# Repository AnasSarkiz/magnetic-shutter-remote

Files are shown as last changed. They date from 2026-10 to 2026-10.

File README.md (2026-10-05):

# Magnetic shutter remote R8 — ESP32-C3 migration qualification

**Codex Cloud continuation:** use branch `cloud/r8-cloud-setup`; read [cloud setup](cloud/SETUP.md) and the complete [project handoff](cloud/HANDOFF.md). Source, imported models, relevant manufacturer evidence, exact qualified archives and frozen generated Nordic JSON are included. Heavy builds are Linux-only and never started by setup.

Private Cloud environment **magnetic-shutter-remote-r8** is published: choose Work in → Cloud → that environment. Actual hosted setup/smoke passed with10 focused tests; observed32 GiB/4 CPUs. See the [environment record](cloud/ENVIRONMENT-RECORD.json), [current setup status](cloud/STATUS.md) and [continuation prompt](cloud/TASK-PROMPT.md). This local chat does not automatically move to Cloud, and environment readiness does not close board qualification gates.

**COMPONENT QUALIFICATION BLOCKED — NOT FOR FABRICATION.**

User-selected module: Espressif ESP32-C3-WROOM-02-N4 / JLCPCB C2934560. This isolated revision starts from `../magnetic-shutter-remote-r7--01a0f81f`, branch `r7-shutter-only-order-review`, commit `636d2b24eb4db775fceeb81206541f249db3b9a5`. Frozen R6 commit is `77965a8012d5544e962d987ce958c5c5614dbe3a`. Neither previous directory was modified.

The root `index.circuit.tsx`, `src/remote-circuit.tsx`, BOM and mechanical files remain the starting Nordic design. **They are not an implemented ESP32-C3 board.** Building that entry point does not validate R8. No R8 placement, routing, fabrication export or ordering approval exists. No torch is included.

Completed independent work:

- Supported, unchanged JLCPCB imports of the selected module and proposed TPS63031DSKR / C15516 regulator.
- All 19 module pin identities checked against Espressif; all 27 imported pad features match original supplier geometry.
- Isolated native A4 schematic, PCB and 3D import fixture rendered with routing disabled.
- ESP32-C3 Zephyr BLE HID firmware port compiled; valid image checksum verified. GPIO assignment remains proposed until a qualified board exists.
- Five focused qualification tests and TypeScript/format checks; these are not whole-board DFM tests.
- Documented power/battery feasibility and original-revision preservation manifest.

The blocking discrepancy is documented in [issue 075](tscircuit-issues/075-esp32-c3-supplier-lands-differ-from-espressif-recommendation.md): supplier outer lands are approximately 2.0 × 1.0 mm, versus Espressif's recommended 1.5 × 0.9 mm. The importer faithfully preserves them. This is an unqualified supplier variation, not a proven importer scaling bug or a proven assembly failure. Workspace instructions prohibit silently altering the import and require dependent work to stop. [Issue 076](tscircuit-issues/076-numeric-supply-pin-not-inferred-as-power.md) records missing inferred supply metadata separately.

Reproduce independent checks from this directory:

```sh
bun install --frozen-lockfile
python3 scripts/audit-r8-module.py
python3 -m unittest discover -s tests -v
./node_modules/.bin/tsc --noEmit
bun run format:check
./node_modules/.bin/biome format tests/fixtures/esp32-import.circuit.tsx
./node_modules/.bin/tsci build tests/fixtures/esp32-import.circuit.tsx --pcb-png --pcb-svgs --schematic-svgs --3d-png
```

Fixture output: `dist/tests/fixtures/esp32-import/`; this is not a remote-board build. See [VALIDATION.md](VALIDATION.md), [power feasibility](evidence/R8-components/POWER-FEASIBILITY.md) and [firmware instructions](firmware/README.md). Versioned SHA256 manifests identify the independent source/tooling/firmware evidence. Frozen original generated circuit JSON is under `baselines/r7/dist/index/circuit.json` and `baselines/published-main/dist/index/circuit.json`. No validated ESP32 R8 root circuit JSON exists; public board publication remains blocked rather than presenting copied Nordic output as ESP32-C3.

Next gate: independently qualified supported import of the exact selected module, or authoritative qualification of the larger supplier lands. Then complete regulator/passives/harness qualification, power/boot/programming circuitry, enclosure fit, pre-routing checks, routing and manufacturing exports. Physical battery, RF, thermal, runtime, enclosure fit and phone testing remain **POST-PROTOTYPE PHYSICAL VALIDATION**.

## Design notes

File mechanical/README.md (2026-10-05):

# Original remote and grip — R6

This is an original design, not a replacement for JJC internals. Dimensions and provenance are in [dimensions.json](dimensions.json) and [current R6 drawing](../fabrication/R6/BOARD-DIMENSIONS.pdf). The editable OpenSCAD source and seven exported STL part types are included.

PCB: 36 × 56 × 1 mm, R2 corners, two layers, all 37 fitted electronics TOP. Remote body: 40 × 60 × 16.8 mm, R3, 1.2 mm walls; maximum slider width 42.4 mm and button height 17.5 mm. Grip: 68 × 108 mm, R16; base thickness 6.5 mm, overall height with rails 9.8 mm. Docked remote body reaches Z=23.6 mm, buttons Z=24.3; the external steel plate reaches Z=-0.5, so the plate-to-button stack is 24.8 mm. These are compact engineering allocations around qualified parts, not a proven global minimum size.

Board datum: XY centre, +Y toward USB; outer back Z=0, PCB bottom 5 and top 6. Ø2.2 mounting holes are at (±13,24). HCTL USB anchor (0,23.25), 180°, mates +Y. Mouth Y=28.0601694; front opening 12 × 7 at (0,29,8). Its 3.31 mm maximum body height leaves 2.19 mm upper opening clearance at nominal board height. Both plug orientations have independent CC pull-downs. Intended cable plug envelope 10 × 6.5 is an allocation, not a guarantee for every cable.

Battery DTP401525(PHR) maximum 15.5 × 27 × 4.2 lies at X±7.75, Y−5.7…21.3, bottom Z=8.3, maximum top 12.5. Carrier floor Z=7.9…8.3 has thermal and C8 reliefs. Tabs have actual inner faces X±8.3: 0.55 mm side gap, or 0.35 mm after a chosen 0.2 mm printing allowance. Do not clamp the pouch. Carrier position/insulating shims establish the bottom datum after measuring the real pack. C8 max 1.45 mm gives 0.85 mm battery gap; subtracting a 0.3 mm board-height and 0.2 mm carrier allowance leaves 0.35 mm. Other low-profile electronics are below the carrier; nominal model/body reviews are not measured assembly results.

TMP390 maximum top Z=6.6 gives a 1.7 mm sensor-to-cell gap. The external 2.032 mm BERGQUIST pad gives 16.3% nominal compression; contact pressure and thermal lag still require hardware tests. PH mated height 5.5 gives lid gap 4.1; SH mated height 6.3 gives lid gap 3.3. Actual wiring and insertion access are reserved in CAD; J3 is serviced with lid removed. J2 intentionally mates inside the cavity toward −Y, so its generic board-edge orientation warning is accepted.

Shutter/pair switches at (−13.5,−7)/(13.5,−4) have 0.2±0.1 mm stroke, 2 mm nominal height. TPU plunger free gap 0.2 mm, stem 6.6 mm, Ø5.8 cap in Ø6.2 lid hole. Power switch at (15,5), 90°, has 1.6 mm travel and a Ø/width 1.3 actuator captured by a 1.7 mm fork. Button compliance, assembly-height adjustment, force and fatigue are prototype tests.

Remote centre in dock Y=−42, back Z=6.8. The stop was corrected to centre Y=−10.9: actual near face −11.7, 0.30 mm from the remote end −12. Rails inner width 40.6 gives 0.3 mm side gaps. A 0.2 mm print allowance leaves only 0.1 mm, so physical sliding/retention must be checked. Magnet top plus cap is Z=4.675, 0.325 mm below nominal PCB bottom. Two remote and two dock magnets plus four phone magnets are external K&J D42 items, retained with insulating caps/adhesive. Screws and magnet positions avoid the pouch/antenna region.

All-layer no-copper antenna strip: X±18, Y−28…−22.9. Detached battery separation is 17.2 mm; closest reserved wire (radius 0.6) is 16.6 mm. In dock, antenna Y−70…−64.9; permitted phone bottom at Y−35±5 yields 24.9 mm to the nearest phone metal. Fifteen millimetres is our engineering target; Ebyte supplies qualitative metal-clearance guidance, not that numerical rule. Use unfilled nonconductive plastic. Phone alignment and docked/detached RF performance require hardware evidence.

Fit evidence: final STL meshes are manifold/NoError; actual tab/stop surfaces were measured in [mesh evidence](../evidence/R3/final-mechanical-mesh-measurements.json). Native tscircuit PCB/3D, cutaway, docked envelopes and four dimensioned sheets were inspected. No physical battery, swelling, wiring, connector, button, slider, magnet, RF or enclosure test has passed.

R6 USB migration: GCT USB4215-03-A Rev A; anchor(0,23.9852), TOP180°, actual centroid(0,24.5101989). Opening12×9.5atY29/Z8; nominal matingfaceY28.6601694, mouthaxisZ7.48. Manufacturer bodymax9.19×6.75×3.41 and compliant-plug envelope produce calculated worst verticalgap0.08, horizontalgap1.105, shoulder margin0.3601694 and battery-bodygap0.2101694mm. See `../evidence/R6/usb-mechanical-fit.json`; print/PCB/location allowances are engineering allocations, not measured process capability. Current cutaway/docked PNGs and STL base regenerated; other enclosure/rail geometry unchanged. Physical fit remains pending.

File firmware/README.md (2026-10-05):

# R8 ESP32-C3 firmware preparation — compiled, hardware untested

This is a platform adaptation of the R6/R7 Zephyr shutter application for the exact ESP32-C3-WROOM-02-N4. It is **not** an image for the frozen Nordic board. The generated image and ELF are preserved in `artifacts/R8-candidate/`. Hardware footprint qualification is blocked; the pin contract below is proposed, not final routed-board registration. A compiled image is not permission to order or a verified image for an assembled R8 PCB.

The retained BLE HID Consumer Control report sends Volume Increment (`0xE9`), one press followed by release after 60 ms. It retains encrypted notifications, one stored bond, a three-second pairing-button hold, bounded advertising windows, debounce, and disconnect on a stalled release. No queued shot is replayed on reconnect. Wi-Fi and unused development-board interfaces are disabled. No measured connected-sleep current, runtime, or phone compatibility is claimed.

| Function | GPIO | Module physical terminal |
|---|---:|---:|
| Shutter, active low | 4 | 3 |
| Pair, active low | 5 | 4 |
| Red status LED, active high | 6 | 5 |
| UART programming RX | 20 | 11 |
| UART programming TX | 21 | 12 |
| Download strap | 9 | 8 |
| Enable/reset | EN | 2 |

GPIO2 and GPIO8 must be held high for documented download-mode entry; GPIO9 must normally be high and low for download. These are electrical requirements for the future schematic, not connections already implemented here. The planned UART header carries VREF, TX, RX, GND, EN and BOOT; its actual pin order must be frozen with the PCB before programming instructions are approved. A UART adapter must use 3.3 V logic and must not drive battery power. The single USB-C remains the charging port; no second USB port or fill light is added.

The official Zephyr v4.2.0 `esp32c3_devkitc` target includes `esp32c3_wroom_n4.dtsi`. Its preserved definitions are in `../evidence/R8-components/zephyr-v4.2.0/`. The local overlay replaces the development-board GPIO9 button with GPIO4 and adds GPIO5/GPIO6 controls. The exact framework/module commits, source hashes and artifact hashes are in `artifacts/R8-candidate/BUILD-MANIFEST.json`. The build uses Zephyr SDK 0.17.2, RISC-V GCC 12.2.0, CMake 3.31.10, Ninja 1.13.0, west 1.5.0 and Python 3.14.7. Python dependencies are locked in `requirements-lock.txt`. SDK archive hashes are preserved in `sdk-download/sha256.sum` and the component integrity manifest.

Reproduce from the project root:

```sh
python3 -m venv firmware/.venv
firmware/.venv/bin/python -m pip install -r firmware/requirements-lock.txt
git clone --depth 1 --branch v4.2.0 https://github.com/zephyrproject-rtos/zephyr.git firmware/deps/zephyr
firmware/.venv/bin/west init -l firmware/deps/zephyr
cd firmware/deps
../.venv/bin/west update --narrow hal_espressif mbedtls
../.venv/bin/west blobs fetch hal_espressif
cd ../..
PATH="$PWD/firmware/.venv/bin:$PATH" ZEPHYR_SDK_INSTALL_DIR="$PWD/firmware/zephyr-sdk-0.17.2" sh firmware/build.sh --cmake
```

Install the official SDK minimal macOS-arm64 archive plus `riscv64-zephyr-elf` archive into the recorded task-local directory before the build; check both against the SDK release's published SHA256 sums. Do not run SDK registration that changes unrelated user configuration. On another host, select the corresponding official host archive and record its hash.

**Build status: PASS, 2026-10-05.** The final build exits 0 and Espressif esptool v4.8.1 identifies a valid ESP32-C3 image checksum. Image size is 411,568 bytes; linked flash usage is 411,568 bytes, DRAM 129,776 bytes, IRAM 64,016 bytes. Original failed SDK/dependency download/build attempts and the final successful log are preserved under `../evidence/R8-components/`.

The build reports optional external DTC absent; Zephyr's Python devicetree generation succeeds. The bundled esptool emits a Python 3.14 SyntaxWarning for a `return` in `finally`; its image generation and independent image checksum verification succeed. Neither warning was suppressed or patched. Tickless idle is enabled and Wi-Fi is disabled, but CPU power-management and controller sleep are not established for this C3 build. Low-power performance remains an explicit unfinished software/measurement item; do not quote connected-idle or deep-sleep currents from the silicon datasheet as this firmware's measured result.

Acceptance remains native iPhone Camera and representative Android camera testing on identified phone/OS/app versions, including press/release, reconnect, bonding reset and locked-screen behavior. This is **POST-PROTOTYPE PHYSICAL VALIDATION**.

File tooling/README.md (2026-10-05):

# R3 working tooling and reproducible integration

All changes are local and unpublished. The project stays tscircuit source; no KiCad authoring or viewer is required for R3. Exact seven upstream base commits, source versions, changed files, untracked regression fixtures and patches are in [revisions.json](revisions.json). The complete edited sources/locks are included; patches alone omit untracked fixtures, so use supplied source directories as the complete record.

## Working dependency identities

Board Bun 1.3.9; tscircuit 0.0.2702 / CLI 0.1.2212; TS 5.9.3; Biome 2.2.4. Exact dependency graph is in the board lock. Active core is **vendor/tscircuit-core-0.0.2035-r3-attribution.tgz**, together with schema 0.0.509-r2-sheet, util 0.0.117-r2-orientation and capacity autorouter 0.0.951. Installed core bytes match the canonical tested build. Historical archive filenames remain evidence, not active dependencies.

Supported Gerber source converter is 0.0.109 base 40dbb6c0ebae9c63ef5a52292e8521de6060c548 plus the local inline G85/G05 correction. Upstream already fixes M48 header placement. The older CLI-bundled 0.0.104 is not treated as fixed by root overrides; use the explicitly built canonical converter. Its full suite passes 172 tests/1640 assertions after actual TOP/BOTTOM snapshot review, with original snapshots retained. No exported Gerber/drill edits are used.

Native browser evaluation uses eval 0.0.1506-r3-attribution with the same locked source engine, and runframe 0.0.2883 with a matching packaged-worker resolver plus compatible props 0.0.672. The canonical eval build and runframe CSS/standalone targets pass; focused packaged-worker test passes. Other runframe targets/full browser suites are not claimed passed. Corrected standalone min.js is included so the native project viewer does not silently use the old CDN evaluation engine.

## Restore and build

Use `bun install --frozen-lockfile` in each source directory before its canonical build. Local archives in `../vendor/` are already supplied; dependencies may require network. Core's schematic solver archive 0.0.217 is supplied and locked. Run source commands within their own package directory, not workspace root.

```sh
# Board root
bun install --frozen-lockfile
bun run format:check
bun run typecheck
bun run test

# Supported converter (run here to regenerate its dist before exports)
cd tooling/circuit-json-to-gerber
bun install --frozen-lockfile
bun run build
bun test
```

Focused core regression commands from tooling/core (exact tests, before/final logs and fixtures are linked in issues 021–023, 028, 031 and 035):

```sh
bun install --frozen-lockfile
bun test tests/repros/repro-saved-fanout-plated-terminal-bottom.test.tsx tests/repros/repro-saved-fanout-smt-terminal-wrong-layer.test.tsx tests/repros/repro-routed-trace-between-saved-fanouts.test.tsx
node_modules/.bin/tsc --noEmit
bun run build
```

Use actual package scripts in the saved package.json; earlier full-core suite timeouts remain evidence and are not a passed full suite. Meaningful focused tests and builds are passed. No regression was removed or weakened.

To rebuild the native viewer, run eval's full canonical `bun run build` from tooling/eval, then run `bun run build:css` and `bun run build:standalone` from tooling/runframe with its frozen lock. The eval prebuilt archive is already matched to the locked core; a changed build requires a new archive identity and updated lock, never overwriting evidence. From the board root:

```sh
RUNFRAME_STANDALONE_FILE_PATH="$PWD/tooling/runframe/dist/standalone.min.js" node_modules/.bin/tsci dev --port 3026
```

Reload the existing tab after changing the packaged evaluation worker. Watch exclusions omit tools/research/output files, not validation checks. Keep a captured server log outside the watched project to avoid recursive recompilation. Final source viewer PCB and 3D were inspected; PCB shows zero errors.

Importer is supported easyeda-converter 0.0.364 base 140046d000238f3d6c8611989682efb2872f25a9, with validated topology/mating/ref-label/declared-slot fixes. `scripts/regenerate-qualified-imports.sh` preserves original raw payloads and regenerates via its CLI. HCTL import was separately regenerated through that corrected CLI and not edited. Manufacturer geometry, pin mappings and imports remain unchanged.

Independent CAM uses Python 3.14.7 with the pinned `gerber-review-requirements.txt`, including Gerbonara 1.5.0, pcb-tools 0.1.6 and Shapely 2.1.2. Create task-local gerber-review-venv; no virtual environment is archived. Gerbonara's G85 limitation remains, while pcb-tools reads the original exported slots/rounds directly; no syntax normalization is used. OpenSCAD/ReportLab generate mechanical outputs, not electronic symbols or footprints. OpenSCAD needed host execution on this Mac because its sandbox launch aborted; the actual successful native mesh/render logs are saved.

[Current hashes](../evidence/R3/current-source-tooling-hashes.json), [validation scope](../VALIDATION.md), [all local issue reports](../tscircuit-issues/README.md) distinguish project mistakes, supplier deviations, external readers, manufacturing limits and confirmed tscircuit bugs. Archive manifests exclude dependency folders, Git/account metadata and raw signed supplier listing HTML; safe qualified sourcing JSON and original public raw library/footprint inputs remain.

---

# R2 local tooling fixes and reproduction

All changes are local; no packages, commits, issues or PRs were published. `revisions.json` gives upstream commit IDs and changed/new files. Complete editable source directories and binary patches are included; patches alone omit untracked new test files, which are present in those directories. Original R1 supplier imports are under `evidence/R1-original-imports/`.

## Locked packages

Board: Bun 1.3.9, tscircuit 0.0.2702, TypeScript 5.9.3, Biome 2.2.4; exact transitive graph in the board `bun.lock`. Local archives:

- core 0.0.2035 + R2 fixes: `vendor/tscircuit-core-0.0.2035-r2-paste.tgz`.
- circuit-json 0.0.509 + sheet metadata schema: `vendor/circuit-json-0.0.509-r2-sheet.tgz`.
- circuit-json-util 0.0.117 + orientation classification: `vendor/tscircuit-circuit-json-util-0.0.117-r2-orientation.tgz`.
- easyeda-converter 0.0.364 source + R2 supported conversion options and slot fix, with its own lockfile.

Official converters: circuit-json-to-bom-csv 0.0.19, circuit-json-to-pnp-csv 0.0.16 and CLI-bundled circuit-json-to-gerber 0.0.104. These are used directly, with no hand-created fabrication substitutes. Root overrides apply corrected packages consistently. Installed core binary hash was compared with the tested build; see installed-package-hashes.json. Earlier install failures are historical, not accepted install evidence.

## Fixes and regression evidence

- Importer `conversion-options.ts` / CLI: validated SPDT and insertion-direction options. Switch classification excludes thermostats; USB connectors retain original symbols and pin arrangements. No supplier data is rewritten.
- Custom symbol generation includes dynamic reference labels. Core associates reference text outside the symbol's nominal bounds with its true owning component. Repeated physical pads merge correctly with logical custom-symbol ports; port selectors round-trip through the routing cache.
- EasyEDA OVAL drills consume the declared `holeLength` field. Five focused tests cover unequal annular margins, four rotations and circular holes inside oval copper. RECT plated-hole inference is unchanged and is not exercised by fitted parts here.
- Core optional hole fields and display offsets conform to the schema. Sheet display_name/centre metadata survives schema parsing.
- Orientation utility quantizes inferred orientation coordinates at 1 µm for classification only; raw geometry is unchanged. Rotation tests preserve rejection of real 0.01 mm staggering.
- Core no longer creates unrequested stencil apertures on either side of plated holes. Explicit paste primitives remain supported; board shell solder process is not invented.

Importer full suite: 308 pass / 77 snapshots. Schema: 400 pass. Orientation utility: 141 pass. Final core focused regressions: four pass, plus earlier repeated-pad test. Core full suite was not run. Before/after logs and visually reviewed snapshots are in evidence/R2 and the source test directories.

## Build from editable source

Each source directory has its own lockfile. Restore dependencies with `bun install --frozen-lockfile` from that directory, then use its canonical scripts (`bun run build`, `bun test`, `bunx tsc --noEmit`; core uses selected repro tests). Core depends on the task-local `../vendor/schematic-trace-solver-0.0.217.tgz` recorded in its package configuration. Task-local dependency folders were cleared after tests to recover disk space; this does not remove source or locks.

The board uses the supplied prebuilt local archives. To reproduce a modified local build, use `bun pm pack --destination ../vendor` from the package source directory, give the archive a new task-local filename, update the board's dependency/override to that archive, and run `bun install`. Do not overwrite an archive already identified by the evidence manifest or hand-edit installed package files.

From the board root, regenerate affected supplier components with:

```sh
sh scripts/regenerate-qualified-imports.sh
```

This invokes the actual corrected importer CLI against preserved raw supplier payloads. It is not a generated-import patcher. The unchanged passive/module imports remain their original supported imports. Network may be needed for supplier model metadata.

Board build/check/export commands are in the root README, validate-r2.py, export-assembly.ts and fabrication/README.md. The independent Gerber review environment uses `gerber-review-requirements.txt`. Its G85 limitation is explicitly recorded; it never rewrites manufacturing files. OpenSCAD and ReportLab generate mechanical deliverables, not electronic footprints.

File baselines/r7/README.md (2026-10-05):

# Magnetic shutter remote — R7 shutter-only order review

Torch / fill light work is cancelled. The active board remains the proven frozen R6
shutter electronics; no torch circuit is fitted. R6 is untouched.

**Local electrical and CAM checks pass. JLCPCB processed preview must be reviewed before payment.**

Use `index.circuit.tsx`, with generated `dist/index/circuit.json`. Reproduce with
`bun install --frozen-lockfile`, `bun run format:check`, `bun run typecheck` and the
native board build/check commands. See [tooling](tooling/R7-README.md),
[validation](VALIDATION.md), [order review](evidence/R7-order-review/ORDER-READINESS.md),
[current order files](fabrication/R7-order-review/README.md), and
[issue register](tscircuit-issues/README.md).

The complete suite is not claimed passing: one historical preservation failure and one
missing-input skip remain. All original R6 recorded files are unchanged. Physical tests
remain **POST-PROTOTYPE PHYSICAL VALIDATION**. This is an untested engineering prototype,
not production-qualified hardware or a completed shoulder-button enclosure.

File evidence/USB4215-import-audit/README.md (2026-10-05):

# USB4215 replacement qualification — isolated toolchain audit

**USB4215 — BLOCKED. R5 DFM REVIEW — NOT FOR FABRICATION.**

No R6, migration implementation or fabrication-candidate ZIP. All972 protected files remain unchanged (556 R5 +416 R4); previous replacement-search evidence remains unchanged. Physical battery, RF, thermal, runtime, enclosure-fit and phone tests remain **POST-PROTOTYPE PHYSICAL VALIDATION**; those are separate from the open pre-fabrication process requirements.

## Source identity and preserved evidence

GCT / Global Connector Technology USB4215-03-A, JLCPCB/LCSC C37616412. Official drawing/spec revision A, 2024-04-26. Supplier componentUUID 907b9bea7a60481d8a3d3aef3cba8ef1; packageUUID 3104977db58742e399663286e4a66eac, library title USB-C-SMD_GT-USB-7010B. The borrowed title/link is disclosed; supplier import success is not GCT approval. See [identity and hashes](source-identity.json), [unchanged raw source](inputs/C37616412.raweasy.json), [original generated import](inputs/original-import.tsx), [current import](final/USB4215_03_A.tsx) and [frozen-search ledger](frozen-search-ledger.json).

The official drawing's copper/drill qualification is preserved in the [previous search](../USB-replacement-search-2026-10-03/continued-search/README.md); this run does not overwrite it or infer new tolerances. [JLC stock record](stock-2026-10-03.json) checked 2026-10-03:145 stock,63 available,Extended, SMT Assembly, Economic/Standard, MSL1. Availability can change. The exact page does not confirm soldering coverage/process for the four plated shell anchors.

## Exact paste loss and corrected chain

| Stage | Expected source paste shapes | Baseline observed | Corrected observed | Result |
|---|---:|---:|---:|---|
|Raw EasyEDA/LCSC source |16 |16 |16 | source retained |
|Parsed representation |16 |16 |16 | parser retains SOLIDREGIONs |
|Direct importer Circuit JSON |16 |0 |16 | local generic fix |
|Generated tscircuit component |16 |0 |16 | explicit native polygons |
|Rendered Circuit JSON |16 |12 automatic defaults |16 source polygons | no duplicates |
|TOP paste Gerber |16 |12 default rectangles |16 source regions | independent CAM pass |

The first exact discard is the converter's SOLIDREGION dispatch: filled layers5/6 are not emitted. Layer mapping itself is not the cause. PAD paste/mask expansion is also discarded. Downstream polygon schema/props/native primitive/viewer/export support was missing. The focused additive fix preserves all original M/L polygon vertices; unsupported curves, compound/open paths fail explicitly rather than being silently approximated.

Twelve contact apertures  + four shell apertures survive. Raw negative contact paste expansion suppresses the former automatic rectangles. Supplier mask expansion 0.0508 mm is retained on all16 lands; actual TOP mask's24 drawing commands composite to 16 physical openings. Source geometry is preserved exactly, including small source offsets and segmented capsule contours. [Per-aperture table](APERTURE-GEOMETRY.md) and [actual Gerber](final/F_Paste.gbr) show maximum contour error 0.000000565686 mm from six-decimal quantization. Native and actual-CAM [previews](final/) were visually inspected; geometry was independently measured.

## Validation and working versions

| Check | Result | Evidence |
|---|---|---|
|Minimal importer geometry regression |pass ; 1,255 assertions |[focused tests](logs/focused-importer-final.log) |
|48 existing source fixture margin/contour checks |pass ; 6,430 assertions |same log |
|Core placement/reflection/routing/default-paste tests |4 pass,0 fail ; 107 assertions |[core log](logs/focused-core-policy-aligned-final.log) |
|Util polygon/outline transform |pass |[util log](logs/focused-util-final.log) |
|Gerber polygons, both layers/Y conventions |pass |[Gerber log](logs/focused-gerber-final.log) |
|SVG polygon/viewer snapshot |pass |[SVG log](logs/focused-svg-final.log) |
|Actual source→JSON→CAM contours and mask |2pass |[CAM log](logs/cam-final-locked.log) |
|Actual four plated slots |pass with pcb-tools; no drill rewrite |[slot log](logs/slots-native-reader-final.log),[measurements](final/slot-readback.json) |
|Seven library/declaration builds |all pass |[build results](logs/qualified-build-results.json) |
|Locked fixture typecheck/render |pass;16paste,0Circuit errors |[typecheck](logs/fixture-nested-routing-typecheck.log),[render](logs/fixture-nested-routing-render.log) |
|Clean separate-directory reproduction |18 files match except CAM creation times |[results](reproduction-with-slots/reproduction-results.json) |
|Full importer suite |**blocked:278 pass/33 fail**,311 tests |[full log](logs/importer-final-qualified-suite.log) |
|Unchanged-source paired control |237 pass/72 fail,309 tests;33 common failing names |[control log](logs/baseline-final-qualified-suite.log),[comparison](logs/suite-comparison-final-qualified.json) |
|ProtectedR4/R5 files and previous search |972 + 82 files unchanged |[preservation](preservation-after.json),[search](frozen-search-verification.json) |

Name parity does not waive the full-suite failures or prove every general import is release-ready. Exact remaining cases/logs are [retained](logs/unresolved-suite-failures.json). Source-backed inline/strict expectations were reviewed before update; stripping only new paste/mask content leaves all previous symbol/copper content unchanged. A 48-component raw-source test independently checks the additions. Original tests/inputs and failing logs remain preserved. No snapshot-difference threshold, manufacturing check, compiler strictness or source validation was weakened.

Local package baselines: easyeda 0.0.364, circuit-json 0.0.509, props 0.0.672, util 0.0.117, core 0.0.2035, Gerber 0.0.109, SVG 0.0.433. Runtime pins: tscircuit 0.0.2702, eval 0.0.1506, checks 0.0.232, footprinter 0.0.426, React 19.2.1, TypeScript 5.9.3, zod 3.25.76, Bun 1.3.9. Root router 0.0.951 is a direct dependency; fanout 0.0.78 retains its own router 0.0.718. A blanket override was removed after compiler evidence demonstrated incompatibility. [Manifest/lock](fixture/), [source ledger](source-change-ledger.json), [built-package/source hashes](working-dependency-manifest.json), [reproduction commands](REPRODUCE.md).

All working imports/JSON/CAM were regenerated through corrected supported tooling; no generated component, Circuit JSON or Gerber was manually patched. The 20 × 18 mm unrouted fixture is an inspection carrier, not a proposed new remote PCB. Its 11 CAM files do not replace the protected R5 board's 12 CAM files.

## External qualification remains blocked

[Paste qualification](../USB4215-PASTE-QUALIFICATION.md): supplier footprint fidelity verified; **manufacturer paste/mask/stencil qualification missing**. Contact/shell source apertures are not automatically approved paste volume for a 1 mm board. No official exact-series stencil thickness, reductions, shell overprint volume or mask strategy was found.

[Process qualification](../USB4215-SOLDER-PROCESS.md): GCT specification A section 7.0, p6 publishes a reflow heat-resistance evaluation: ramp 2.5 °C/s, soak 2–3 min, above 217 °C for 60 s, above 230 °C for 50 s, above 250 °C for 5 s, peak 255–260 °C, cooling maximum slope −5 °C/s. Allowed heating-cycle count and exact shell method/secondary solder permission, iron time/temperature and repeats remain undocumented. General GCT PIP guidance and the 245 ±5 °C / 3–5 s solder-pot test do not qualify this exact process.

Four plated shell slots are geometry-verified, with source paste present, but intended solder method and JLCPCBA coverage/special services remain unconfirmed. The exact-part SMT-eligible listing is insufficient to certify all shell anchors are soldered. [Concise GCT/JLC questions and supporting drawings](UNSENT-QUALIFICATION-QUESTIONS.md) are prepared only; **nothing sent, uploaded, ordered or published**.

USB4215 is **BLOCKED**, not rejected and not a QUALIFIED R6 CANDIDATE. All required conditions are not met; no migration plan or R6 is created. USB4216/C47635969 remains **HOLD — ZERO STOCK / UNSUPPORTED CAD MODEL**, without custom CAD.

## Local issue record

[Issue index](tscircuit-issues/README.md) retains the original053 and adds its local-fix status, PAD paste loss054, outline transform055, PAD mask loss056, project dependency integration057 and stale local test058. Supplier approval gaps are not labelled tscircuit bugs. No GitHub issues or packages were published.

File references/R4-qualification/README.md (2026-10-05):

# Authoritative-document search and preserved copies — 2026-10-02

This review preserves the original R4 archive. New copies, extracted text and hashes identify what was actually reviewed; source URLs do not imply that a manufacturer endorsed the project. No supplier was contacted and no account-specific download query or credential is retained.

| Source checked | Result / precise scope |
|---|---|
| [HCTL footprint-linked PDF](https://atta.szlcsc.com/upload/public/pdf/source/20210915/3D150CAC3AF135AC4AAC41D1BD8153AB.pdf) | Saved `HCTL-supplier-linked-20210915.pdf`: A0, T16-000X, 2017-02-24, one page marked 1/1. Visually reviewed; image-only extraction is not used to invent dimensions. |
| [Exact LCSC newer HCTL PDF](https://wmsc.lcsc.com/wmsc/upload/file/pdf/v2/lcsc/2211161000_HCTL-HC-TYPE-C-6P-01A_C2894893.pdf) | Earlier copy `../C2894893-manufacturer.pdf`, Rev A, one supplied page marked 1/2. The two recommended copper-width drawings agree. Neither specifies a stencil or solder thermal profile. |
| [Official HCTL USB catalog](https://hctldz.com/product?classtype=15) | Reviewed manufacturer catalog. No additional exact-MPN solder-profile or land-pattern-variation drawing located. Absence in the documents searched is not proof no internal qualification exists. |
| [Exact JLC part listing](https://jlcpcb.com/partdetail/HC-TYPE-C-6P-01A/C2894893) | Identity and SMT/Economic/Standard assembly fields corroborated; library identity extracted from saved raw supplier input. Cached search stock is not a fresh stock reservation or a replacement for dated sourcing evidence. |
| JLC public datasheet object `smtDataManualFile/8588944637717725184-C2894893.pdf` | Current linked download could not be retrieved: HTTP 403. Unsigned stable-path retry also returned 403. No inaccessible page is claimed reviewed, no signed query is saved, and no missing second page is assumed. |
| Exact-MPN searches: `"HC-TYPE-C-6P-01A" reflow solder HCTL` and exact-MPN datasheet/PCB/solder limited to hctldz.com, lcsc.com, jlcpcb.com | Located the existing exact supplier listings and their drawings, without an additional authoritative process/profile or wider permissible copper range. Secondary seller pages were not used to qualify geometry or temperature. |
| [TI current BQ25185 datasheet](https://www.ti.com/lit/ds/symlink/bq25185.pdf) | Saved `BQ25185-current.pdf`: SLUSF65B, August 2026, 32 pages. Package/land/stencil pages 29–31 inspected. §7.4.1 solid-plane requirement separately recorded as issue 044. |
| [TI referenced attachment guide](https://www.ti.com/lit/an/slua271c/slua271c.pdf) | Saved `TI-SLUA271.pdf`: SLUA271C, December 2023, 21 pages. §4.2–4.4 distinguish typical paste coverage, aperture release ratios and process-dependent guidance from exact-example equality. |
| [JLC PCBA capabilities](https://jlcpcb.com/capabilities/pcb-assembly-capabilities) and [service overview](https://jlcpcb.com/pcb-assembly) | Mixed SMT/THT and secondary process classes exist. Standard handling minimum 70×70 mm, rails/fiducials required; generic service reflow values do not qualify HCTL temperature limits. No exact-board panel or connector-joint acceptance is established. |
| [JLC stencil preparation](https://jlcpcb.com/help/article/smt-stencil-data-prepared-for-smt-orders) and [pin-in-paste guide](https://jlcpcb.com/blog/pin-in-paste-through-hole-reflow-stencil-guide) | Engineering workflow/process prerequisites reviewed; neither approves this project's actual aperture/foil combination or unpasted shell stakes. |

Hashes, lengths, ZIP integrity and protected-file continuity are in [review manifest](../../evidence/R4-qualification/review-manifest.json). Extracted `.txt` files are unedited Poppler output. Numerical conclusions, equivalent-dimension tables and missing-information subgates are in [USB qualification](../../fabrication/USB-LAND-QUALIFICATION.md), [charger qualification](../../fabrication/CHARGER-STENCIL-QUALIFICATION.md) and [registration](../../fabrication/ASSEMBLY-REGISTRATION.md).

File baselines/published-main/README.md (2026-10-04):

# Magnetic shutter remote — frozen R6 / E1 enclosure

Untested engineering prototype: rechargeable Bluetooth camera shutter remote, 36 × 56 × 1 mm, two copper layers, 37 fitted TOP components. J1 is GCT USB4215-03-A / C37616412. E1 is an original magnetic enclosure with a passive status-light ring illuminated by the existing red PCB LED.

`index.circuit.tsx` is the board entry. `dist/index/circuit.json` is included deliberately. `enclosure.assembly.tsx`, `enclosure.remote.tsx`, `enclosure.cutaway.tsx` and `enclosure.exploded.tsx` are the native assembly views.

Install the locked toolchain with `bun install --frozen-lockfile`; build the board with `bun run build`; view with `bun run dev`. View the enclosure with `bun run dev enclosure.assembly.tsx`. Exact qualified dependency archives are included under `dependencies/`; CLI/eval are also pinned to immutable public GitHub archive URLs, because unpublished tooling fixes are needed to reproduce R6. They preserve supplier imports and are not substitute component definitions.

Physical battery, thermal, RF, runtime, phone and enclosure-fit validation remains pending. Production stencil/reflow and four USB shell-anchor process qualification remains pending; first-prototype manual shell rework may be required. Public availability is not fabrication approval. No board has been ordered.

Tscircuit: https://tscircuit.com/AnasSarkiz/magnetic-shutter-remote--01a0f81f

Frozen electrical source commit: `77965a8012d5544e962d987ce958c5c5614dbe3a`; E1 source: `4f75af5`. This compact repository contains runnable sources, CAD assets and generated Circuit JSON, without historical investigation files or unrelated scripts.

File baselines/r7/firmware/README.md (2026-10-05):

# Grip Shutter R6 firmware

**Built successfully, not run on a physical board or phone.** Zephyr 4.2.0 application for the E73-2G4M08S1C nRF52840. This folder includes the application and an original Zephyr board definition, not a substituted electronic component or footprint. Exact source/module revisions are in `toolchain.json`; Python dependencies are in `requirements-lock.txt`. Local SDK and virtual environment are not part of the deliverable source.

## Behavior

Bluetooth LE HID Consumer Control, usage page 0x0C, Volume Increment usage 0xE9, report ID 1. One-byte input payload: 0x01 press, 0x00 release. Report ID is carried by the Report Reference descriptor, not prepended to the GATT value. Press is followed by release after 60 ms; 30 ms debounce and edge detection prevent repeat while held. Failed release is retried; a stalled link is disconnected after one second to avoid a latched volume key. No stored shutter event is replayed after reconnect.

Power on: advertise for 120 s if unbonded; otherwise 30 s to the stored peer through an accept list. One bond is saved in NVS. Secure Connections Just Works with encrypted input/CCC is requested; no numeric-comparison or MITM authentication is claimed. Long-hold PAIR for 3 s to disconnect, erase the old bond and open a 120 s pairing window. A tap of SHUTTER after advertising times out starts reconnection; press again once connected to take a photo. A currently connected link stays connected; there is no inactivity disconnect. No keyboard text report, companion phone app or USB bootloader is supplied.

LED2 pulses during pairing/reconnect and on transmitted shots; repeated 100 ms on/off indicates a firmware fault. LED1 is driven by charger STAT and lights while charging; its going dark alone cannot distinguish full charge from absent USB or some faults. The design does not reproduce JJC's blue completion LED. SW1 is the hardware power control. USB insertion is intended to disable the radio through hardware. Calibrated 32 kHz RC, tickless idle, short advertising windows, disabled console/logging and no continuously lit status LED reduce idle load. No measured current or battery gauge is claimed.

## Reproduce the build

Prerequisites used locally: Python 3.14.7, west 1.5.0, CMake 3.31.10, Ninja 1.13.0, GNU Arm Embedded gcc 16.1.0. The GCC installation was already present at `/opt/homebrew`; no system SDK was installed by this project. Install an equivalent supported toolchain and set its path on another machine.

From the **board project directory**:

```sh
python3 -m venv firmware/.venv
firmware/.venv/bin/pip install -r firmware/requirements-lock.txt
git clone --branch v4.2.0 --depth 1 https://github.com/zephyrproject-rtos/zephyr firmware/deps/zephyr
firmware/.venv/bin/west init -l firmware/deps/zephyr
```

Run the module update from `firmware/deps` (the west workspace):

```sh
../.venv/bin/west update cmsis cmsis_6 hal_nordic mbedtls --narrow -o=--depth=1
```

Then from the board directory, set `GNUARMEMB_TOOLCHAIN_PATH` to your installed Arm toolchain and run:

```sh
GNUARMEMB_TOOLCHAIN_PATH=/opt/homebrew sh firmware/build.sh
```

The app uses the complete open Zephyr controller/host; there is no proprietary SoftDevice or bootloader image to combine. `firmware/artifacts/zephyr.hex` and `.bin` are copied from the successful build; `.elf` is retained for debug. Current build usage: **164660 bytes flash, 26796 bytes RAM**. The vector table starts at 0; settings occupy 0xF8000–0xFFFFF. Confirm against `evidence/R6/firmware-build.log` and the source/artifact hashes before programming. Full HID-over-GATT qualification, Device Information/PnP interoperability requirements, RF regulatory compliance and Bluetooth qualification remain open; compile success is not certification.

## Programming and debug — after hardware gates pass

Use SWD and a probe that supports nRF52840. J3 is a custom six-pin JST SH interface; it is **not** the standard ARM 10-pin cable pinout.

| J3 pin | Function | E73 pad / SoC |
|---|---|---|
| 1 | Vref 3.0 V, sense only | VDD pad 19 / VDDH 23 |
| 2 | SWDIO | 37 |
| 3 | GND | 5/21/24 |
| 4 | SWCLK | 39 |
| 5 | RESET_N | 26 / P0.18 |
| 6 | GND | 5/21/24 |

Verify connector cavity numbering and cable polarity from JST drawings before mating. Power the target from its regulated battery rail with USB disconnected and SW1 on; do not feed 3.3 V from the debug probe into Vref. First measure V3 and check shorts with a current-limited supply. Hardware is not yet cleared for this step.

Once a verified J-Link installation and target exist, the supported runner command from the board directory is:

```sh
PATH="$PWD/firmware/.venv/bin:$PATH" firmware/.venv/bin/west flash -d firmware/build --runner jlink
```

No flash operation has been attempted. Program/verify/read back the image and UICR reset configuration, reset and inspect advertising. A factory module may require an explicit recover operation if access protection is enabled; recovery erases firmware and bonds. Do not blindly recover another device. For debugging use the Zephyr `west debug` runner with the same build directory. USB-C carries charging power only.

Run the acceptance procedure in `../PHONE-TEST-PROCEDURE.md`, and record board revision, binary hash, phone/OS/app versions, actual pairing, current, reconnect and camera results. Never label untested versions compatible.

The unchanged, pinned SDK checkouts were cleared after the successful build to recover workspace disk space. Recreate them with the instructions above before rebuilding. Application source, locked module revisions, compiled HEX/BIN/ELF and generated configuration are retained.

R3 final pin-contract checks passed; rebuilt with the locked toolchain on 2026-10-02 (`evidence/R3/firmware-final-build.log`). No GPIO assignment changed from R2. HEX/BIN/ELF/config are in artifacts/. No hardware or phone test is claimed.

R6 rebuilt against the final board assignments with USBdataunused; unchanged GPIO/HIDlogic. Fresh deliverable HEX/BIN/ELFare in `artifacts/`; hashes in `evidence/R6/firmware-artifact-manifest.json`. This is build validation only; phone compatibility, programming, RFand current consumption remain POST-PROTOTYPE PHYSICAL VALIDATION.

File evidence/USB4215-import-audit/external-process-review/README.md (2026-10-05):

# USB4215 external process review — 3 October 2026

**R5 DFM REVIEW — NOT FOR FABRICATION. USB4215 — BLOCKED.**

This is documentation and external-request preparation only. No PCB source, imports fitted to R5, board dependencies, placement/routing, firmware, mechanics or protected artifact changed. No R6, broad connector search, board build, broad DFM/regression rerun, supplier contact, order, upload or publication. The current explicit no-publication instruction governs this task; the standing board-step publication rule is not used to publish this isolated tooling archive or the board.

## Deliverable and integrity

[GCT-USB4215-JLCPCB-QUALIFICATION.zip](../../../deliverables/GCT-USB4215-JLCPCB-QUALIFICATION.zip), version `external-review-1`: 810,964 bytes, 19 members, including an internal manifest covering the other 18 members.

SHA256: `71abc2821e06eea53da3ba5900c5eb08db2272a7b49e33b53d7584f052c6c9f6`

**ENGINEERING QUALIFICATION ONLY — NOT FOR FABRICATION.** [Package record](PACKAGE-RECORD.json), [member index](package/README.md), [verification results](VERIFICATION.json). The package includes only exact manufacturer PDFs, source register, dimensioned comparison, paste/anchor views, aperture table, tooling summary, qualification findings and unsent requests. It excludes raw board CAM, the entire R5 project and unrelated/credential files.

The dimensioned comparison is preserved pre-fix evidence. Its old importer-loss caption is explained in the package; current source/import/CAM views show the fidelity fix. Earlier image-layout drafts and initial failed link-check report are retained locally as review history and are not included in the final ZIP.

## Separate tooling freeze

[Importer fix status](../IMPORTER-FIX-STATUS.md), [seven local source histories](../frozen-toolchain-history.json). Importer branch `qualification/usb4215-paste-fidelity`; control snapshot `7910eedb8f0635ed941ea634b64c1f9874c437fc`; fixed snapshot `2f52a09b4293b2802f837f6350c37fb55c2198a5`. These are local archival commits of already-tested source snapshots, not published upstream commits. Board Git history was not modified. Original source archives and changes remain intact.

The focused **7,685 assertions PASS** remains supported by unchanged original logs. No new importer fix or broad regression was attempted here. Full suite remains **278 pass / 33 fail**, with all 33 names in the unchanged-source control; no full-suite pass or general release readiness is claimed. [Exact unique 33-case register](BASELINE-33-FAILURES.json) removes repeated Bun summary rows only in this new index; the original 66-row register remains unchanged.

## Requests and responses

| Party | Request | Response | Remaining authority |
|---|---|---|---|
| GCT | [Finalized](GCT-REQUEST.md), NOT SENT | NO RESPONSE | Exact stencil/paste/mask, production reflow/cycles, four-anchor process and any secondary limits |
| JLCPCB | [Finalized](JLCPCB-REQUEST.md), NOT SENT | NO RESPONSE | Exact coverage of 12 contacts + four anchors, stencil treatment, secondary process/service and order notes |

**SUPPLIER CAD INTENDS PASTE ON FOUR SHELL FEATURES** does not prove manufacturer process approval, mechanically complete joints, absence of secondary soldering or assembler coverage. Section 7.0 thermal numbers remain heat-resistance test conditions; production limits are **UNCONFIRMED**. [Explicit thermal table](package/SOLDER-PROCESS.md), [decision matrix and all R6 gates](../../USB4215-EXTERNAL-DECISION.md).

No outbound requests are authorized by this preparation step. Once a package is sent in a later authorized action, preserve its exact bytes/hash. Later clarification packages need a new name/version. Preserve any replies verbatim before interpretation; no-response never passes a gate. USB4216 / C47635969 remains **HOLD — ZERO STOCK / UNSUPPORTED CAD MODEL**.

## Reproducible review checks

Run from the R5 project directory:

```sh
tooling/gerber-review-venv/bin/python \
  evidence/USB4215-import-audit/external-process-review/verify-review-package.py
```

This checks ZIP CRC, exact allowlisted contents, all hashes, original PDFs, image decoding, local document links, preserved source histories, original 300-file audit manifest, 82 prior-search files, the entire pre-existing board-file preservation superset and the 416-file protected R4 set. It never builds a board or changes manufacturing outputs.

The builder reads source polygons, rendered JSON and actual Gerber geometry to create annotated review PNGs; these are drawings, not new electronic CAD. `build-review-package.py` refuses to replace an existing package. `../freeze-source-history.py` refuses to replace the separate local histories. See [original fixture reproduction](../REPRODUCE.md) for supported import/render/export verification; no need to repeat that work for these documentation-only changes.

All **972 protected files (556 R5 + 416 R4)** remain unchanged. Battery, RF, thermal, runtime, enclosure-fit and phone tests remain **POST-PROTOTYPE PHYSICAL VALIDATION**, separate from the external pre-fabrication gates.

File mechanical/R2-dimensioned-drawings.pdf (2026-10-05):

# MAGNETIC SHUTTER REMOTE | ORIGINAL DESIGN R2

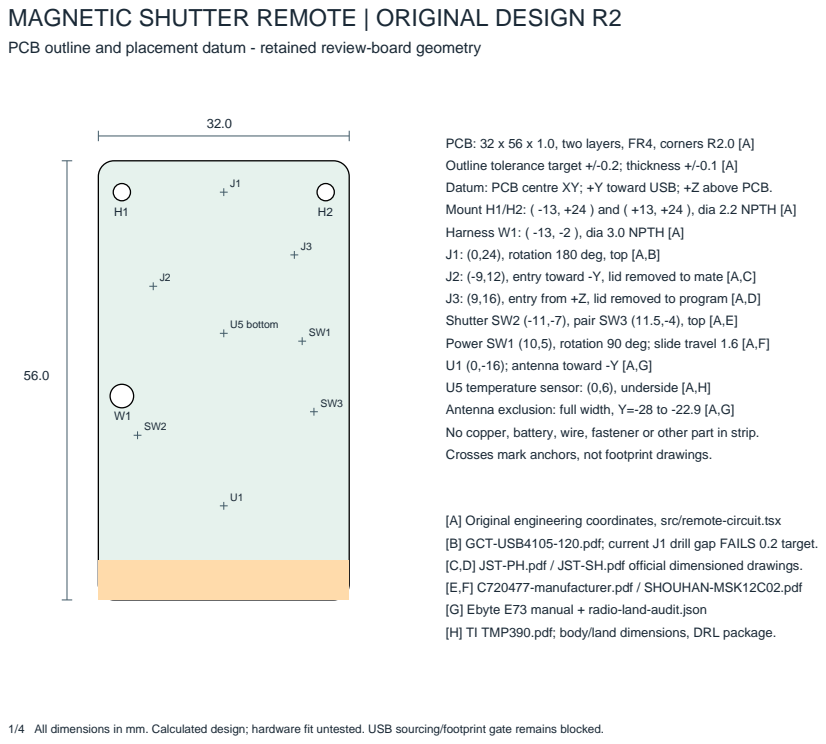
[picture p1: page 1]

PCB outline and placement datum - retained review-board geometry

PCB: 32 x 56 x 1.0, two layers, FR4, corners R2.0 [A]
Outline tolerance target +/-0.2; thickness +/-0.1 [A]
Datum: PCB centre XY; +Y toward USB; +Z above PCB.
Mount H1/H2: ( -13, +24 ) and ( +13, +24 ), dia 2.2 NPTH [A]
Harness W1: ( -13, -2 ), dia 3.0 NPTH [A]
J1: (0,24), rotation 180 deg, top [A,B]
J2: (-9,12), entry toward -Y, lid removed to mate [A,C]
J3: (9,16), entry from +Z, lid removed to program [A,D]
Shutter SW2 (-11,-7), pair SW3 (11.5,-4), top [A,E]
Power SW1 (10,5), rotation 90 deg; slide travel 1.6 [A,F]
U1 (0,-16); antenna toward -Y [A,G]
U5 temperature sensor: (0,6), underside [A,H]
Antenna exclusion: full width, Y=-28 to -22.9 [A,G]
No copper, battery, wire, fastener or other part in strip.
Crosses mark anchors, not footprint drawings.

[A] Original engineering coordinates, src/remote-circuit.tsx
[B] GCT-USB4105-120.pdf; current J1 drill gap FAILS 0.2 target.
[C,D] JST-PH.pdf / JST-SH.pdf official dimensioned drawings.
[E,F] C720477-manufacturer.pdf / SHOUHAN-MSK12C02.pdf
[G] Ebyte E73 manual + radio-land-audit.json
[H] TI TMP390.pdf; body/land dimensions, DRL package.

1/4 All dimensions in mm. Calculated design; hardware fit untested. USB sourcing/footprint gate remains blocked.

### Remote enclosure and battery stack - assembly datums

2/4 All dimensions in mm. Calculated design; hardware fit untested. USB sourcing/footprint gate remains blocked.

36.0

16.8

Section: Z=0 is external enclosure back [A] Base floor 1.2; PCB bottom 8.0; PCB top 9.0 [A]
Lid underside 15.6; external lid top 16.8 [A]
Battery top assembly datum 5.7 +/-0.1 [A,I]
Thermal contact at (0,6): 2 x 2, gap 1.7 nominal [A,H,J] Bottom C8: maximum height 1.45; nominal cell gap 0.85 [K] PH mated top Z=14.5; lid clearance 1.1 nominal [C]
SH mated top Z=15.3; programming with lid removed [D]

Remote body 36 x 60 x 16.8, corners R3 [A]
Maximum width with slider 38.4; cap top Z=17.5 [A] Internal cavity 33.6 x 57.6; walls 1.2 [A]
PCB-wall gap 0.8 nominal; calculated minimum 0.5 [A] Printed dimensional tolerance target +/-0.2 [A]
Pack: DATA POWER DTP401525(PHR), external [I] Maximum 15.5 x 27 x 4.2; nest 16.5 x 28 [A,I]
Pack plan: X +/-7.75, Y=-4.5 to +22.5 [A]
Measure actual thickness; add insulating bed shims. Do not compress pouch to establish Z datum.
Thermal pad free 2.032; nominal compression 16.3% [J] USB opening 12 x 7, centre (X=0,Y=29,Z=11) [A,B] This opening must be rechecked for a replacement J1. Two M2 x 14 lid screws; dia 1.7 pilot / 2.4 clearance [A] Board support boss dia 4.2, top Z=8; lid boss Z=9.15 [A]

[I] DTP401525-PHR-v2.pdf, pages 4, 7, 9.
[J] Henkel BERGQUIST-GAP-PAD-TGP-1500.pdf GP1500-0.080-02-0404 sheet, cut 2 x 2.
[K] Samsung CL21A106KAYNNNE package height.
All [A] dimensions are original design allocations.
Thermal gradient, pad pressure, swelling and fit are untested.

### Grip, docking, magnets and antenna clearance

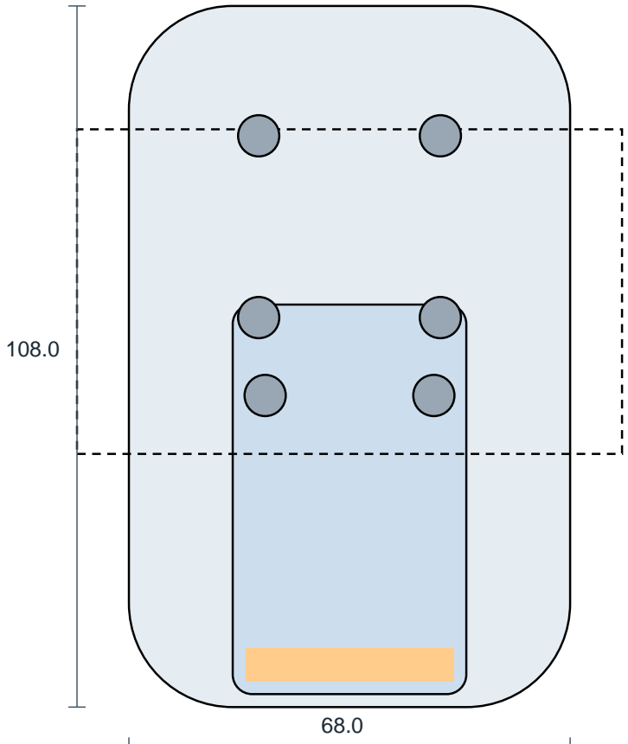
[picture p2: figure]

3/4 All dimensions in mm. Calculated design; hardware fit untested. USB sourcing/footprint gate remains blocked.

Grip plate: 68 x 108 x 6.5, R16, centre Y=-20 [A] Remote dock transform: Y=-42, back Z=6.8 [A] Cradle inside width 36.6; nominal side gap 0.3 [A] Rails 1.6 x 48 x 3.3; centres X=+/-19.1, Y=-38 [A] End stop 36.6 x 1.6 x 1.2; centre Y=-12 [A]
Eight K&J D42 magnets total: dia 6.35 x 3.175 [L]
Pocket dia 6.65; adhesive allowance 0.15 radial [A] Remote magnets: (+/-13,16); dock (+/-13,-26) [A]
Phone magnets: (+/-14,+/-14); verify attraction polarity [A] Separate steel phone plate: 45 x 45 x 0.5 [A]
Case/phone envelope width 84, height 180, thickness 10 [A] Phone bottom alignment Y=-35 +/-5; mark on grip [A] Antenna in dock: Y=-70 to -64.9 [A,G]
Nearest permitted phone metal Y=-40: 24.9 separation. Battery-antenna planar separation: 18.4 nominal.
Chosen metal separation target 15; Ebyte gives no numeric value. Phone/plate RF effects still require physical testing.
[L] https://www.kjmagnetics.com/d42-neodymium-disc-magnet

### Actuators, wiring and assembly inspection schedule

4/4 All dimensions in mm. Calculated design; hardware fit untested. USB sourcing/footprint gate remains blocked.

Button caps: dia 5.8 in dia 6.2 lid holes; radial clearance 0.2 [A]
Cap flange dia 8 x 0.8; stem dia 1.6; TPU compliant construction [A]
Rest stem tip Z=11.2; nominal switch top Z=11.0; free gap 0.2 [A,E]
Switch stroke 0.2 +/-0.1; force 160 +/-50 gf [E]
Adjust printed stem to measured switch height and test overtravel; do not preload the switch. SW1 fork inside width 1.7 around nominal 1.3 actuator; travel 1.6 [A,F]
Both states must seat fully without side-loading the switch.

Harness: manufacturer 100 +/-3 length, 26 AWG UL3302 [I]
Two wire reservations dia 1.2, centre spacing 1.3; route through W1 with insulated/smooth edge [A] Plan route passes side lanes at X=+/-11 and Y=24, above the cell, away from bottom electronics. Retain full lead length with smooth loops; verify bend radius >=3 and strain relief on actual assembly. Wire ends must not press on cell seals, PCB holes, magnets or exposed solder joints.

Critical checks before any fabrication release:
1. Resolve the USB-C supplier-library/clearance blocker; repeat footprint, routing and export checks.
2. Compare imported electronic models and the complete assembled envelope after J1 is finalized.
3. Review stencil and through-hole shell soldering with the assembler; no assembler feedback obtained.

Prototype-only acceptance steps (not passed by these drawings):
Pack polarity and protection; charger voltage/current and hot/cold stops; pad thermal error and pressure; actual component heights, battery swelling margin, cable abrasion, button/slider force and travel;
magnet retention, docking/drop tests; docked/detached RF; native iPhone and Android camera behavior.

Dimension sources are listed on sheets 1-3 and in mechanical/dimensions.json.
Original enclosure and grip design. No JJC internal dimensions are asserted.

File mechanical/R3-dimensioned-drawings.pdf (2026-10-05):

# MAGNETIC SHUTTER REMOTE | ORIGINAL DESIGN R3

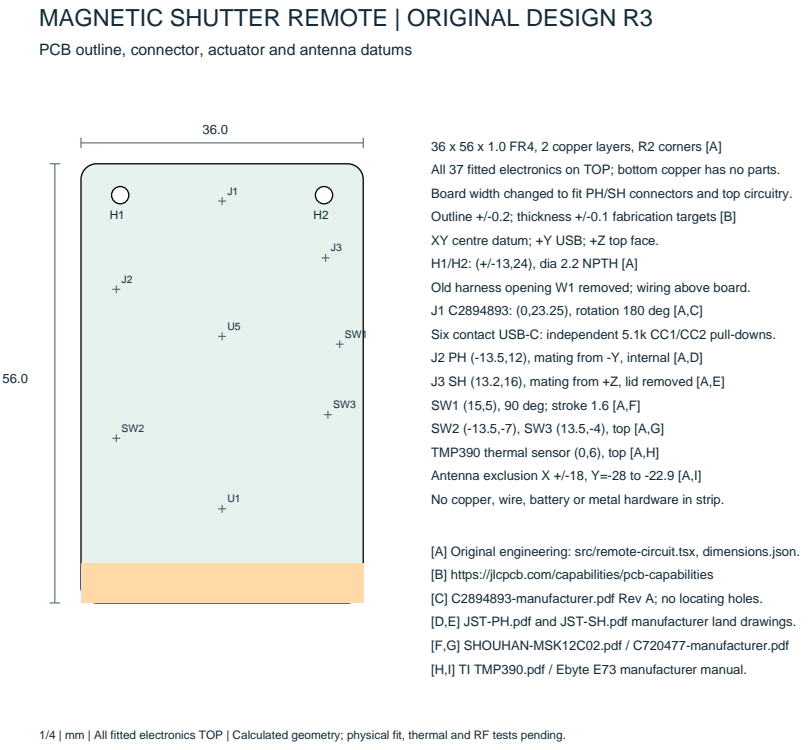
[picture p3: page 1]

PCB outline, connector, actuator and antenna datums

36 x 56 x 1.0 FR4, 2 copper layers, R2 corners [A]
All 37 fitted electronics on TOP; bottom copper has no parts.
Board width changed to fit PH/SH connectors and top circuitry.
Outline +/-0.2; thickness +/-0.1 fabrication targets [B]
XY centre datum; +Y USB; +Z top face.
H1/H2: (+/-13,24), dia 2.2 NPTH [A]
Old harness opening W1 removed; wiring above board.
J1 C2894893: (0,23.25), rotation 180 deg [A,C]
Six contact USB-C: independent 5.1k CC1/CC2 pull-downs.
J2 PH (-13.5,12), mating from -Y, internal [A,D]
J3 SH (13.2,16), mating from +Z, lid removed [A,E]
SW1 (15,5), 90 deg; stroke 1.6 [A,F]
SW2 (-13.5,-7), SW3 (13.5,-4), top [A,G]
TMP390 thermal sensor (0,6), top [A,H]
Antenna exclusion X +/-18, Y=-28 to -22.9 [A,I]
No copper, wire, battery or metal hardware in strip.

[A] Original engineering: src/remote-circuit.tsx, dimensions.json.
[B] https://jlcpcb.com/capabilities/pcb-capabilities
[C] C2894893-manufacturer.pdf Rev A; no locating holes.
[D,E] JST-PH.pdf and JST-SH.pdf manufacturer land drawings.
[F,G] SHOUHAN-MSK12C02.pdf / C720477-manufacturer.pdf
[H,I] TI TMP390.pdf / Ebyte E73 manufacturer manual.

1/4 | mm | All fitted electronics TOP | Calculated geometry; physical fit, thermal and RF tests pending.

### Remote enclosure, battery carrier and thermal stack

2/4 | mm | All fitted electronics TOP | Calculated geometry; physical fit, thermal and RF tests pending.

40.0

16.8

Z=0 external back; PCB bottom=5.0, top=6.0 [A] Body 40 x 60 x 16.8; max slider width 42.4 [A] Walls 1.2, inner cavity 37.6 x 57.6; corners R3 [A] Lid underside 15.6; cap top 17.5 [A]
PCB-wall gap 0.8 nominal / 0.5 tolerance allocation. Board support dia 4.2, Z=1.2..5; lid boss Z=6.15..15.6. Magnet + 0.5 cap top 4.675; PCB gap 0.325 nominal.

DATA POWER DTP401525(PHR), external pack [J] Maximum 15.5 x 27 x 4.2; side space 16.6 [A,J] Pack X +/-7.75; Y=-5.7..21.3; Z=8.3..12.5 [A]
Carrier floor Z=7.9..8.3; side gaps 0.55 nominal [A] Carrier thermal aperture 2.4 x 2.4 at (0,6).
TMP390 package maximum height 0.6 -> top Z=6.6 [H] Thermal-pad assembled gap target 1.7 [A,K]
Actual chip height/contact require measurement + shims. Pouch must not be compressed by lid, shims or pad.
C8 maximum height 1.45: top Z=7.45 [L]
C8 relief 5 x 3 at (5,17.5); battery gap 0.85 nominal. Battery-to-lid clearance 3.1 nominal, hardware untested. PH mated max height 5.5 -> top Z=11.5 [D]
SH mated max height 6.3 -> top Z=12.3 [E]
Both connectors outside battery envelope in X.

[J] DTP401525-PHR-v2.pdf manufacturer pack drawing.
[K] BERGQUIST GP1500-0.080-02-0404, free 2.032.
Henkel thermal-pad datasheet; cut 2 x 2, nominal 16.3% strain. [L] Samsung CL21A106KAYNNNE package drawing.
No JJC internal dimensions are asserted.

### Grip, docking envelope, magnets and antenna margins

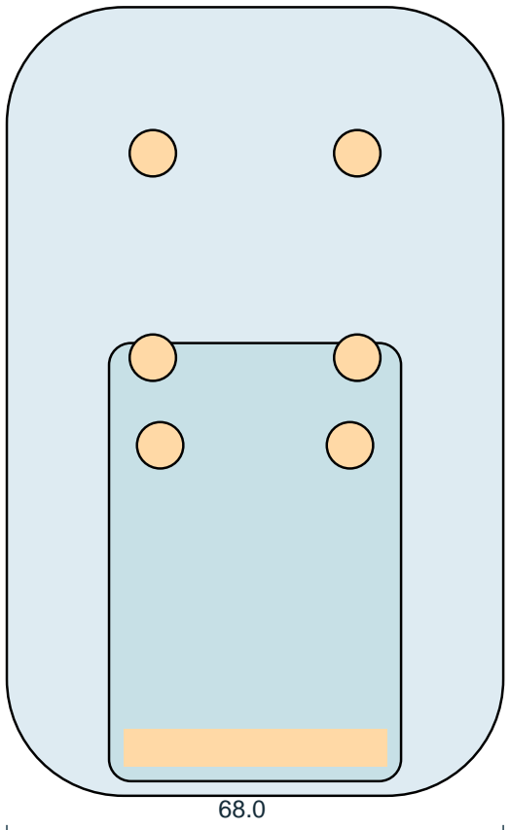
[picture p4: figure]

3/4 | mm | All fitted electronics TOP | Calculated geometry; physical fit, thermal and RF tests pending.

108.0

Grip 68 x 108, base 6.5; rail top Z=9.8; R16 [A] Dock centre Y=-42; back Z=6.8; button top 24.3 [A] Plate Z=-0.5; total plate-to-button stack 24.8 [A] Cradle inner width 40.6; nominal side gap 0.3 [A] Rails 1.6 x 48 x 3.3, centres X +/-21.1, Y=-38.
Stop 40.6 x 1.6 x 1.2, centre Y=-10.9.
Eight K&J D42 magnets, dia 6.35 x 3.175 [M] Pockets dia 6.65; nominal adhesive radial gap 0.15 [A] Remote (+/-13,16); dock (+/-13,-26) [A]
Phone magnets (+/-14,+/-14), captive behind cover [A] Separate steel phone plate 45 x 45 x 0.5 [A] Phone/case keep-in envelope 84 x 180 x 10 [A] Phone bottom aligned Y=-35 +/-5; mark alignment [A] Antenna Y=-70..-64.9 in dock frame.
Nearest permitted phone metal Y=-40: 24.9 gap. Detached battery planar gap to antenna strip: 17.2.
Chosen metal margin 15; Ebyte provides no numeric rule. These are calculated margins; RF hardware tests pending. [M] https://www.kjmagnetics.com/d42-neodymium-disc-magnet

### USB access, actuator travel, wiring and acceptance schedule

4/4 | mm | All fitted electronics TOP | Calculated geometry; physical fit, thermal and RF tests pending.

USB-C HCTL HC-TYPE-C-6P-01A C2894893; Rev A body: 8.95 x 6.85 x 3.16 +/-0.15 height [C] Recommended slots 4 x 0.50 x 1.40; shell centres X +/-4.32, row pitch 3.70 [C].
Supplier lands: GND 0.80, VBUS 0.76, CC 0.70 wide x 1.20; shell copper 1.10 x 1.80.
Opening 12 x 7 at (0,29,8), through front wall; connector mates +Y after 180 deg rotation [A,C].
Both USB orientations use separate CC pull-downs; no USB data or USB bootloader.
Plug reservation max 10 x 6.5 is an enclosure allocation; test intended cables before enclosure release.

Shutter/pair caps dia 5.8 in dia 6.2 holes; flange dia 8 x 0.8; stem dia 1.6 x 6.6 [A].
Stem rest Z=8.2; switch nominal top 8.0; free gap 0.2; travel 0.2 +/-0.1 [A,G].
TPU stem compliance is intentional; adjust to actual assembled height; avoid preload.
Side slider fork width 1.7 around nominal 1.3 switch actuator; designed travel 1.6 [A,F].

Harness: pack supplier lead length 100 +/-3 mm, red BAT+, black GND; actual connector polarity must be verified [J]. Two insulated conductor reservations dia 1.2, centre spacing 1.3; loop above left PH bay and outside antenna strip [A]. Harness bends and slack are assembly reservations; validate actual bend radius >=3, abrasion and strain relief.
No wire-through PCB opening or underside electronic assembly remains.

Before release: manufacturing copper/holes/slots, full CAM read, strict CPL rotations, stencil + hybrid shell process. The manufacturer pattern does not automatically establish process compliance.
Physical acceptance still pending: battery protection, charge current/voltage, temperature cutoff and thermal coupling; pouch clearance, wire retention, button/slider travel, magnet retention/drop tests, RF docked and detached;
firmware programming and native iPhone Camera / representative Android camera pairing and shutter behavior.

All electronics on TOP does not require single-layer copper. Two-layer FR4 remains selected.
This drawing is an original mechanical design. Calculated fit is not a physical measurement or acceptance test.

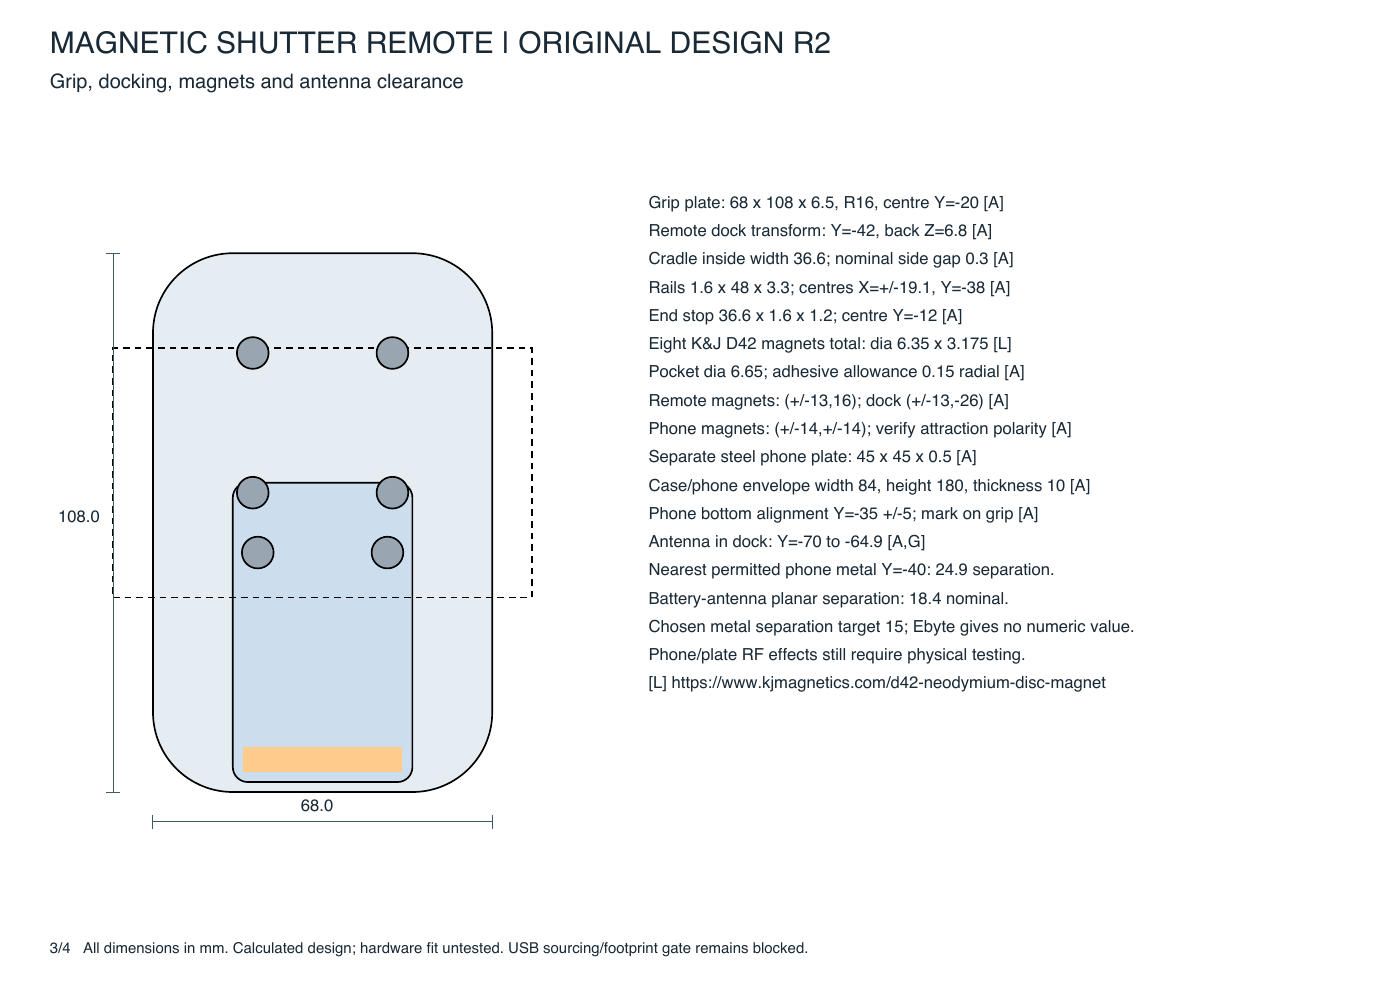
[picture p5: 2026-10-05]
baselines/r7/mechanical/drawing-r2-3.png

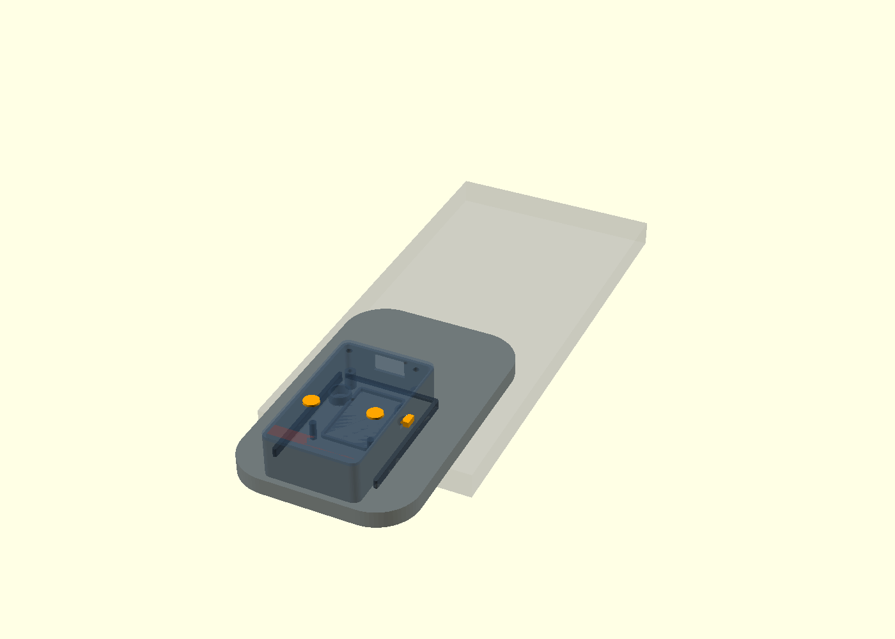
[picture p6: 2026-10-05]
mechanical/docked-fit-r2.png

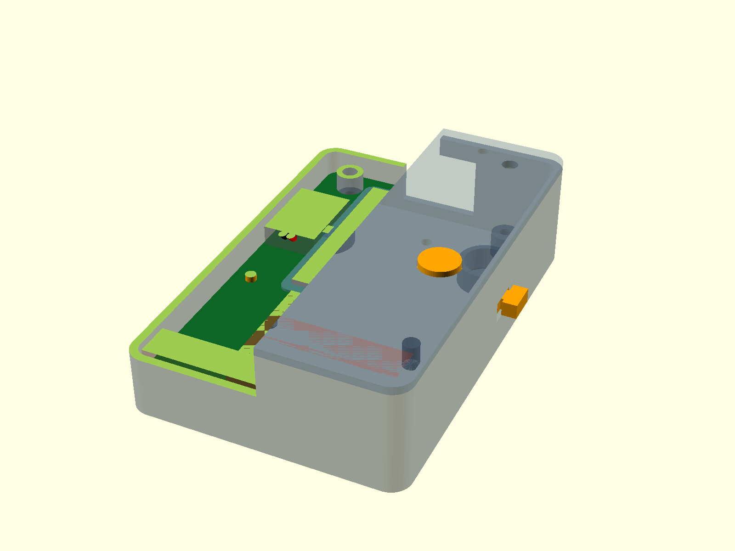
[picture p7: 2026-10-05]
baselines/r7/mechanical/remote-cutaway-r6.png

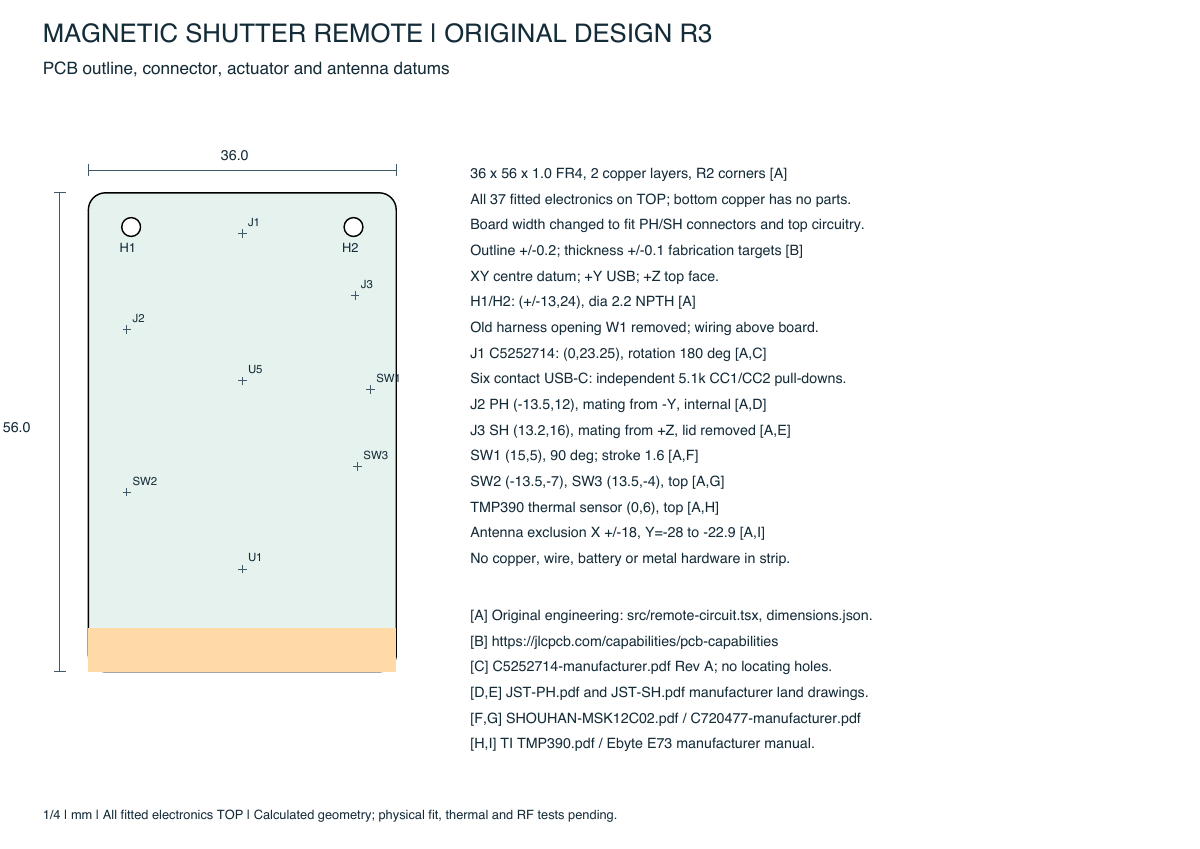
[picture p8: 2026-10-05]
baselines/r7/mechanical/drawing-r3-1.png

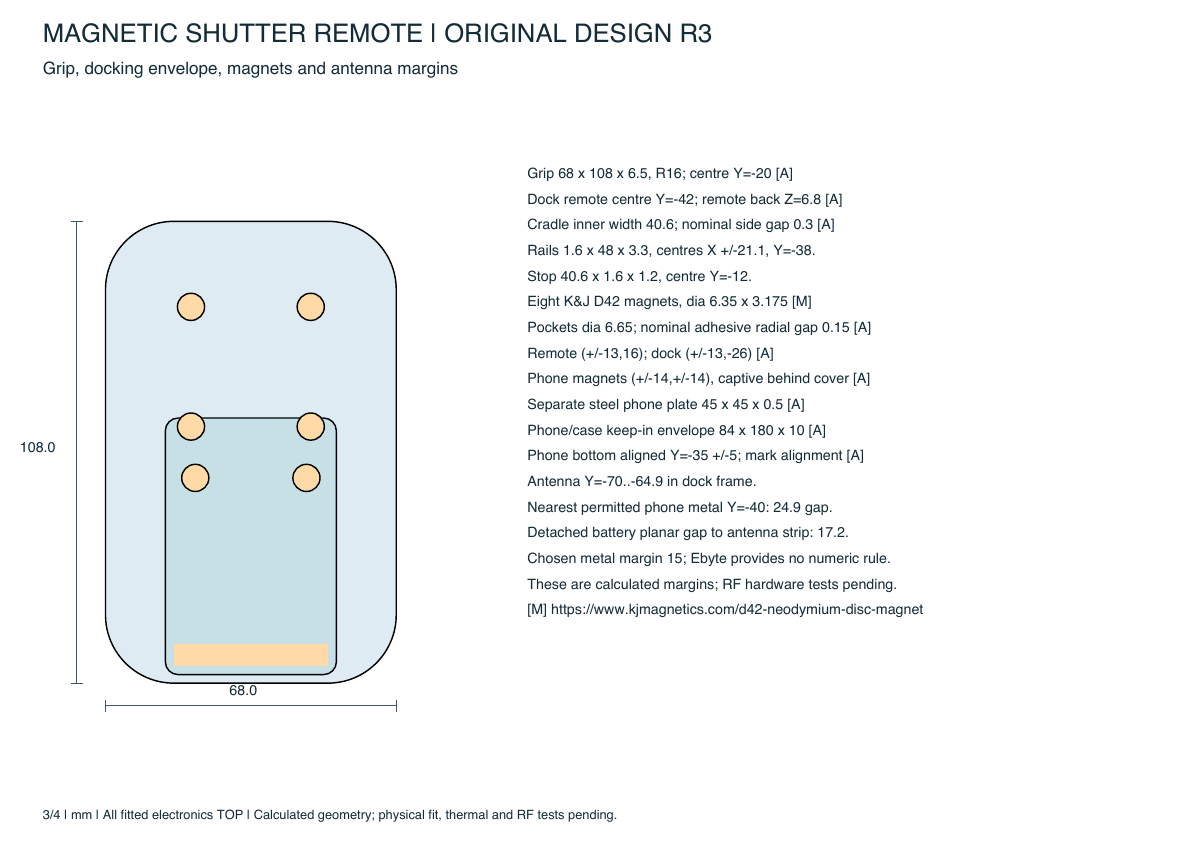
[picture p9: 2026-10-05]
baselines/r7/mechanical/drawing-r3-3.png

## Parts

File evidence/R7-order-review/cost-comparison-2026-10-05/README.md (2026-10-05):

# Shutter-only board cost comparison — 2026-10-05

Planning estimates only. No supplier upload, quote submission, order or payment.
No PCB, routing, BOM, CPL, Circuit JSON or frozen baseline changed.
Analysis starts from source/review commit `636d2b24eb4db775fceeb81206541f249db3b9a5`.

## Quantity comparison

| Finished assembled boards | Fitted component subtotal | Estimated delivered batch, San Francisco | Estimated per board |
|---|---:|---:|---:|
| 5 | $63.23 | $282.03–$382.68 | $56.41–$76.54 |
| 10 | $117.73 | $397.17–$505.15 | $39.72–$50.52 |
| 20 | $227.05 | $591.51–$719.16 | $29.58–$35.96 |

Battery, printed enclosure/grip, magnets, cables, programmer, assembly labor and physical testing are excluded. This is an assembled-PCB comparison, not a completed-device quotation.

## Reproducible basis

- Exact fitted quantities from `bom.json`: 37 refs, 24 identities, TOP only, no substitutions.
- Unit-price tiers from official public JLC pages archived in `../sourcing/` on 2026-10-04; source URLs and SHA256 values in `cost-model.json`. These are component-listing prices, not reserved PCBA prices. See `component-costs.csv` for all 72 quantity/part rows.
- The quantity-tier lookup is `startNumber <= fitted quantity × board count <= endNumber`; `endNumber = -1` is unbounded. No attrition/MOQ rounding in the component subtotal; those remain allowances.
- Standard single-side setup $25.56, stencil $8.21, feeders 24 × $1.53, placement review $0.45; packing $0.50 + $0.00003 × 20.16 cm² × quantity.
- U1 X-ray: $1.64 each through 10 units, $0.82 each for 11–50. No other current listed part has its X-ray flag set; actual order processing can add requirements.
- Assembly budget uses $0.48 per finished board as a minimum-charge allowance, not an exact joint quote. Actual panelized pricing may differ.
- PCB/ENIG/attrition allowances are $30–60 / $40–75 / $55–100 for 5/10/20. Optional fixture/storage/extra processing allowance is $0–25 per batch. These are unquoted engineering budget assumptions.
- Freight allowances are $25–45 / $30–50 / $35–60. No actual courier rate was obtained. Shipping depends on supplier-packed weight, destination and checkout availability.
- 35% import-duty assumption is provisional; exact product classification/rate must be confirmed at checkout. Do not add duty twice if included in DDP charges.
- 8.625% San Francisco sales/use-tax rate; model provisionally applies it to goods plus duty. Actual taxable basis and collection may differ.
- Formula: `(components + fixed fees + X-ray + assembly allowance + PCB/attrition + optional processing) × 1.35 × 1.08625 + freight`. No coupons assumed. This range is not a guarantee or an upper bound on actual supplier charges.

## Lowest-cost path without changing the board

Five boards minimize total prototype spending among these quantities; twenty reduce average unit cost but increase spend substantially. Keep five for first hardware testing. Choose the least expensive acceptable DDP shipping actually offered at checkout and apply valid account coupons. Print the enclosure locally where a real quote supports savings. Do not increase quantity solely to obtain a lower displayed unit price before hardware tests.

U1 is $38.17 of the $63.23 five-board fitted-component subtotal (about 60%). A later cheaper-radio design may reduce parts cost and remove the Standard-only constraint, but no replacement is selected, qualified or approved here. The module's 43-pad footprint includes hidden joints; manually installing it is not proposed as a beginner cost-saving step.

Economic assembly is not currently available for the full fitted BOM because U1 is Standard-only. Even a future eligible BOM would not automatically save all feeder fees: Economic charges Extended feeders while Standard charges all identities. With current 13 Extended identities, the published Economic feeder total would be $39.91 versus $36.72 Standard, so eligibility is not itself proof of lowest total cost.

Do not remove protection, charge-temperature control, USB-C CC resistors or mandatory inspection to meet a budget. No board material/finish/paste/process change is approved by this analysis.

## What still needs a real quote

Bare-PCB surcharges, attrition/MOQs, rails/fixtures, exact shell-anchor process coverage, freight, tariff classification, tax collection and discounts. No processed JLCPCB preview was provided or reviewed in this run. The board retains its existing order-preview gate and physical-validation status.

## Sources

- [JLCPCB assembly fees](https://jlcpcb.com/help/article/pcb-assembly-price), checked 2026-10-05.
- [JLCPCB shipping calculation](https://jlcpcb.com/help/article/how-much-does-shipping-cost), checked 2026-10-05: quote-page estimate and checkout final rate.
- [JLCPCB U.S. tariff policy](https://jlcpcb.com/help/article/us-tariff-policy-faq), checked 2026-10-05: rate depends on product/material; individual U.S. shipments use DDP.
- [CDTFA tax rates](https://cdtfa.ca.gov/taxes-and-fees/rates.aspx), effective 2026-10-01, checked 2026-10-05.

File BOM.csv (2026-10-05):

reference_designators | quantity | value | manufacturer | manufacturer_part_number | package | lcsc | assembly_category | observed_stock | observed_available | availability_check_date | assembly_requirements | source_link | lcsc_link | datasheet_file | qualification
U1 | 1 | E73-2G4M08S1C | Chengdu Ebyte Electronic Technology | E73-2G4M08S1C | SMD module, 43 pads, 13 x 18 x 3 mm | C356849 | Extended | 1689 | 1246 | 2026-10-01 | Standard only; X-ray required | https://jlcpcb.com/partdetail/Chengdu_Ebyte_ElecTech-E732G4M08S1C/C356849 | https://www.lcsc.com/product-detail/C356849.html | references/E73-2G4M08S1C-manufacturer.pdf | Reviewed with disclosed land/derating assumptions; physical tests pending
U2 | 1 | BQ25185DLHR | Texas Instruments | BQ25185DLHR | WSON-10, 2.2 x 2 mm, exposed pad | C19725033 | Extended | 3834 | 3739 | 2026-10-01 | Economic/Standard; MSL 3 | https://jlcpcb.com/partdetail/BQ25185DLHR/C19725033 | https://www.lcsc.com/product-detail/C19725033.html | references/R4-qualification/BQ25185-current.pdf | R5 current TI SLUSF65B section 7.4.1: actual solid GND plane/returns pass. Stencil 0.10 mm / area ratios pass. Physical temperature and battery tests are POST-PROTOTYPE PHYSICAL VALIDATION.
U5 | 1 | TMP390A2DRLR | Texas Instruments | TMP390A2DRLR | SOT-563 / DRL-6 | C5219772 | Extended | 37610 | 37585 | 2026-10-01 | Economic/Standard; manufacturer MSL 2 | https://jlcpcb.com/partdetail/TMP390A2DRLR/C5219772 | https://www.lcsc.com/product-detail/C5219772.html | references/TMP390.pdf | Reviewed with disclosed land/derating assumptions; physical tests pending
U4 | 1 | TPS3839G33DBZR | Texas Instruments | TPS3839G33DBZR | SOT-23-3 / DBZ | C485802 | Extended | 3405 | 3375 | 2026-10-01 | Economic/Standard; MSL 1 | https://jlcpcb.com/partdetail/TPS3839G33DBZR/C485802 | https://www.lcsc.com/product-detail/C485802.html | references/TPS3839.pdf | Reviewed with disclosed land/derating assumptions; physical tests pending
R3 | 1 | 15 kΩ ±1%, 0.1 W, 75 V | UNI-ROYAL | 0603WAF1502T5E | 0603 | C22809 | Basic | 4587959 | 4275297 | 2026-10-01 | Economic/Standard | https://jlcpcb.com/partdetail/0603WAF1502T5E/C22809 | https://www.lcsc.com/product-detail/C22809.html | references/C22844-manufacturer.pdf | Reviewed with disclosed land/derating assumptions; physical tests pending
R8 | 1 | 130 kΩ ±1%, 0.1 W, 75 V | UNI-ROYAL | 0603WAF1303T5E | 0603 | C22795 | Extended | 588652 | 546495 | 2026-10-01 | Economic/Standard | https://jlcpcb.com/partdetail/0603WAF1303T5E/C22795 | https://www.lcsc.com/product-detail/C22795.html | references/C22844-manufacturer.pdf | Reviewed with disclosed land/derating assumptions; physical tests pending
R9 | 1 | 10 kΩ ±1%, 0.1 W, 75 V | UNI-ROYAL | 0603WAF1002T5E | 0603 | C25804 | Basic | 23109251 | 16156915 | 2026-10-01 | Economic/Standard | https://jlcpcb.com/partdetail/0603WAF1002T5E/C25804 | https://www.lcsc.com/product-detail/C25804.html | references/C22844-manufacturer.pdf | Reviewed with disclosed land/derating assumptions; physical tests pending
R10 | 1 | 1.62 kΩ ±1%, 0.1 W, 75 V | UNI-ROYAL | 0603WAF1621T5E | 0603 | C22844 | Extended | 27688 | 27604 | 2026-10-01 | Economic/Standard | https://jlcpcb.com/partdetail/0603WAF1621T5E/C22844 | https://www.lcsc.com/product-detail/C22844.html | references/C22844-manufacturer.pdf | Reviewed with disclosed land/derating assumptions; physical tests pending
R11 | 1 | 18.7 kΩ ±1%, 0.1 W, 75 V | UNI-ROYAL | 0603WAF1872T5E | 0603 | C22893 | Extended | 133033 | 131350 | 2026-10-01 | Economic/Standard | https://jlcpcb.com/partdetail/0603WAF1872T5E/C22893 | https://www.lcsc.com/product-detail/C22893.html | references/C22844-manufacturer.pdf | Reviewed with disclosed land/derating assumptions; physical tests pending
C8 | 1 | 10 µF ±10%, 25 V, X5R | Samsung Electro-Mechanics | CL21A106KAYNNNE | 0805 | C15850 | Basic | 4997153 | 3794120 | 2026-10-01 | Economic/Standard; MSL 1 | https://jlcpcb.com/partdetail/CL21A106KAYNNNE/C15850 | https://www.lcsc.com/product-detail/C15850.html | Samsung manufacturer product-family bias curves; see ELECTRICAL-QUALIFICATION.md | Reviewed with disclosed land/derating assumptions; physical tests pending
C9 | 1 | 47 pF ±5%, 50 V, C0G | CCTC | TCC0603COG470J500CT | 0603 | C282505 | Extended | 8123 | 8111 | 2026-10-01 | Economic/Standard; MSL 1 | https://jlcpcb.com/partdetail/TCC0603COG470J500CT/C282505 | https://www.lcsc.com/product-detail/C282505.html | references/C282505-manufacturer.pdf | Reviewed with disclosed land/derating assumptions; physical tests pending
U3 | 1 | TPS7A0230PDBVR | Texas Instruments | TPS7A0230PDBVR | SOT-23-5 (DBV) | C3747031 | Extended | 37586 | 37516 | 2026-10-01 | Economic/Standard; MSL 1 | https://jlcpcb.com/partdetail/TexasInstruments-TPS7A0230PDBVR/C3747031 | https://www.lcsc.com/product-detail/C3747031.html | references/TPS7A02.pdf | Reviewed with disclosed land/derating assumptions; physical tests pending
J1 | 1 | USB-C charging receptacle | GCT / Global Connector Technology | USB4215-03-A | SMT 16-contact USB-C; four plated shell slots | C37616412 | Extended | 125 | 43 | 2026-10-03 | Extended SMT; MSL 1; Economic and Standard listing. Shell-joint coverage unconfirmed; inspect and manually rework if needed for prototype. No X-ray or fixture requirement displayed, not a guarantee. | https://jlcpcb.com/partdetail/39339856-USB4215_03A/C37616412 | https://www.lcsc.com/product-detail/C37616412.html | references/GCT-USB4215-drawing-Rev-A.pdf | Official GCT Rev A copper and plated-slot geometry verified; 16 source paste apertures preserved through corrected supported importer; production qualification pending per user prototype acceptance.
J2 | 1 | S2B-PH-SM4-TB(LF)(SN) | JST | S2B-PH-SM4-TB(LF)(SN) | PH 2 mm, side-entry SMT | C295747 | Extended | 20971 | 20398 | 2026-10-01 | Economic/Standard; MSL 1 | https://jlcpcb.com/partdetail/JST-S2B_PH_SM4_TB_LF_SN/C295747 | https://www.lcsc.com/product-detail/C295747.html | references/JST-PH.pdf | Reviewed with disclosed land/derating assumptions; physical tests pending
J3 | 1 | BM06B-SRSS-TB(LF)(SN) | JST | BM06B-SRSS-TB(LF)(SN) | SH 1 mm, top-entry SMT | C160392 | Extended | 34461 | 28818 | 2026-10-01 | Economic/Standard; MSL 1 | https://jlcpcb.com/partdetail/JST-BM06B_SRSS_TB_LF_SN/C160392 | https://www.lcsc.com/product-detail/C160392.html | references/JST-SH.pdf | Reviewed with disclosed land/derating assumptions; physical tests pending
SW1 | 1 | SPDT slide switch | SHOU HAN | MSK12C02 | SMD 8 x 2.8 mm, 3 contacts + shell | C431540 | Extended | 193532 | 188023 | 2026-10-01 | Economic/Standard | https://jlcpcb.com/partdetail/MSK12C02/C431540 | https://www.lcsc.com/product-detail/C431540.html | references/SHOUHAN-MSK12C02.pdf | Reviewed with disclosed land/derating assumptions; physical tests pending
SW2, SW3 | 2 | Normally-open tactile switch, 2 mm height | XUNPU | TS-1088-AR02016 | SMD tactile 4 x 3 x 2 mm | C720477 | Basic | 786967 | 742195 | 2026-10-01 | Economic/Standard; MSL not stated | https://jlcpcb.com/partdetail/SHOUHAN-TS_1088_AR02016/C720477 | https://www.lcsc.com/product-detail/C720477.html | references/C720477-manufacturer.pdf | Reviewed with disclosed land/derating assumptions; physical tests pending
Q1, Q2 | 2 | N-channel MOSFET, 60 V | Jiangsu Changjing Electronics Technology | 2N7002 | SOT-23 | C8545 | Basic | 1642765 | 1522993 | 2026-10-01 | Economic/Standard; MSL 1 | https://jlcpcb.com/partdetail/JiangsuChangjingElectronicsTechnologyCoLtd-2N7002/C8545 | https://www.lcsc.com/product-detail/C8545.html | references/C8545-manufacturer.pdf | Reviewed with disclosed land/derating assumptions; physical tests pending
R1, R2 | 2 | 5.1 kΩ ±1%, 0.1 W, 75 V | UNI-ROYAL | 0603WAF5101T5E | 0603 imperial / 1608 metric | C23186 | Basic | 25285299 | 24338678 | 2026-10-01 | Economic/Standard | https://jlcpcb.com/partdetail/UNIROYAL-0603WAF5101T5E/C23186 | https://www.lcsc.com/product-detail/C23186.html | references/C22844-manufacturer.pdf | Reviewed with disclosed land/derating assumptions; physical tests pending
R4, R7 | 2 | 1 kΩ ±1%, 0.1 W, 75 V | UNI-ROYAL | 0603WAF1001T5E | 0603 imperial / 1608 metric | C21190 | Basic | 21678575 | 16868949 | 2026-10-01 | Economic/Standard | https://jlcpcb.com/partdetail/UNIROYAL-0603WAF1001T5E/C21190 | https://www.lcsc.com/product-detail/C21190.html | references/C22844-manufacturer.pdf | Reviewed with disclosed land/derating assumptions; physical tests pending
R5, R6, R12, R13 | 4 | 100 kΩ ±1%, 0.1 W, 75 V | UNI-ROYAL | 0603WAF1003T5E | 0603 imperial / 1608 metric | C25803 | Basic | 22171651 | 20485261 | 2026-10-01 | Economic/Standard | https://jlcpcb.com/partdetail/UNIROYAL-0603WAF1003T5E/C25803 | https://www.lcsc.com/product-detail/C25803.html | references/C22844-manufacturer.pdf | Reviewed with disclosed land/derating assumptions; physical tests pending
C1, C2, C3, C4 | 4 | 4.7 µF ±10%, 16 V, X5R | Samsung Electro-Mechanics | CL10A475KO8NNNC | 0603 imperial / 1608 metric | C19666 | Basic | 2544067 | 2016787 | 2026-10-01 | Economic/Standard; MSL 1 | https://jlcpcb.com/partdetail/Samsung-CL10A475KO8NNNC/C19666 | https://www.lcsc.com/product-detail/C19666.html | Samsung manufacturer product-family bias curves; see ELECTRICAL-QUALIFICATION.md | Reviewed with disclosed land/derating assumptions; physical tests pending
C5, C6, C7 | 3 | 100 nF ±10%, 50 V, X7R | YAGEO | CC0603KRX7R9BB104 | 0603 imperial / 1608 metric | C14663 | Basic | 54430410 | 41987508 | 2026-10-01 | Economic/Standard; MSL 1 | https://jlcpcb.com/partdetail/YAGEO-CC0603KRX7R9BB104/C14663 | https://www.lcsc.com/product-detail/C14663.html | references/C14663-manufacturer.pdf | Reviewed with disclosed land/derating assumptions; physical tests pending
LED1, LED2 | 2 | Red LED | Hubei KENTO Electronic | KT-0603R | 0603 imperial / 1608 metric | C2286 | Basic | 4840846 | 4349467 | 2026-10-01 | Economic/Standard; MSL 3 | https://jlcpcb.com/partdetail/HubeiKENTOElec-KT_0603R/C2286 | https://www.lcsc.com/product-detail/C2286.html | references/C2286-manufacturer.pdf | Reviewed with disclosed land/derating assumptions; physical tests pending

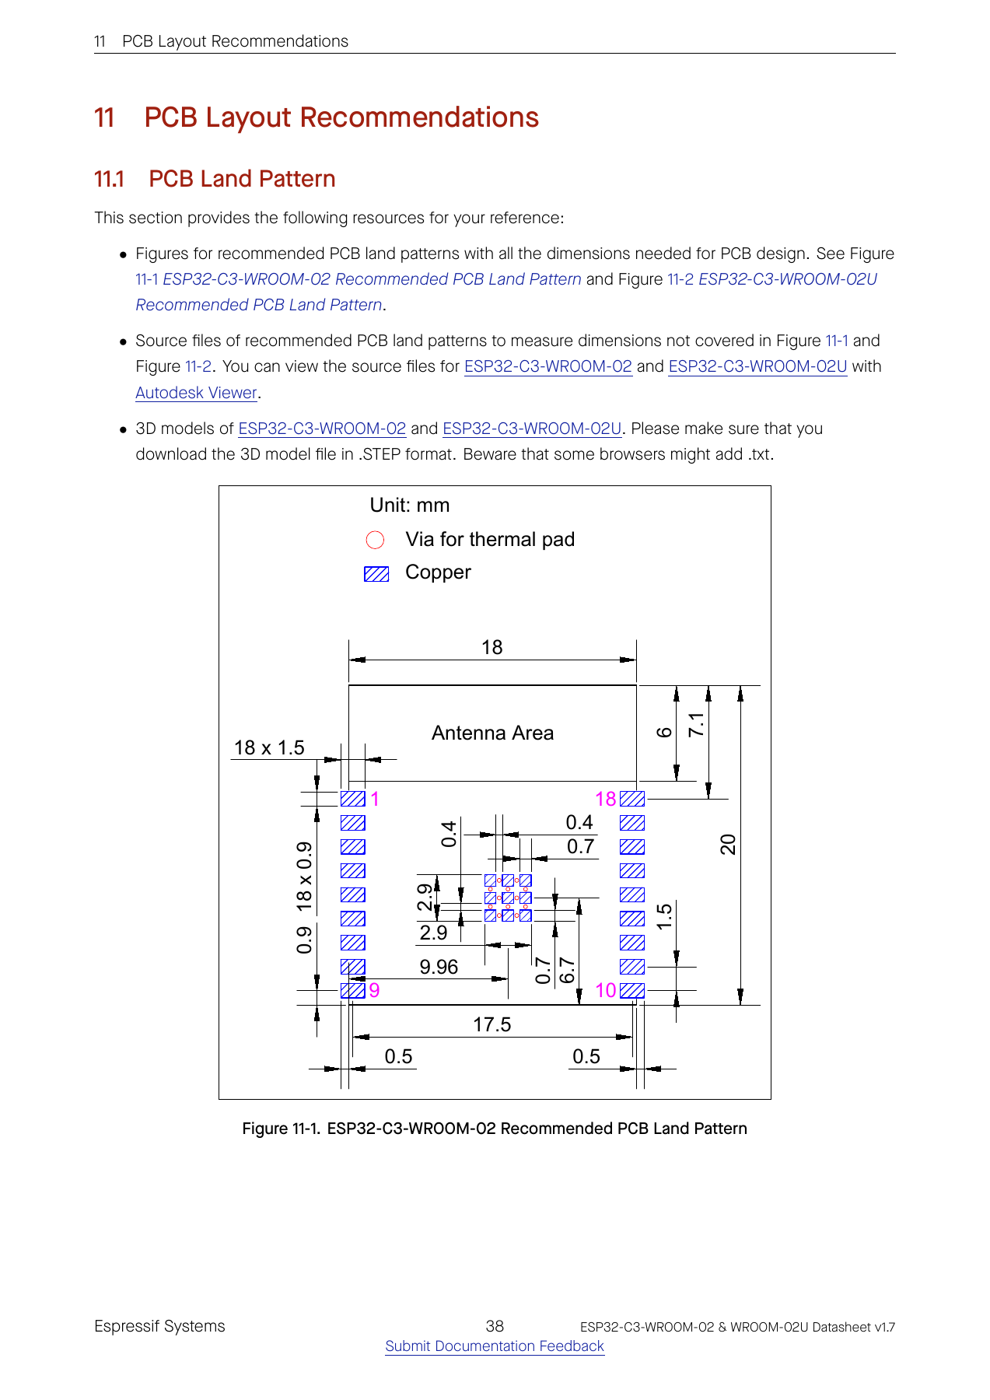
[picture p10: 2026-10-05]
evidence/R8-components/esp32-land-pattern.png

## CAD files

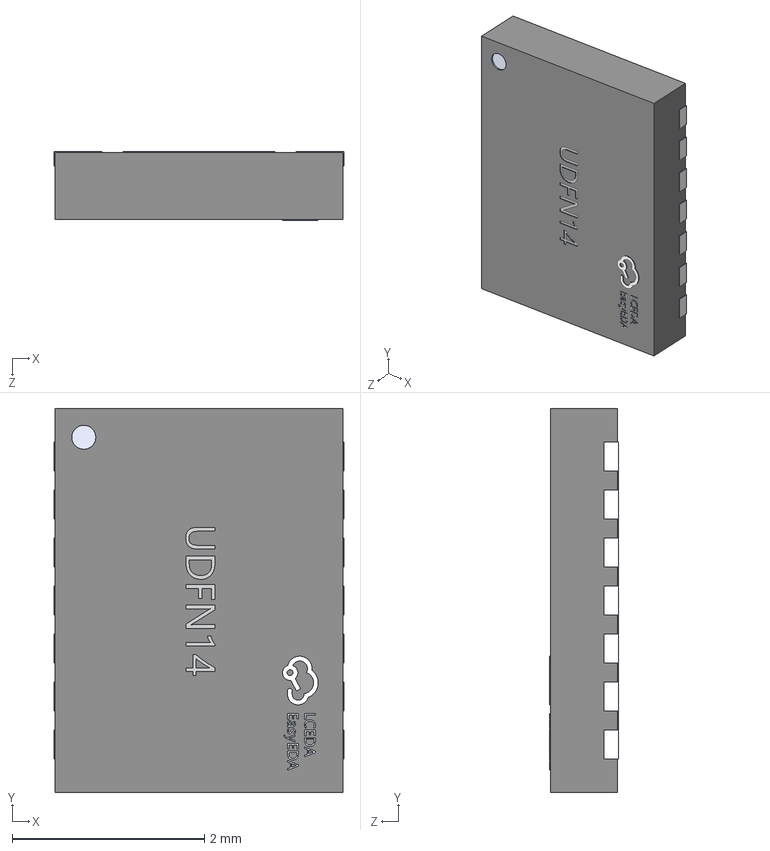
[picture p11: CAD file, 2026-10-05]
baselines/r7/imports/AL1793AFE_13/AL1793AFE_13.step
3.02 x 4.00 x 0.72 mm

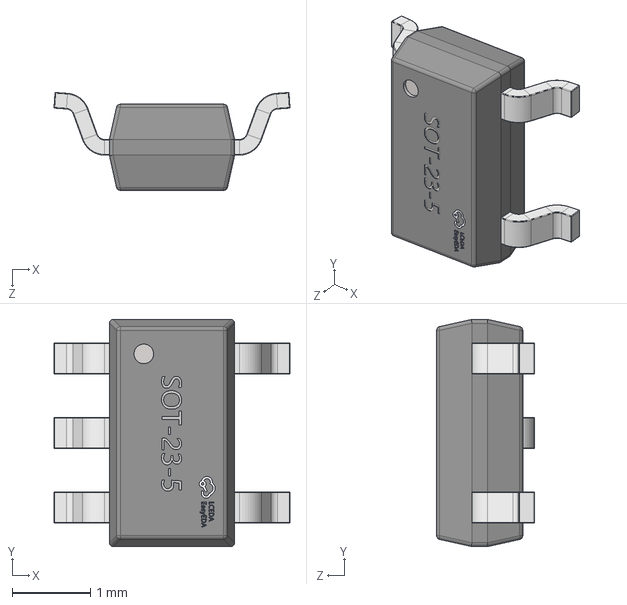
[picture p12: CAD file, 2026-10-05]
baselines/r7/imports/AL8860WT_7/AL8860WT_7.step
3.01 x 2.90 x 1.25 mm

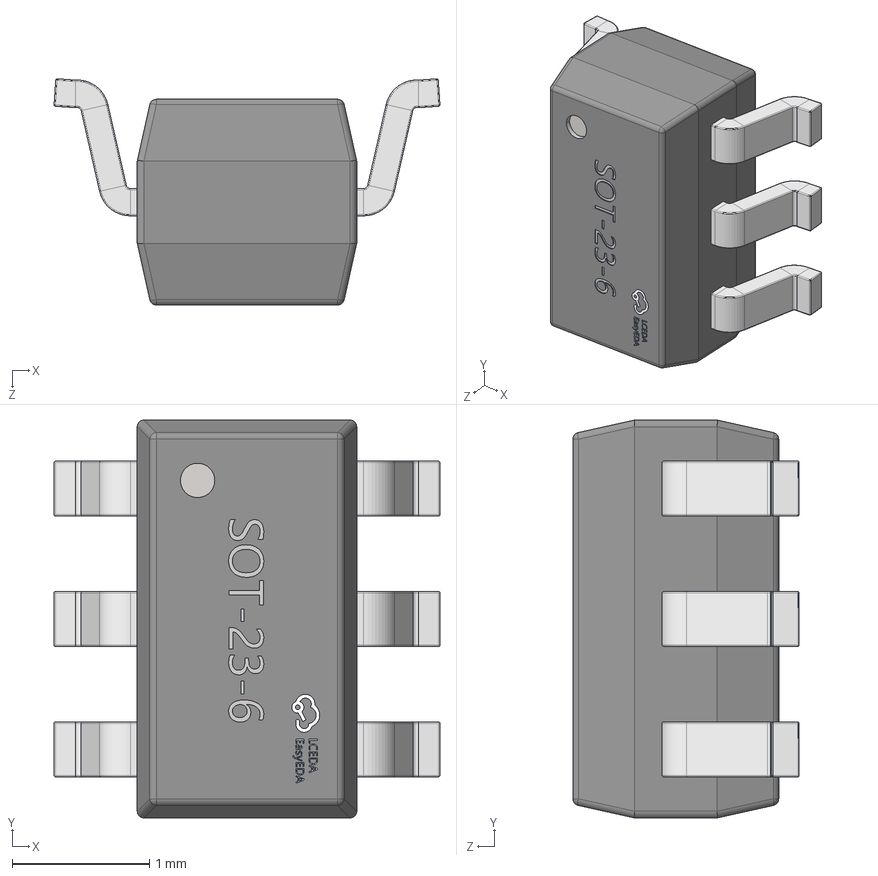
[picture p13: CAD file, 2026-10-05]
baselines/r7/imports/TPS2553DBVR_1/TPS2553DBVR_1.step
2.81 x 2.90 x 1.65 mm

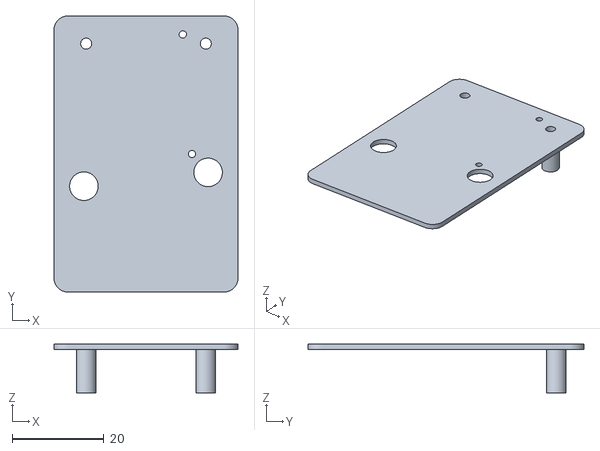
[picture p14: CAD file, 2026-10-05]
baselines/r7/mechanical/stl/lid.stl
40.0 x 60.0 x 10.7

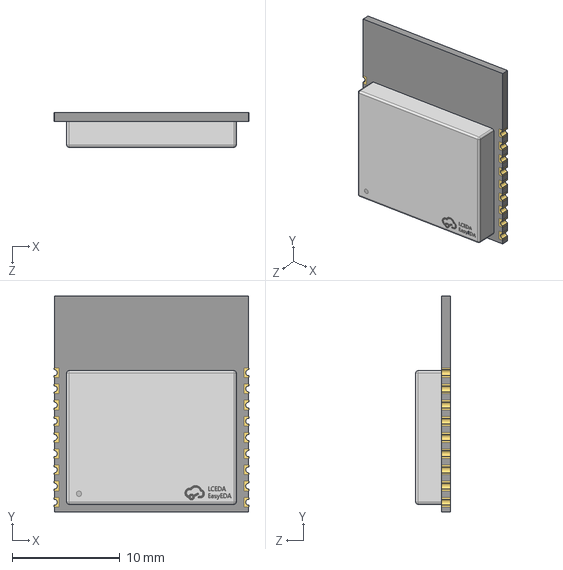
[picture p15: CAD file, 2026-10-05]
imports/ESP32_C3_WROOM_02_N4/ESP32_C3_WROOM_02_N4.step
18.0 x 20.0 x 3.22 mm

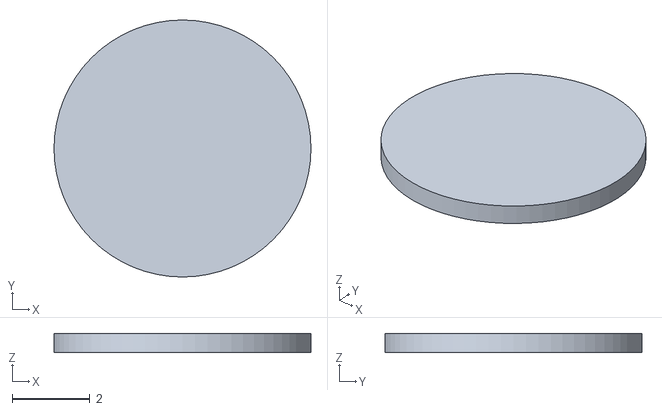
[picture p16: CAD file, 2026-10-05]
mechanical/stl/magnet_cap.stl
6.60 x 6.60 x 0.5

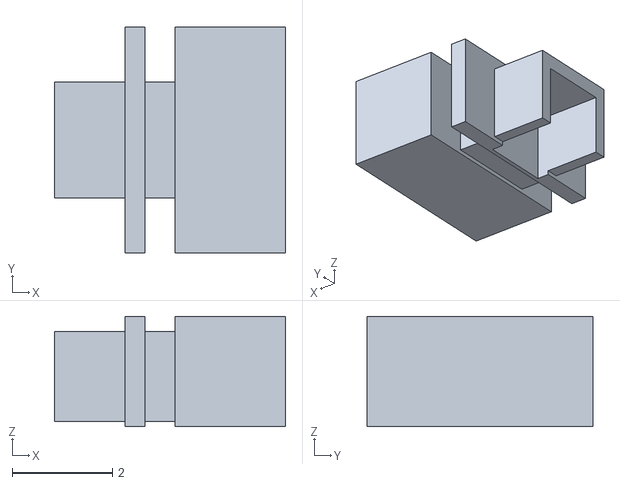
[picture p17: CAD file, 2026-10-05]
baselines/r7/mechanical/stl/slider.stl
4.60 x 4.50 x 2.20

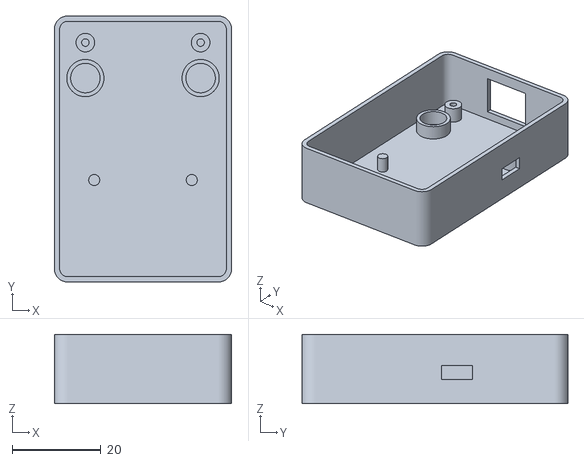
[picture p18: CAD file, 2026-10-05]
baselines/r7/mechanical/stl/base.stl
40.0 x 60.0 x 15.6

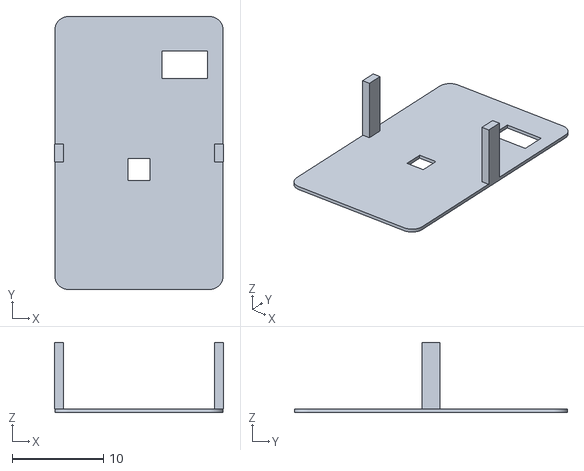
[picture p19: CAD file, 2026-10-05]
mechanical/stl/carrier.stl
18.6 x 30.0 x 7.70

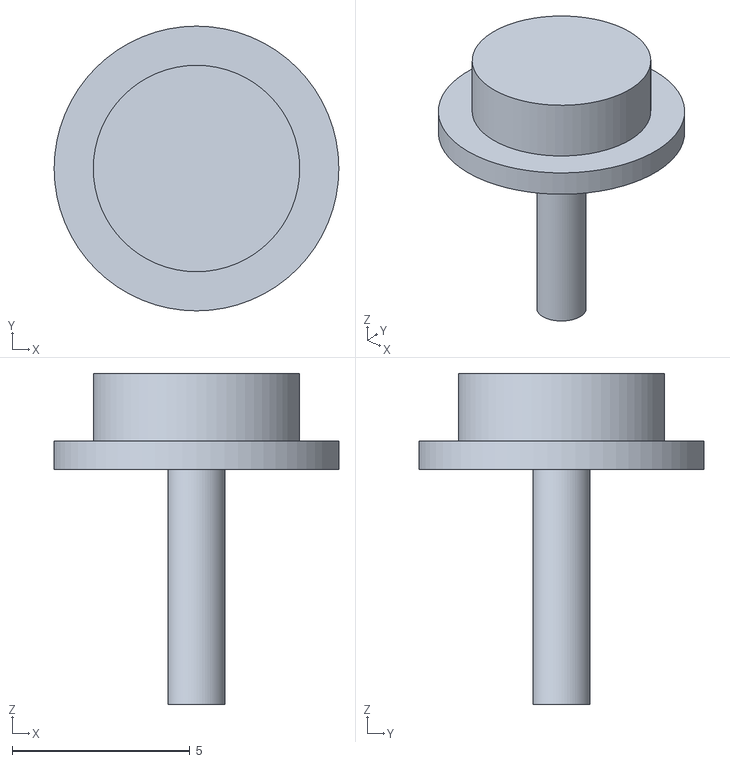
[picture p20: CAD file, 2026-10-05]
mechanical/stl/button.stl
8.00 x 8.00 x 9.30

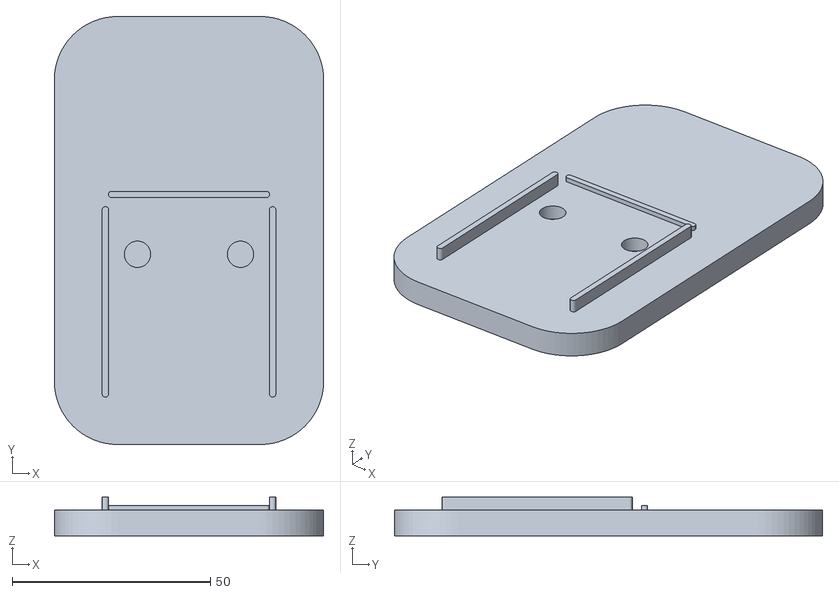
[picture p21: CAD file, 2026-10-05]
mechanical/stl/grip.stl
68.0 x 108.0 x 9.80

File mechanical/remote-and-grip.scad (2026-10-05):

// R6 original mechanical design. Millimetres. Not JJC replacement geometry.
// Coordinate frame: PCB XY; remote outer back z=0, PCB bottom z=5.
// Separate printable parts selected with -D 'part="base"', etc.
$fn=64;
part="assembly";
remote_w=40; remote_l=60; remote_h=16.8;
pcb_z=5; wall=1.2;
battery_w=15.5; battery_l=27; battery_h=4.2;
module rounded_box(size,r=2){
 linear_extrude(height=size[2]) offset(r=r)
 square([size[0]-2*r,size[1]-2*r],center=true);
}
module remote_base(){
 difference(){
  union(){
   difference(){
    rounded_box([remote_w,remote_l,15.6],3);
    translate([0,0,1.2]) rounded_box([37.6,57.6,15],1.8);
   }
   for(x=[-13,13]) translate([x,24,1.2]) cylinder(d=4.2,h=3.8);
   for(x=[-11,11]) translate([x,-7,1.2]) cylinder(d=2.5,h=3.8);
   for(x=[-13,13]) translate([x,16,1.2]) cylinder(d=8.4,h=3.5);
  }
  for(x=[-13,13]) translate([x,24,1.0]) cylinder(d=1.7,h=8);
  // D42 retention magnets, 6.35 x 3.175; 0.15 mm radial adhesive allowance.
  for(x=[-13,13]) translate([x,16,1]) cylinder(d=6.65,h=4.2);
  // USB opening accommodates 6.5 mm plug body height and cable approach.
  translate([0,29,8]) cube([12,6,9.5],center=true);
  // Side slider actuator and 1.6 mm travel; removable external slide cap.
  translate([19,5,7]) cube([5,7,3.2],center=true);
 }
}
module remote_lid(){
 difference(){
  union(){
   translate([0,0,15.6]) rounded_box([40,60,1.2],3);
   for(x=[-13,13]) translate([x,24,6.15]) cylinder(d=4.2,h=9.45);
  }
  for(p=[[-13.5,-7],[13.5,-4]]) translate([p[0],p[1],15]) cylinder(d=6.2,h=3);
  for(p=[[8,26],[10,0]]) translate([p[0],p[1],15]) cylinder(d=1.6,h=3);
  for(x=[-13,13]) translate([x,24,5.9]) cylinder(d=2.4,h=11.2);
 }
}
module battery_carrier(){
 difference(){
  translate([0,7.8,7.9]) rounded_box([18.5,30,0.4],1.5);
  translate([0,6,8.1]) cube([2.4,2.4,1.0],center=true);
  // C8 relief keeps the carrier floor out of the component-height stack.
  translate([5,17.5,8.1]) cube([5,3,1.0],center=true);
 }
 // Centre each 1 mm tab on its stated X datum: inside faces +/-8.3.
 for(x=[-8.8,8.8]) translate([x-0.5,6.8,8.3]) cube([1,2,7.3]);
}
module button(){
 // TPU compliance is intentional. Set the stem after actual switch-height check.
 difference(){
  union(){cylinder(d=5.8,h=2.7); cylinder(d=8,h=0.8); translate([0,0,-6.6]) cylinder(d=1.6,h=6.6);}
  for(a=[0,120,240]) rotate([0,0,a]) translate([1.2,-0.25,-0.01]) cube([2.5,0.5,0.55]);
 }
}
module slider(){
 // Local origin is the switch body centre at board (15,5), z=6.
 // Fork captures the verified 1.3 mm wide actuator with 0.2 mm each side.
 difference(){
  union(){
   translate([2.8,-1.15,0.1]) cube([3.4,2.3,1.8]);
   translate([5.2,-2.25,0]) cube([2.2,4.5,2.2]);
   translate([4.2,-2.25,0]) cube([0.4,4.5,2.2]);
  }
  translate([2.6,-0.85,-0.1]) cube([1.9,1.7,1.65]);
 }
}
module wire_path(points,r=0.6){
 for(i=[0:len(points)-2]) hull(){
  translate(points[i]) sphere(r=r);
  translate(points[i+1]) sphere(r=r);
 }
}
module magnet_cap(){ cylinder(d=6.6,h=0.5); }
module grip(){
 difference(){
  union(){
   translate([0,-20,0]) rounded_box([68,108,6.5],16);
   // Remote cradle leaves USB and antenna end open; 0.3 mm side clearance.
   for(x=[-21.1,21.1]) translate([x,-38,6.5]) rounded_box([1.6,48,3.3],0.7);
   // Remote end is Y=-12; stop's near face -11.7 leaves 0.3 mm.
   translate([0,-10.9,6.5]) rounded_box([40.6,1.6,1.2],0.7);
  }
  // Four phone attachment magnets, mechanically captive behind a printed cover.
  for(x=[-14,14],y=[-14,14]) translate([x,y,-0.1]) cylinder(d=6.65,h=3.95);
  // Pair for remote docking, retained by adhesive and a 0.5 mm cover.
  for(x=[-13,13]) translate([x,-26,2.8]) cylinder(d=6.65,h=4);
 }
}
module remote_assembly(){
 color([0.18,0.25,0.32,0.45]) remote_base();
 color([0.2,0.32,0.45,0.3]) remote_lid();
 color([0.05,0.4,0.15]) translate([0,0,pcb_z]) difference(){
  rounded_box([36,56,1],2);
  for(x=[-13,13]) translate([x,24,-0.1]) cylinder(d=2.2,h=1.2);
 }
 // External removable carrier supports the pack above the single-face electronics.
 color("silver") translate([-7.75,-5.7,8.3]) cube([15.5,27,4.2]);
 color([0.5,0.6,0.8,0.5]) battery_carrier();
 for(x=[-13,13]) color("silver") translate([x,16,1]) cylinder(d=6.35,h=3.175);
 for(p=[[-13.5,-7],[13.5,-4]]) color("orange") translate([p[0],p[1],14.8]) button();
 color("orange") translate([15,5,6]) slider();
 // Harness reservation: 1.2 mm diameter per insulated conductor; smooth bends
 // and the complete 97-103 mm lead slack are checked during assembly.
 for(dx=[-0.65,0.65]) color(dx<0?"black":"red") wire_path([
  [-13.5+dx,4.5,8.5],[-14+dx,1,12.5],[-14+dx,22,12.5],
  [-15.7+dx,23,14.1],[-15.7+dx,11,14.1],[-9.3+dx,11,14.1],
  [-9.3+dx,23,14.1],[-11.5+dx,23,14.1],[-11.5+dx,-4,14.1],
  [0+dx,-5.7,10.5]
 ]);
 // USB4215 maximum body envelope: official drawing, not a substitute footprint/model.
 color([0.7,0.7,0.75,0.5]) translate([-4.595,21.9101694,6]) cube([9.19,6.75,3.41]);
 // Manufacturer body envelopes; these are clearance volumes, not electronic models.
 color([0.8,0.2,0.1,0.45]) translate([-6.55,-26.275,6]) cube([13.1,18.2,3.1]);
 color([0.9,0.2,0.1,0.2]) translate([-18,-28,0]) cube([36,5.1,16.8]);
 color([0.5,0.5,0.5,0.5]) translate([-17.6,4.5,6]) cube([8.2,12,5.5]);
 color([1,0.5,0,0.4]) translate([-1,5,6.6]) cube([2,2,1.7]);
}
if(part=="base") remote_base();
if(part=="lid") translate([0,0,-15.6]) remote_lid();
if(part=="button") translate([0,0,6.6]) button();
if(part=="slider") slider();
if(part=="grip") grip();
if(part=="carrier") translate([0,0,-7.9]) battery_carrier();
if(part=="magnet_cap") magnet_cap();
if(part=="remote") remote_assembly();
if(part=="assembly"){
 color([0.2,0.25,0.3,0.7]) grip();
 translate([0,-42,6.8]) remote_assembly();
 // Phone/case keep-in envelope: bottom aligned at y=-35 +/-5, not a phone model.
 color([0.3,0.3,0.4,0.15]) translate([-42,-35,-10.5]) cube([84,180,10]);
 color("silver") translate([-22.5,-22.5,-0.5]) cube([45,45,0.5]);
}

if(part=="cutaway") difference(){ remote_assembly(); translate([-30,-35,9.1]) cube([30,70,20]); }

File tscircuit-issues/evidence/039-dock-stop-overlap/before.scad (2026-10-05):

// Minimal original stop expression; not an electronic footprint.
translate([0,-12,6.5]) cube([40.6,1.6,1.2],center=true);
// Docked 60 mm remote centred Y=-42 ends at Y=-12.

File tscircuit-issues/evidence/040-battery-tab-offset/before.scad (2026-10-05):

// Original isolated carrier tab expression, not supplier/electronic geometry.
for(x=[-8.8,8.8]) translate([x,6.8,8.3]) cube([1,2,7.3]);
// Maximum pack X range -7.75..7.75 mm.

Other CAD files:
baselines/r7/imports/AL1793AFE_13/AL1793AFE_13.obj
baselines/r7/imports/AL8860WT_7/AL8860WT_7.obj
baselines/r7/imports/TPS2553DBVR_1/TPS2553DBVR_1.obj
baselines/r7/imports/TPS61085DGKR/TPS61085DGKR.obj
baselines/r7/imports/TPS61085DGKR/TPS61085DGKR.step
baselines/r7/imports/TPS61165DBVR/TPS61165DBVR.obj
baselines/r7/imports/TPS61169DCKR/TPS61169DCKR.obj
baselines/r7/imports/TPS61169DCKR/TPS61169DCKR.step
imports/AL1793AFE_13/AL1793AFE_13.obj
imports/AL8860WT_7/AL8860WT_7.obj
imports/ESP32_C3_WROOM_02_N4/ESP32_C3_WROOM_02_N4.obj
imports/TPS2553DBVR_1/TPS2553DBVR_1.obj
imports/TPS61085DGKR/TPS61085DGKR.obj
imports/TPS61085DGKR/TPS61085DGKR.step
imports/TPS61165DBVR/TPS61165DBVR.obj
imports/TPS61169DCKR/TPS61169DCKR.obj
imports/TPS61169DCKR/TPS61169DCKR.step
imports/TPS63031DSKR/TPS63031DSKR.obj
imports/TPS63031DSKR/TPS63031DSKR.step

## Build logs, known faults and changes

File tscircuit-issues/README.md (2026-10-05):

# Local issue register — magnetic shutter remote R5

All **52** issue reports are retained. [R4 disposition](STATUS-R4.md) remains historical. R5 resolves project grounding (044), printable legend (041), and numeric stencil strategy (037); new local tooling fixes and open investigations are 045-052. Exact USB land qualification (042) and shell process remain open. See [R5 qualification](../R5-QUALIFICATION.md).

These are local reports only. Nothing was submitted to GitHub, suppliers, or an assembler. Confirmed supplier-data discrepancies, manufacturing limits and project audit errors are explicitly distinct from tscircuit defects. “Fixed locally” does not mean fixed upstream.

| Issue | Affected package | Status | Classification |
|---|---|---|---|
| [001 — Three-terminal slide switch inferred as SPST](001-spdt-switch-inferred-as-spst.md) | easyeda-converter 0.0.364 | fixed locally | tscircuit importer classification / missing topology input |
| [002 — Custom transistor symbol omits dynamic reference label](002-transistor-import-missing-reference-label.md) | easyeda-converter 0.0.364 | fixed locally | tscircuit importer rendering |
| [003 — Reference outside symbol bounds loses its owner](003-custom-symbol-reference-owner-outside-bounds.md) | core 0.0.2035 | fixed locally | tscircuit core rendering |
| [004 — Connector import cannot specify verified mating direction](004-connector-mating-direction-metadata.md) | easyeda-converter 0.0.364 | fixed locally | tscircuit importer metadata limitation |
| [005 — Generic USB symbol loses supplier pin arrangement](005-usb-import-generic-symbol-discards-pin-arrangement.md) | easyeda-converter 0.0.364 | fixed locally | tscircuit importer symbol classification |
| [006 — Thermostat category incorrectly inferred as mechanical switch](006-thermostat-category-inferred-as-switch.md) | easyeda-converter 0.0.364 | fixed locally | tscircuit importer classification |
| [007 — Declared oval drill length replaced by inferred equal annulus](007-declared-oval-drill-length-ignored.md) | easyeda-converter 0.0.364 | fixed locally | confirmed tscircuit geometry conversion bug |
| [008 — Core emits PCB fields incompatible with Circuit JSON schema](008-pcb-render-schema-offset-and-optional-hole-fields.md) | core 0.0.2035 | fixed locally | confirmed cross-package schema incompatibility |
| [009 — Schema parsing strips native schematic sheet metadata](009-schematic-sheet-schema-strips-metadata.md) | circuit-json 0.0.509 | fixed locally | confirmed schema metadata omission |
| [010 — Custom symbol ports do not correctly merge repeated physical pads](010-custom-symbol-repeated-pad-port-merging.md) | core 0.0.2035 | fixed locally | confirmed core port association bug |
| [011 — Saved custom-symbol port selector cannot resolve actual port](011-custom-symbol-selector-round-trip.md) | core 0.0.2035 | fixed locally | confirmed core selector bug |
| [012 — Rotation inference rejects submicron supplier row rounding](012-supplier-pin-orientation-submicron-quantization.md) | circuit-json-util 0.0.117 | fixed locally | confirmed orientation classification sensitivity |
| [013 — Plated holes generate unrequested stencil paste on both faces](013-plated-holes-create-unrequested-paste.md) | core 0.0.2035 | fixed locally | confirmed core fabrication geometry bug |
| [014 — Branched route cannot be saved as a simple endpoint path](014-branched-route-cache-path-incomplete.md) | core 0.0.2035 | suspected | observed warning; root cause not confirmed |
| [015 — Manufacturer USB land pattern fails JLC NPTH clearance](015-usb-land-pattern-conflicts-with-npth-process.md) | easyeda-converter 0.0.364 | confirmed | manufacturing limitation, not a tscircuit defect |
| [016 — E73 pin-3 supplier land shifted from manufacturer nominal](016-radio-pin-three-supplier-pitch-discrepancy.md) | easyeda-converter 0.0.364 | confirmed | supplier CAD discrepancy, not a converter bug |
| [017 — Project drill audit uses one threshold and omits tracks and pours](017-blanket-drill-pad-check-misclassification.md) | project manufacturing-audit.py R2 | fixed locally | project checker mistake, not a tscircuit defect |
| [018 — Gerbonara cannot parse native exported G85 plated slots](018-g85-plated-slot-reader-unsupported.md) | Gerbonara 1.5.0 | confirmed | external reader limitation; exporter defects tracked separately in 024/025 |
| [019 — Supplier download CLI exits zero after a failed lookup](019-download-cli-reports-success-on-failure.md) | easyeda-converter 0.0.364 | fixed locally | confirmed tscircuit CLI error propagation bug |
| [020 — Part search returns unrelated results for exact-looking MPN query](020-search-query-returns-unrelated-parts.md) | CLI 0.1.2212 / search service | suspected | retrieval/service behavior; not a confirmed importer bug |
| [021 — Fanout points are created before custom-symbol ports and trace identities initialize](021-fanout-created-before-source-port-initialization.md) | @tscircuit/core 0.0.2035 | fixed locally | tscircuit render-phase ordering defect |
| [022 — Adding saved fanout points removes custom-symbol owner-aware port aliases](022-saved-fanout-invalidates-custom-symbol-port-selectors.md) | @tscircuit/core 0.0.2035 | fixed locally | tscircuit selector-cache invalidation defect |
| [023 — Fanout solver treats a schematic sheet as its PCB routing group](023-fanout-treats-schematic-sheet-as-routing-group.md) | @tscircuit/core 0.0.2035 | fixed locally | tscircuit PCB/schematic container integration defect |
| [024 — USB plated slots export as ambiguous separate G85 records](024-excellon-g85-slot-record-and-mode-export.md) | circuit-json-to-gerber 0.0.104 bundled in CLI 0.1.2212 | fixed locally | tscircuit manufacturing exporter defect |
| [025 — Excellon header marker appears after the end of the drill program](025-excellon-header-after-end-of-program.md) | circuit-json-to-gerber 0.0.104 bundled in CLI 0.1.2212 | verified fixed upstream | tscircuit exporter defect fixed in upstream release |
| [026 — Declared autorouter traceClearance does not affect native routing input](026-autorouter-trace-clearance-not-consumed.md) | @tscircuit/core 0.0.2035 | confirmed | confirmed unused configuration; intended API semantics need upstream confirmation |
| [027 — Native routing returns copper with real shorts and manufacturing clearance failures](027-native-routing-output-has-shorts-and-clearance-failures.md) | @tscircuit/core 0.0.2035 local R3 patches | suspected | observed failed output; algorithm root cause not established |
| 028 | @tscircuit/core 0.0.2035 | fixed locally | [Transparent group schema](028-transparent-group-invalid-circuit-json.md) |
| [029 — Strict placement export cannot orient a supplier connector with no terminal named pin1](029-supplier-rotation-requires-pin-one.md) | pnp-csv 0.0.16 / util 0.0.117 | confirmed | See report for classification |
| [030 — Native browser evaluation did not include the locally corrected core](030-native-viewer-and-local-engine-diverge.md) | runframe 0.0.2883 / eval 0.0.1506 | fixed locally | See report for classification |
| [031 — Saved fanout rejects a valid bottom-layer escape from a through-plated terminal](031-saved-fanout-plated-terminal-layer.md) | core 0.0.2035 | fixed locally | See report for classification |
| [032 — Relative GLB output is resolved under the input directory](032-cli-relative-glb-output-path.md) | CLI 0.1.2212 | suspected | See report for classification |
| [033 — Native development viewer recursively loads task tooling and its own output log](033-viewer-watches-task-archives-and-own-log.md) | Project viewer configuration | confirmed | See report for classification |
| [034 — Local package archive reuse and missing installed core binary](034-local-archive-dependency-binary-stale.md) | Bun 1.3.9 / local archive integration | suspected | See report for classification |
| [035 — Global route between saved fanout exits loses source-trace attribution](035-global-route-between-fanouts-loses-net-attribution.md) | core 0.0.2035 | fixed locally | See report for classification |
| [036 — Independent manufacturing checker missed internal port connections and physical pad junctions](036-independent-checker-internal-pads-and-net-recursion.md) | Project manufacturing checker | fixed locally | See report for classification |
| [037 — Default generated charger stencil differs from TI example](037-default-charger-stencil-discrepancy.md) | core 0.0.2035 / stencil process | fixed locally (R5) | See report for classification |
| [038 — Project CAM paste baseline](038-project-cam-check-compares-paste-to-copper.md) | Project R3 / affected tools in report | fixed locally | Project checker mistake |
| [039 — Dock stop interference](039-project-dock-stop-overlaps-remote.md) | Project R3 / affected tools in report | fixed locally | Mechanical design mistake |
| [040 — Asymmetric carrier tabs](040-project-battery-carrier-tab-origin-offset.md) | Project R3 / affected tools in report | fixed locally | Mechanical design mistake |
| [041 — Legend manufacturing limits](041-imported-legend-exceeds-fabrication-print-rules.md) | Project R3 / affected tools in report | fixed locally (R5) | Manufacturing limitation |
| [042 — HCTL copper lands exceed manufacturer reference tolerance](042-hctl-expanded-copper-land-qualification.md) | Supplier library / importer 0.0.364 boundary | confirmed | Supplier land-pattern qualification, not importer conversion bug |
| [043 — Registration checker assumes direct board-relative components](043-project-registration-assumes-direct-board-frame.md) | Project audit added after b01c1d5; input core 0.0.2035 / schema 0.0.509 | fixed locally | Project checker mistake, not a tscircuit defect; group-anchor regression added |
| [044 — Charger solid-ground-plane requirement unqualified](044-charger-solid-ground-plane-qualification-gap.md) | Project b01c1d5 / TI SLUSF65B / core 0.0.2035 | fixed locally (R5) | Project layout qualification gap; connected GND traces are not a solid plane; not a tscircuit bug |

## R5 additions

| Issue | Affected package | Status | Classification |
|---|---|---|---|
| [045-independent-copper-reader-lacks-brep-regions — Independent checker cannot read native BREP copper pours](045-independent-copper-reader-lacks-brep-regions.md) | Project manufacturing audit / review reader; Gerbonara 1.5.0; Shapely 2.1.2 | fixed locally | Project checker limitation, not a tscircuit defect |
| [046-parent-stencil-margin-cannot-style-imports — Parent stencil styling unavailable for immutable supplier footprints](046-parent-stencil-margin-cannot-style-imports.md) | @tscircuit/props 0.0.672 base f136fe4178b5b5ca80efb314b4fc3679ed068c61; @tscircuit/core 0.0.2035 base 3fcbb3842b8ab1c0af324078f6eb55c3dbcba1a0 | fixed locally | Missing API capability, not supplier footprint corruption |
| [047-silkscreen-path-ignores-parent-visibility — Native silkscreen paths ignore inherited pcbSx visibility](047-silkscreen-path-ignores-parent-visibility.md) | @tscircuit/core 0.0.2035 local R3 attribution base 3fcbb3842b8ab1c0af324078f6eb55c3dbcba1a0; props 0.0.672 | fixed locally | Confirmed core style integration inconsistency |
| [048-board-owned-silkscreen-fails-schema — Native board-level silkscreen has no valid schema owner](048-board-owned-silkscreen-fails-schema.md) | @tscircuit/core 0.0.2035; circuit-json 0.0.509 local sheet schema; exact local source/archives in tooling/revisions-r5.json | fixed locally | Confirmed core/schema integration defect |
| [049-pour-npth-clearance-smaller-than-request — Requested pour clearance is smaller in actual NPTH copper geometry](049-pour-npth-clearance-smaller-than-request.md) | @tscircuit/core 0.0.2035; @tscircuit/copper-pour-solver 0.0.62; circuit-json 0.0.509 | suspected | Confirmed geometry discrepancy; responsible package/root cause not yet confirmed |
| [050-usb-alternative-supplier-land-mismatches — Additional USB-C supplier libraries differ from manufacturer land drawings](050-usb-alternative-supplier-land-mismatches.md) | easyeda-converter 0.0.364 local R3 supported pipeline; raw supplier libraries C456012/C668623/C3151650 | confirmed | Supplier data discrepancies; not confirmed tscircuit converter bugs |
| [051-length-parser-accepts-nonfinite-invalid-unit — Length parser returns NaN for an invalid unit string](051-length-parser-accepts-nonfinite-invalid-unit.md) | circuit-json 0.0.509; @tscircuit/props 0.0.672 | confirmed | Confirmed unit parser behavior; broad upstream fix remains open |

R4 remains immutable in the source directory. Issue 043 regressions are retained. R5 closes the project grounding/legend gaps only after final actual-copper and export checks; issue 042 USB supplier qualification remains open. Physical validation is POST-PROTOTYPE PHYSICAL VALIDATION.

| [052 — Historical USB pin table stale after connector change](052-historical-usb-pin-table-stale-after-connector-change.md) | Project R2 report / R4 baseline | fixed locally | Project documentation mistake; actual wiring correct |

R5 HCTL-only follow-up (2026-10-02): issue 042 reused; no new issue numbers. Exact drawings reconfirm recommended copper widths, fresh LCSC PDF equals saved Rev A, and no exact thermal/profile/manual limits or four-shell-joint coverage were found. Historical shell-height question transcription corrected in new qualification text; old evidence preserved. [Current source register](../fabrication/HCTL-SOURCE-REGISTER.md), [unsent attachment](../fabrication/HCTL-QUALIFICATION-PACKAGE.pdf). Supplier acceptance remains blocked; no tscircuit copper defect newly confirmed.

## R6 additions and qualification history

R5/R4 reports remain historical; R6 prototype-only process disposition is in `../R6-QUALIFICATION.md`. Production approval is not implied.

| Issue | Affected package | Status | Report |
|---|---|---|---|
|060|circuit-json-to-pnp-csv 0.0.19|fixed locally|[Strict CPL export requires numeric pin1 on a valid labelled connector](060-strict-cpl-export-requires-numeric-pin1.md)|
|061|circuit-json-to-gerber 0.0.109|fixed locally|[Gerber CLI runtime imports declared only as development dependencies](061-gerber-cli-runtime-dependencies-undeclared.md)|
|062|@tscircuit/cli 0.1.2212 → local0.1.2237|fixed locally|[CLI Gerber shorts check uses an exporter without polygon paste support](062-shorts-cli-bundles-incompatible-polygon-paste-exporter.md)|
|063|@resvg/resvg-js 2.6.2|suspected|[Resvg panics when rasterizing a tightly cropped dense CAM SVG](063-resvg-panics-on-tight-cam-svg-crop.md)|

[USB4215 issues053–059](../evidence/USB4215-import-audit/tscircuit-issues/README.md) preserve the paste/mask/schema/renderer/CAM fixes and33baseline importer failures. These local reports and original inputs are included in the R6editable package. No report was deleted or published.

|[064 — Native viewer version labels stale](064-viewer-version-labels-stale-after-release.md)|@tscircuit/pcb-viewer1.11.415 /3d-viewer0.0.610|confirmed|Published build metadata mismatch; no geometry impact established|

|[065 — Copied secondary previews stale](065-r6-clone-retains-stale-secondary-previews.md)|Project release inventory /CLI0.1.2237|fixed locally|Current native BOTTOM regenerated; stale copied previews excluded|

## R7 investigation and shutter-only order review — 2026-10-04

All earlier reports remain retained, including053–059 under the USB import-audit issue directory. Torch work is cancelled;067–072 include historical investigation, not newly fitted hardware. A confirmed supplier discrepancy is not called a tscircuit bug.

|Issue|Affected package / scope|Status|
|---|---|---|
|[066 — Preview imports incompatible with locked native viewers](066-preview-imports-incompatible-with-locked-viewers.md)|Project preview integration; @tscircuit/pcb-viewer 1.11.415, schematic-viewer 2.0.99, 3d-viewer 0.0.610|fixed locally|
|[067 — Default LED paste scaling differs from manufacturer stencil recommendation](067-led-default-paste-does-not-match-manufacturer-recommendation.md)|Project stencil selection / core 0.0.2035 default paste scaling|confirmed|
|[068 — AL1793 supplier copper differs from manufacturer land pattern](068-al1793-supplier-land-pattern-discrepancy.md)|Supplier library data; easyeda converter0.0.364 reproduces the supplier model|confirmed|
|[069 — Angular LED rotation and port association investigation](069-led-angular-rotation-and-port-investigation.md)|core0.0.2035 / importer0.0.364; project emitter placement|suspected|
|[070 — Filled circular-arc paste region rejected by supported importer](070-curved-filled-paste-import-rejected.md)|easyeda0.0.364, extends USB4215 fixed commit2f52a09 on qualification/usb4215-paste-fidelity; local R7 archive is separately hashed|fixed locally|
|[071 — Mixed pad shapes use inconsistent Y bounds and port grouping](071-mixed-smtpad-bounds-y-convention.md)|@tscircuit/core0.0.2035; extends qualified USB toolchain8c7d5a5; local archive hashed separately|fixed locally|
|[072 — JST eight-position connector shell lands disagree with catalogue](072-jst8-shell-pad-dimensions-disagree-with-catalogue.md)|Supplier CAD data; easyeda0.0.364 import preserves supplied geometry|confirmed|
|[073 — CLI bundle retains older importer despite dependency override](073-cli-bundled-importer-ignores-external-override.md)|@tscircuit/cli0.1.2237 plus easyeda0.0.364 local parser extension|fixed locally|
|[074 — Protected historical R5 DFM-review archive missing](074-historical-protected-r5-archive-missing.md)|Project evidence preservation; no tscircuit package blamed|confirmed|

## R8 ESP32-C3 qualification — 2026-10-05

Earlier reports are retained unchanged from the R7 source directory. Historical evidence not copied into R8 remains in the preserved R7 project; this R8 working directory is not a complete historical release archive. The two reports below include their active local inputs and evidence.

|Issue|Affected package / scope|Status|
|---|---|---|
|[075 — ESP32-C3 outer lands differ from recommendation](075-esp32-c3-supplier-lands-differ-from-espressif-recommendation.md)|Supplier CAD C2934560; easyeda 0.0.364 faithfully preserves it|confirmed discrepancy; qualification blocked; not a confirmed tscircuit bug|
|[076 — Numeric supply label lacks power metadata](076-numeric-supply-pin-not-inferred-as-power.md)|easyeda 0.0.364 power-label inference; CLI 0.1.2237 local integration|confirmed metadata omission; not fixed|

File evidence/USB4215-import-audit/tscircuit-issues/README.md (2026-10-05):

# Local USB4215 qualification issue index

These reports extend the preserved project index without modifying protected R4/R5 documentation. Previous reports remain available through the [R1–R5 index](../../../tscircuit-issues/README.md) and the [frozen replacement-search index](../../USB-replacement-search-2026-10-03/continued-search/tscircuit-issues/README.md). No external issues were filed.

| Issue | Affected packages | Status | Classification/report |
|---|---|---|---|
|018 | Gerbonara 1.5.0 / pcb-tools 0.1.6 | confirmed limitation; alternative reader verified | [USB4215 slot readback supplement](018-g85-reader-limitation-usb4215-supplement.md) |
|053 | easyeda; circuit-json; props; util; core; SVG; Gerber | fixed locally; general suite blocked | [Paste-region pipeline](053-explicit-paste-regions-local-fix.md) |
|054 | easyeda 0.0.364 | fixed locally | [PAD paste expansion loss](054-pad-paste-expansion-dropped.md) |
|055 | circuit-json-util 0.0.117 / circuit-json 0.0.509 | fixed locally | [Outline keepout transform integration](055-outline-keepout-transform-schema-integration.md) |
|056 | easyeda 0.0.364 | fixed locally | [PAD mask expansion loss](056-pad-mask-expansion-dropped.md) |
|057 | isolated fixture dependency graph | fixed locally | [Project router override mismatch; not confirmed upstream bug](057-blanket-router-override-incompatible-with-fanout.md) |
|058 | core 0.0.2035 R4/R5 local test | fixed locally | [Stale local plated-hole paste test](058-plated-hole-paste-test-stale-after-r4-policy.md) |
|059 | isolated full importer test graph | suspected residual compatibility/expectation failures; gate blocked | [Untriaged full-suite cases and evidence](059-full-importer-suite-residual-failures.md) |

Supplier stencil suitability and undocumented manufacturer/assembler process coverage are external qualification limitations, not tscircuit bugs. The remaining 33 importer-suite failure cases and exact logs are retained in [unresolved-suite-failures.json](../logs/unresolved-suite-failures.json); they are not all relabelled as newly discovered bugs merely because their names fail.

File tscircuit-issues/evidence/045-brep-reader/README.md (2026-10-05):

Original R4 failing reader inputs, copied without alteration. Run the old manufacturing reader with the R5 native BREP Circuit JSON: `tooling/gerber-review-venv/bin/python tscircuit-issues/evidence/045-brep-reader/manufacturing-audit.py --input dist/index/circuit.json --output /tmp/r5-old-reader.json`. It rejects unsupported BREP regions; the corrected scripts and regression tests are in the main scripts/tests directories. The exporter never consumes the isolated review fixtures.

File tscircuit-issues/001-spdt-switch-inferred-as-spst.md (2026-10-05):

# Three-terminal slide switch inferred as SPST

Status: **fixed locally**. Classification: **tscircuit importer classification / missing topology input**.

## Affected package and revision

`easyeda-converter` 0.0.364, upstream base `140046d000238f3d6c8611989682efb2872f25a9`. Local source and exact locks are included under `tooling/easyeda-converter`. When this report concerns external CAM/search/project logic, this is the tscircuit package boundary examined, not an assertion that it caused the problem. Gerbonara is 1.5.0; board tscircuit is 0.0.2702, CLI version is recorded by R3 tooling evidence.

## Component and primary sources

SHOU HAN JS102011SAQN C221660 (R1); MSK12C02 C431540 (selected)

- [https://jlcpcb.com/partdetail/MSK12C02/C431540](https://jlcpcb.com/partdetail/MSK12C02/C431540)
- references/SHOUHAN-MSK12C02.pdf

## Minimal reproduction and required inputs

Run from the board root unless the first command changes directory. Inputs and regression source files are included in this editable package; the artifact list preserves original failures. `bun install --frozen-lockfile` is required in a package whose dependencies have been cleared. No publishing, ordering or account credentials are needed.

```sh
cd tooling/easyeda-converter
bun install --frozen-lockfile
bun test tests/convert-to-ts/manufacturer-metadata.test.ts
bun cli/main.ts convert -i ../../evidence/R2/C431540.raweasy.json -o /tmp/msk12c02.tsx --output-format tsx --switch-type spdt
```

For fixed reports, current regression is the post-fix MRE. To reproduce pre-fix behavior, use a disposable local checkout at the base commit, copy the identified regression tests and input fixtures, and apply the retained exact lock/dependency integration. Before logs below document the actually observed failure; do not assume an unperformed fresh upstream test passed.

## Expected behavior

Common terminal 2 selects terminal 1 or 3; shell terminal 4 is a separate mechanical land. Manufacturer drawing specifies SPDT and 1.6mm actuator travel.

## Actual behavior

R1 automatic category inference selected a two-terminal SPST symbol for a three-terminal device. Original generated import is retained.

## Logs, geometry and visual evidence

- [importer-final-full.log](evidence/001-spdt-switch-inferred-as-spst/importer-final-full.log) (unaltered copy of `evidence/R2/importer-final-full.log`)
- [C221660.raweasy.json](evidence/001-spdt-switch-inferred-as-spst/C221660.raweasy.json) (unaltered copy of `evidence/R2/C221660.raweasy.json`)
- [C431540.raweasy.json](evidence/001-spdt-switch-inferred-as-spst/C431540.raweasy.json) (unaltered copy of `evidence/R2/C431540.raweasy.json`)

Visual regressions remain alongside their source tests under `tooling/easyeda-converter/tests`; report-linked logs identify the actual runs. No missing screenshot is claimed inspected. R3 annotated metrology drawing is inspected separately from physical hardware.

## Root cause: facts and hypotheses

Confirmed: automatic category did not encode SPDT topology. A validated manufacturer topology option now reaches symbol generation.

## Impact

Lost terminal / incorrect switching semantics could invalidate the power and undervoltage interlock.

## Fix, changed files and verification

Supported --switch-type spdt; three real terminals retained. R2 full importer suite passed; board connectivity verifies pin1 BATTERY_OK, pin2 POWER_SWITCH, pin3 GND.

- `tooling/easyeda-converter/lib/websafe/convert-to-typescript-component/conversion-options.ts`
- `tooling/easyeda-converter/cli/main.ts`
- `tooling/easyeda-converter/tests/convert-to-ts/manufacturer-metadata.test.ts`

Exact local patches: [package patch](../tooling/patches/easyeda-converter.patch). Source fixture paths above and the package lock are required; patches alone do not include untracked tests. No generated component/Circuit JSON edit is a fix. Hardware verification remains pending.

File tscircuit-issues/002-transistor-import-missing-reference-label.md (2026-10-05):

# Custom transistor symbol omits dynamic reference label

Status: **fixed locally**. Classification: **tscircuit importer rendering**.

## Affected package and revision

`easyeda-converter` 0.0.364, upstream base `140046d000238f3d6c8611989682efb2872f25a9`. Local source and exact locks are included under `tooling/easyeda-converter`. When this report concerns external CAM/search/project logic, this is the tscircuit package boundary examined, not an assertion that it caused the problem. Gerbonara is 1.5.0; board tscircuit is 0.0.2702, CLI version is recorded by R3 tooling evidence.

## Component and primary sources

Jiangsu Changjing 2N7002 C8545

- [https://jlcpcb.com/partdetail/2N7002/C8545](https://jlcpcb.com/partdetail/2N7002/C8545)
- references/C8545-manufacturer.pdf

## Minimal reproduction and required inputs

Run from the board root unless the first command changes directory. Inputs and regression source files are included in this editable package; the artifact list preserves original failures. `bun install --frozen-lockfile` is required in a package whose dependencies have been cleared. No publishing, ordering or account credentials are needed.

```sh
cd tooling/easyeda-converter
bun install --frozen-lockfile
bun test tests/convert-to-ts/custom-symbol-refdes.test.ts
```

For fixed reports, current regression is the post-fix MRE. To reproduce pre-fix behavior, use a disposable local checkout at the base commit, copy the identified regression tests and input fixtures, and apply the retained exact lock/dependency integration. Before logs below document the actually observed failure; do not assume an unperformed fresh upstream test passed.

## Expected behavior

Imported symbol displays the assigned Q1/Q2 reference without replacing gate/source/drain geometry.

## Actual behavior

The original custom symbol lacked dynamically generated refdes text.

## Logs, geometry and visual evidence

- [mosfet-render.log](evidence/002-transistor-import-missing-reference-label/mosfet-render.log) (unaltered copy of `evidence/R2/mosfet-render.log`)
- [importer-final-full.log](evidence/002-transistor-import-missing-reference-label/importer-final-full.log) (unaltered copy of `evidence/R2/importer-final-full.log`)

Visual regressions remain alongside their source tests under `tooling/easyeda-converter/tests`; report-linked logs identify the actual runs. No missing screenshot is claimed inspected. R3 annotated metrology drawing is inspected separately from physical hardware.

## Root cause: facts and hypotheses

Confirmed in generated symbol conversion; source generator lacked a reference-text element.

## Impact

Schematic visual identification was missing; pin geometry itself was not corrected by a fabricated symbol.

## Fix, changed files and verification

Generator adds the dynamic reference. Snapshot changes reviewed in R2; full suite 308 passed.

- `tooling/easyeda-converter/lib/websafe/convert-to-typescript-component`
- `tooling/easyeda-converter/tests/convert-to-ts/custom-symbol-refdes.test.ts`

Exact local patches: [package patch](../tooling/patches/easyeda-converter.patch). Source fixture paths above and the package lock are required; patches alone do not include untracked tests. No generated component/Circuit JSON edit is a fix. Hardware verification remains pending.

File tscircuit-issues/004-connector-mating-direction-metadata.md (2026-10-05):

# Connector import cannot specify verified mating direction

Status: **fixed locally**. Classification: **tscircuit importer metadata limitation**.

## Affected package and revision

`easyeda-converter` 0.0.364, upstream base `140046d000238f3d6c8611989682efb2872f25a9`. Local source and exact locks are included under `tooling/easyeda-converter`. When this report concerns external CAM/search/project logic, this is the tscircuit package boundary examined, not an assertion that it caused the problem. Gerbonara is 1.5.0; board tscircuit is 0.0.2702, CLI version is recorded by R3 tooling evidence.

## Component and primary sources

JST S2B-PH-SM4-TB(LF)(SN) C295747; BM06B-SRSS-TB(LF)(SN) C160392

- [https://www.jst-mfg.com/product/pdf/eng/ePH.pdf](https://www.jst-mfg.com/product/pdf/eng/ePH.pdf)
- [https://www.jst-mfg.com/product/pdf/eng/eSH.pdf](https://www.jst-mfg.com/product/pdf/eng/eSH.pdf)

## Minimal reproduction and required inputs

Run from the board root unless the first command changes directory. Inputs and regression source files are included in this editable package; the artifact list preserves original failures. `bun install --frozen-lockfile` is required in a package whose dependencies have been cleared. No publishing, ordering or account credentials are needed.

```sh
cd tooling/easyeda-converter
bun test tests/convert-to-ts/manufacturer-metadata.test.ts
bun cli/main.ts convert -i ../../evidence/R2/C160392.raweasy.json -o /tmp/sh.tsx --output-format tsx --insertion-direction from_above
```

For fixed reports, current regression is the post-fix MRE. To reproduce pre-fix behavior, use a disposable local checkout at the base commit, copy the identified regression tests and input fixtures, and apply the retained exact lock/dependency integration. Before logs below document the actually observed failure; do not assume an unperformed fresh upstream test passed.

## Expected behavior

PH mates from −Y, SH from +Z in the unrotated footprint. Metadata must agree with actual manufacturer drawings.

## Actual behavior

Automatic generic connector treatment did not establish actual insertion direction. Missing metadata made edge/access checks unreliable.

## Logs, geometry and visual evidence

- [importer-connector-symbol-review.log](evidence/004-connector-mating-direction-metadata/importer-connector-symbol-review.log) (unaltered copy of `evidence/R2/importer-connector-symbol-review.log`)
- [C160392.raweasy.json](evidence/004-connector-mating-direction-metadata/C160392.raweasy.json) (unaltered copy of `evidence/R2/C160392.raweasy.json`)
- [C295747.raweasy.json](evidence/004-connector-mating-direction-metadata/C295747.raweasy.json) (unaltered copy of `evidence/R2/C295747.raweasy.json`)

Visual regressions remain alongside their source tests under `tooling/easyeda-converter/tests`; report-linked logs identify the actual runs. No missing screenshot is claimed inspected. R3 annotated metrology drawing is inspected separately from physical hardware.

## Root cause: facts and hypotheses

Confirmed capability gap; physical direction must be established from manufacturer drawing, not guessed from an image.

## Impact

Incorrect enclosure opening, inaccessible mating or misleading placement warning.

## Fix, changed files and verification

Validated six-axis --insertion-direction supplied at source conversion. R3 retained actual PH/SH parts with all electronics top.

- `tooling/easyeda-converter/lib/websafe/convert-to-typescript-component/conversion-options.ts`
- `tooling/easyeda-converter/cli/main.ts`
- `tooling/easyeda-converter/tests/convert-to-ts/manufacturer-metadata.test.ts`

Exact local patches: [package patch](../tooling/patches/easyeda-converter.patch). Source fixture paths above and the package lock are required; patches alone do not include untracked tests. No generated component/Circuit JSON edit is a fix. Hardware verification remains pending.

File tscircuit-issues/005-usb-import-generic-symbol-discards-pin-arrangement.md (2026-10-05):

# Generic USB symbol loses supplier pin arrangement

Status: **fixed locally**. Classification: **tscircuit importer symbol classification**.

## Affected package and revision

`easyeda-converter` 0.0.364, upstream base `140046d000238f3d6c8611989682efb2872f25a9`. Local source and exact locks are included under `tooling/easyeda-converter`. When this report concerns external CAM/search/project logic, this is the tscircuit package boundary examined, not an assertion that it caused the problem. Gerbonara is 1.5.0; board tscircuit is 0.0.2702, CLI version is recorded by R3 tooling evidence.

## Component and primary sources

GCT USB4105-GF-A-120 C5184243 (R2)

- [https://jlcpcb.com/partdetail/USB4105_GF_A_120/C5184243](https://jlcpcb.com/partdetail/USB4105_GF_A_120/C5184243)
- references/GCT-USB4105-120.pdf

## Minimal reproduction and required inputs

Run from the board root unless the first command changes directory. Inputs and regression source files are included in this editable package; the artifact list preserves original failures. `bun install --frozen-lockfile` is required in a package whose dependencies have been cleared. No publishing, ordering or account credentials are needed.

```sh
cd tooling/easyeda-converter
bun test tests/convert-to-ts/usb-type-c-category.test.ts
```

For fixed reports, current regression is the post-fix MRE. To reproduce pre-fix behavior, use a disposable local checkout at the base commit, copy the identified regression tests and input fixtures, and apply the retained exact lock/dependency integration. Before logs below document the actually observed failure; do not assume an unperformed fresh upstream test passed.

## Expected behavior

USB connector preserves real custom symbol, repeated shell lands and actual CC/power aliases.

## Actual behavior

Connector classification used a generic connector symbol instead of the supplier custom symbol.

## Logs, geometry and visual evidence

- [connector-symbol-before.log](evidence/005-usb-import-generic-symbol-discards-pin-arrangement/connector-symbol-before.log) (unaltered copy of `evidence/R2/connector-symbol-before.log`)
- [connector-symbol-after.log](evidence/005-usb-import-generic-symbol-discards-pin-arrangement/connector-symbol-after.log) (unaltered copy of `evidence/R2/connector-symbol-after.log`)
- [C5184243.raweasy.json](evidence/005-usb-import-generic-symbol-discards-pin-arrangement/C5184243.raweasy.json) (unaltered copy of `evidence/R2/C5184243.raweasy.json`)

Visual regressions remain alongside their source tests under `tooling/easyeda-converter/tests`; report-linked logs identify the actual runs. No missing screenshot is claimed inspected. R3 annotated metrology drawing is inspected separately from physical hardware.

## Root cause: facts and hypotheses

Confirmed classification path replaced the richer input symbol. Geometry/pin identity must be preserved independently of component category.

## Impact

Incorrect or ambiguous schematic correspondence to physical contacts.

## Fix, changed files and verification

USB classification retains source custom symbol and pin aliases. Before/after connector logs and fixture preserved.

- `tooling/easyeda-converter/lib/websafe/convert-to-typescript-component`
- `tooling/easyeda-converter/tests/convert-to-ts/usb-type-c-category.test.ts`

Exact local patches: [package patch](../tooling/patches/easyeda-converter.patch). Source fixture paths above and the package lock are required; patches alone do not include untracked tests. No generated component/Circuit JSON edit is a fix. Hardware verification remains pending.

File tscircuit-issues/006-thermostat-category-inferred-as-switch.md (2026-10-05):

# Thermostat category incorrectly inferred as mechanical switch

Status: **fixed locally**. Classification: **tscircuit importer classification**.

## Affected package and revision

`easyeda-converter` 0.0.364, upstream base `140046d000238f3d6c8611989682efb2872f25a9`. Local source and exact locks are included under `tooling/easyeda-converter`. When this report concerns external CAM/search/project logic, this is the tscircuit package boundary examined, not an assertion that it caused the problem. Gerbonara is 1.5.0; board tscircuit is 0.0.2702, CLI version is recorded by R3 tooling evidence.

## Component and primary sources

Texas Instruments TMP390A2DRLR C5219772

- [https://www.ti.com/lit/ds/symlink/tmp390.pdf](https://www.ti.com/lit/ds/symlink/tmp390.pdf)

## Minimal reproduction and required inputs

Run from the board root unless the first command changes directory. Inputs and regression source files are included in this editable package; the artifact list preserves original failures. `bun install --frozen-lockfile` is required in a package whose dependencies have been cleared. No publishing, ordering or account credentials are needed.

```sh
cd tooling/easyeda-converter
bun test tests/convert-to-ts/thermostat-category.test.ts
```

For fixed reports, current regression is the post-fix MRE. To reproduce pre-fix behavior, use a disposable local checkout at the base commit, copy the identified regression tests and input fixtures, and apply the retained exact lock/dependency integration. Before logs below document the actually observed failure; do not assume an unperformed fresh upstream test passed.

## Expected behavior

Six-pin powered TMP390 thermostat retains its actual IC symbol and terminals.

## Actual behavior

A category name containing SWITCH caused mechanical-switch inference.

## Logs, geometry and visual evidence

- [thermostat-before.log](evidence/006-thermostat-category-inferred-as-switch/thermostat-before.log) (unaltered copy of `evidence/R2/thermostat-before.log`)
- [thermostat-after.log](evidence/006-thermostat-category-inferred-as-switch/thermostat-after.log) (unaltered copy of `evidence/R2/thermostat-after.log`)
- [C5219772.raweasy.json](evidence/006-thermostat-category-inferred-as-switch/C5219772.raweasy.json) (unaltered copy of `evidence/R2/C5219772.raweasy.json`)

Visual regressions remain alongside their source tests under `tooling/easyeda-converter/tests`; report-linked logs identify the actual runs. No missing screenshot is claimed inspected. R3 annotated metrology drawing is inspected separately from physical hardware.

## Root cause: facts and hypotheses

Confirmed overly broad substring classification.

## Impact

Temperature interlock schematic could lose IC pins and semantics.

## Fix, changed files and verification

Exclude thermostat category from mechanical switch inference; regenerate C5219772 through supported converter.

- `tooling/easyeda-converter/lib/websafe/convert-to-typescript-component`
- `tooling/easyeda-converter/tests/convert-to-ts/thermostat-category.test.ts`

Exact local patches: [package patch](../tooling/patches/easyeda-converter.patch). Source fixture paths above and the package lock are required; patches alone do not include untracked tests. No generated component/Circuit JSON edit is a fix. Hardware verification remains pending.

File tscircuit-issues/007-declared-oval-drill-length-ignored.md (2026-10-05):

# Declared oval drill length replaced by inferred equal annulus

Status: **fixed locally**. Classification: **confirmed tscircuit geometry conversion bug**.

## Affected package and revision

`easyeda-converter` 0.0.364, upstream base `140046d000238f3d6c8611989682efb2872f25a9`. Local source and exact locks are included under `tooling/easyeda-converter`. When this report concerns external CAM/search/project logic, this is the tscircuit package boundary examined, not an assertion that it caused the problem. Gerbonara is 1.5.0; board tscircuit is 0.0.2702, CLI version is recorded by R3 tooling evidence.

## Component and primary sources

USB connector fixtures including HRO TYPE-C-31-M-17 C283540; GCT C5184243

- references/GCT-USB4105-120.pdf
- [https://docs.tscircuit.com/](https://docs.tscircuit.com/)

## Minimal reproduction and required inputs

Run from the board root unless the first command changes directory. Inputs and regression source files are included in this editable package; the artifact list preserves original failures. `bun install --frozen-lockfile` is required in a package whose dependencies have been cleared. No publishing, ordering or account credentials are needed.

```sh
cd tooling/easyeda-converter
bun test tests/convert-to-soup-tests/declared-slot-length.test.ts
```

For fixed reports, current regression is the post-fix MRE. To reproduce pre-fix behavior, use a disposable local checkout at the base commit, copy the identified regression tests and input fixtures, and apply the retained exact lock/dependency integration. Before logs below document the actually observed failure; do not assume an unperformed fresh upstream test passed.

## Expected behavior

Use declared EasyEDA holeLength; maintain independent outer copper and drill dimensions at 0/90/180/270 degrees.

## Actual behavior

Regression: declared 1.2mm drill became 1.2999974mm; before run failed at four rotations.

## Logs, geometry and visual evidence

- [slot-length-before.log](evidence/007-declared-oval-drill-length-ignored/slot-length-before.log) (unaltered copy of `evidence/R2/slot-length-before.log`)
- [slot-length-after.log](evidence/007-declared-oval-drill-length-ignored/slot-length-after.log) (unaltered copy of `evidence/R2/slot-length-after.log`)
- [importer-slot-full.log](evidence/007-declared-oval-drill-length-ignored/importer-slot-full.log) (unaltered copy of `evidence/R2/importer-slot-full.log`)

Visual regressions remain alongside their source tests under `tooling/easyeda-converter/tests`; report-linked logs identify the actual runs. No missing screenshot is claimed inspected. R3 annotated metrology drawing is inspected separately from physical hardware.

## Root cause: facts and hypotheses

Confirmed parser/converter ignored the declared holeLength field and inferred from outer copper dimensions.

## Impact

Wrong drill lengths, annular rings and connector fit; affected exports.

## Fix, changed files and verification

Parse and convert declared length. Five tests / 26 assertions pass; supplier payloads are unmodified. RECT-hole inference is not claimed fixed and not used by fitted parts.

- `tooling/easyeda-converter/lib`
- `tooling/easyeda-converter/tests/convert-to-soup-tests/declared-slot-length.test.ts`

Exact local patches: [package patch](../tooling/patches/easyeda-converter.patch). Source fixture paths above and the package lock are required; patches alone do not include untracked tests. No generated component/Circuit JSON edit is a fix. Hardware verification remains pending.

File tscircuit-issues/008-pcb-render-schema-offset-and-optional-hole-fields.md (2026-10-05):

# Core emits PCB fields incompatible with Circuit JSON schema

Status: **fixed locally**. Classification: **confirmed cross-package schema incompatibility**.

## Affected package and revision

`core` 0.0.2035, upstream base `3fcbb3842b8ab1c0af324078f6eb55c3dbcba1a0`. Local source and exact locks are included under `tooling/core`. When this report concerns external CAM/search/project logic, this is the tscircuit package boundary examined, not an assertion that it caused the problem. Gerbonara is 1.5.0; board tscircuit is 0.0.2702, CLI version is recorded by R3 tooling evidence.

## Component and primary sources

Not component-specific; board hole and imported component fixture

- [https://github.com/tscircuit/circuit-json](https://github.com/tscircuit/circuit-json)
- [https://github.com/tscircuit/core](https://github.com/tscircuit/core)

## Minimal reproduction and required inputs

Run from the board root unless the first command changes directory. Inputs and regression source files are included in this editable package; the artifact list preserves original failures. `bun install --frozen-lockfile` is required in a package whose dependencies have been cleared. No publishing, ordering or account credentials are needed.

```sh
cd tooling/core
bun test tests/repros/repro-pcb-schema-export.test.tsx
```

For fixed reports, current regression is the post-fix MRE. To reproduce pre-fix behavior, use a disposable local checkout at the base commit, copy the identified regression tests and input fixtures, and apply the retained exact lock/dependency integration. Before logs below document the actually observed failure; do not assume an unperformed fresh upstream test passed.

## Expected behavior

The entire emitted Circuit JSON parses with any_circuit_element.array(); distance offsets use accepted unit strings and absent optional holes use undefined.

## Actual behavior

Expected display_offset_x "-2mm", received numeric -2. Optional holes included null in incompatible fields.

## Logs, geometry and visual evidence

- [core-schema-before.log](evidence/008-pcb-render-schema-offset-and-optional-hole-fields/core-schema-before.log) (unaltered copy of `evidence/R2/core-schema-before.log`)
- [core-schema-after.log](evidence/008-pcb-render-schema-offset-and-optional-hole-fields/core-schema-after.log) (unaltered copy of `evidence/R2/core-schema-after.log`)
- [core-regression-final.log](evidence/008-pcb-render-schema-offset-and-optional-hole-fields/core-regression-final.log) (unaltered copy of `evidence/R2/core-regression-final.log`)

Visual regressions remain alongside their source tests under `tooling/core/tests`; report-linked logs identify the actual runs. No missing screenshot is claimed inspected. R3 annotated metrology drawing is inspected separately from physical hardware.

## Root cause: facts and hypotheses

Confirmed emitted core representations disagreed with installed schema.

## Impact

Fabrication converters could reject or drop geometry; schema validation blocked.

## Fix, changed files and verification

Correct producer representation; no circuit JSON patching. Schema regression and focused core tests passed.

- `tooling/core/lib/components/base-components`
- `tooling/core/lib/components/primitive-components`
- `tooling/core/tests/repros/repro-pcb-schema-export.test.tsx`

Exact local patches: [package patch](../tooling/patches/core.patch). Source fixture paths above and the package lock are required; patches alone do not include untracked tests. No generated component/Circuit JSON edit is a fix. Hardware verification remains pending.

## R4 audit-consumer integration note — resolved project invocation

A read-only legend attribution helper initially imported the canonical Gerber converter's TypeScript source into the board typecheck. This is a project integration mistake, not a new confirmed converter defect: the converter's own installed Circuit JSON is 0.0.487 whereas the board is locked to corrected 0.0.509; the broader board material union includes `flex`, and direct cross-repository compilation also lacks the converter's `src/*` alias. Exact errors: TS2322 (`"flex"` not assignable to `"fr4" | "fr1"`) and TS2307 (`src/gerber/any_gerber_command`). No type escape, weakened typecheck or dependency substitution was used.

Original [helper input](../evidence/R4/legend-source-import-failure.ts) and [actual failure log](../evidence/R4/legend-direct-source-typecheck-failure.log) preserved. Reproduce from the board root by copying that exact helper to `scripts/render-legend-review.repro.ts` and running `node_modules/.bin/tsc --noEmit`; remove only that newly created reproduction file afterwards. Corrected workflow: `tooling/gerber-review-venv/bin/python scripts/render-legend-review.py` invokes the supported built converter CLI on selected original board/text review fixtures. Original full Circuit JSON is not changed; all isolated glyph geometry is verified against the complete original TOP legend. Final board format/typecheck pass. This records a resolved invocation error, not a claim that arbitrary cross-source package versions became interchangeable.

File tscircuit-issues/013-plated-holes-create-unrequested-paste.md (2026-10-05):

# Plated holes generate unrequested stencil paste on both faces

Status: **fixed locally**. Classification: **confirmed core fabrication geometry bug**.

## Affected package and revision

`core` 0.0.2035, upstream base `3fcbb3842b8ab1c0af324078f6eb55c3dbcba1a0`. Local source and exact locks are included under `tooling/core`. When this report concerns external CAM/search/project logic, this is the tscircuit package boundary examined, not an assertion that it caused the problem. Gerbonara is 1.5.0; board tscircuit is 0.0.2702, CLI version is recorded by R3 tooling evidence.

## Component and primary sources

USB4105-GF-A-120 C5184243; shell plated slots

- [https://jlcpcb.com/help/article/smt-stencil-data-prepared-for-smt-orders](https://jlcpcb.com/help/article/smt-stencil-data-prepared-for-smt-orders)

## Minimal reproduction and required inputs

Run from the board root unless the first command changes directory. Inputs and regression source files are included in this editable package; the artifact list preserves original failures. `bun install --frozen-lockfile` is required in a package whose dependencies have been cleared. No publishing, ordering or account credentials are needed.

```sh
cd tooling/core
bun test tests/repros/repro-plated-hole-unrequested-paste.test.tsx
```

For fixed reports, current regression is the post-fix MRE. To reproduce pre-fix behavior, use a disposable local checkout at the base commit, copy the identified regression tests and input fixtures, and apply the retained exact lock/dependency integration. Before logs below document the actually observed failure; do not assume an unperformed fresh upstream test passed.

## Expected behavior

No paste for a plated hole unless explicitly supplied by a qualified process/source design.

## Actual behavior

Default plated-hole rendering emitted top and bottom paste apertures.

## Logs, geometry and visual evidence

- [plated-paste-before.log](evidence/013-plated-holes-create-unrequested-paste/plated-paste-before.log) (unaltered copy of `evidence/R2/plated-paste-before.log`)
- [plated-paste-after.log](evidence/013-plated-holes-create-unrequested-paste/plated-paste-after.log) (unaltered copy of `evidence/R2/plated-paste-after.log`)

Visual regressions remain alongside their source tests under `tooling/core/tests`; report-linked logs identify the actual runs. No missing screenshot is claimed inspected. R3 annotated metrology drawing is inspected separately from physical hardware.

## Root cause: facts and hypotheses

Confirmed automatic default paste generation.

## Impact

Bottom stencil falsely implied assembly and shell solder volume was unqualified.

## Fix, changed files and verification

Remove automatic paste; retain explicit native paste support. Regression passed. Hybrid shell solder process remains a manufacturing-process question.

- `tooling/core/lib/components/primitive-components/PlatedHole.ts`
- `tooling/core/tests/repros/repro-plated-hole-unrequested-paste.test.tsx`

Exact local patches: [package patch](../tooling/patches/core.patch). Source fixture paths above and the package lock are required; patches alone do not include untracked tests. No generated component/Circuit JSON edit is a fix. Hardware verification remains pending.

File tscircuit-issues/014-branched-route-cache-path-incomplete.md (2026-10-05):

# Branched route cannot be saved as a simple endpoint path

Status: **suspected**. Classification: **observed warning; root cause not confirmed**.

## Affected package and revision

`core` 0.0.2035, upstream base `3fcbb3842b8ab1c0af324078f6eb55c3dbcba1a0`. Local source and exact locks are included under `tooling/core`. When this report concerns external CAM/search/project logic, this is the tscircuit package boundary examined, not an assertion that it caused the problem. Gerbonara is 1.5.0; board tscircuit is 0.0.2702, CLI version is recorded by R3 tooling evidence.

## Component and primary sources

USB connector J1; previously C5184243

- [https://github.com/tscircuit/core](https://github.com/tscircuit/core)

## Minimal reproduction and required inputs

Run from the board root unless the first command changes directory. Inputs and regression source files are included in this editable package; the artifact list preserves original failures. `bun install --frozen-lockfile` is required in a package whose dependencies have been cleared. No publishing, ordering or account credentials are needed.

```sh
bunx tsci build index.circuit.tsx --pcb-png
# See preserved R2 source/circuit under evidence/R3/R2-inputs for original warning.
```

For fixed reports, current regression is the post-fix MRE. To reproduce pre-fix behavior, use a disposable local checkout at the base commit, copy the identified regression tests and input fixtures, and apply the retained exact lock/dependency integration. Before logs below document the actually observed failure; do not assume an unperformed fresh upstream test passed.

## Expected behavior

Complete branched routing geometry should serialize without a false endpoint-path failure.

## Actual behavior

Could not save autorouting paths for subcircuit_source_group_0: Saved phase path ".J1 > port.EH1" must end at another connection endpoint; use autorouter="fanout" for saved escapes.

## Logs, geometry and visual evidence

- [R2-final-build.log](evidence/014-branched-route-cache-path-incomplete/R2-final-build.log) (unaltered copy of `evidence/R2/R2-final-build.log`)
- [remote-circuit.tsx](evidence/014-branched-route-cache-path-incomplete/remote-circuit.tsx) (unaltered copy of `evidence/R3/R2-inputs/src/remote-circuit.tsx`)

Visual regressions remain alongside their source tests under `tooling/core/tests`; report-linked logs identify the actual runs. No missing screenshot is claimed inspected. R3 annotated metrology drawing is inspected separately from physical hardware.

## Root cause: facts and hypotheses

Confirmed warning, generated copper exists. Hypothesis: branched physical port cluster is reduced to a simple path. Root cause not yet demonstrated with a reduced fixture.

## Impact

Fresh builds may reroute; cache stability is unverified. Native connectivity success does not prove cache serialization correct.

## Fix, changed files and verification

Open. No cache warning is suppressed or claimed fixed. R2 failing source and actual output preserved.

No component geometry or package source changed for this finding.

Exact local patches: [package patch](../tooling/patches/core.patch). Source fixture paths above and the package lock are required; patches alone do not include untracked tests. No generated component/Circuit JSON edit is a fix. Hardware verification remains pending.

## Final R3 disposition (2026-10-02)

Warning remains explicit: port-only replay API cannot serialize global junction/breakout-exit routes. It does not suppress routing errors. No saved global cache path is used by this design; repeat native source builds, checks and snapshot generation passed. Fresh recomputation is accepted for R3.

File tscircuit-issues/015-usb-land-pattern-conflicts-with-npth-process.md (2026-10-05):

# Manufacturer USB land pattern fails JLC NPTH clearance

Status: **confirmed**. Classification: **manufacturing limitation, not a tscircuit defect**.

## Affected package and revision

`easyeda-converter` 0.0.364, upstream base `140046d000238f3d6c8611989682efb2872f25a9`. Local source and exact locks are included under `tooling/easyeda-converter`. When this report concerns external CAM/search/project logic, this is the tscircuit package boundary examined, not an assertion that it caused the problem. Gerbonara is 1.5.0; board tscircuit is 0.0.2702, CLI version is recorded by R3 tooling evidence.

## Component and primary sources

GCT USB4105-GF-A-120 C5184243

- [https://jlcpcb.com/blog/npth-design-guide](https://jlcpcb.com/blog/npth-design-guide)
- references/GCT-USB4105-120.pdf

## Minimal reproduction and required inputs

Run from the board root unless the first command changes directory. Inputs and regression source files are included in this editable package; the artifact list preserves original failures. `bun install --frozen-lockfile` is required in a package whose dependencies have been cleared. No publishing, ordering or account credentials are needed.

```sh
tooling/gerber-review-venv/bin/python scripts/measure-j1-export.py
```

For fixed reports, current regression is the post-fix MRE. To reproduce pre-fix behavior, use a disposable local checkout at the base commit, copy the identified regression tests and input fixtures, and apply the retained exact lock/dependency integration. Before logs below document the actually observed failure; do not assume an unperformed fresh upstream test passed.

## Expected behavior

NPTH to all copper >=0.2mm for the selected fabrication process, including same-footprint SMT lands.

## Actual behavior

Exported right locator pcb_hole_1 to J1 pin7/GND2: 0.175263821mm. Left locator: 0.175268908mm. Manufacturer nominal 0.175099990mm.

## Logs, geometry and visual evidence

- [j1-export-metrology.json](evidence/015-usb-land-pattern-conflicts-with-npth-process/j1-export-metrology.json) (unaltered copy of `evidence/R3/j1-export-metrology.json`)
- [j1-export-metrology.log](evidence/015-usb-land-pattern-conflicts-with-npth-process/j1-export-metrology.log) (unaltered copy of `evidence/R3/j1-export-metrology.log`)
- [j1-clearance-annotated.png](evidence/015-usb-land-pattern-conflicts-with-npth-process/j1-clearance-annotated.png) (unaltered copy of `evidence/R3/j1-clearance-annotated.png`)
- [USB4105_GF_A_120.tsx](evidence/015-usb-land-pattern-conflicts-with-npth-process/USB4105_GF_A_120.tsx) (unaltered copy of `evidence/R3/R2-inputs/imports/USB4105_GF_A_120.tsx`)

Visual regressions remain alongside their source tests under `tooling/easyeda-converter/tests`; report-linked logs identify the actual runs. No missing screenshot is claimed inspected. R3 annotated metrology drawing is inspected separately from physical hardware.

## Root cause: facts and hypotheses

Confirmed exported source agrees with manufacturer nominal pattern within CAD quantization. Therefore the process conflict is real; it is not fixed by changing a check or pad.

## Impact

R2 fabrication was blocked.

## Fix, changed files and verification

R3 selects supported import C5252714 with no locating holes and manufacturer-matching pads/slots. Original R2 source/export evidence preserved.

No component geometry or package source changed for this finding.

Exact local patches: [package patch](../tooling/patches/easyeda-converter.patch). Source fixture paths above and the package lock are required; patches alone do not include untracked tests. No generated component/Circuit JSON edit is a fix. Hardware verification remains pending.

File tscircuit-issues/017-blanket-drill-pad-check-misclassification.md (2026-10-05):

# Project drill audit uses one threshold and omits tracks and pours

Status: **fixed locally**. Classification: **project checker mistake, not a tscircuit defect**.

## Affected package and revision

Project `scripts/audit-drills.ts` in R2 and `scripts/manufacturing-audit.py` in R3; exact source revisions are captured in the package manifests. This is project checker logic, not @tscircuit/core code.

## Component and primary sources

R2 board; USB J1 and all drills

- [https://jlcpcb.com/capabilities/pcb-capabilities](https://jlcpcb.com/capabilities/pcb-capabilities)
- [https://jlcpcb.com/blog/npth-design-guide](https://jlcpcb.com/blog/npth-design-guide)

## Minimal reproduction and required inputs

Run from the board root unless the first command changes directory. Inputs and regression source files are included in this editable package; the artifact list preserves original failures. `bun install --frozen-lockfile` is required in a package whose dependencies have been cleared. No publishing, ordering or account credentials are needed.

```sh
tooling/gerber-review-venv/bin/python -m unittest discover -s tests -p test_manufacturing_audit.py -v
tooling/gerber-review-venv/bin/python scripts/manufacturing-audit.py --input evidence/R3/R2-inputs/dist/index/circuit.json --output evidence/R3/r2-classified-audit.json
```

For fixed reports, current regression is the post-fix MRE. To reproduce pre-fix behavior, use a disposable local checkout at the base commit, copy the identified regression tests and input fixtures, and apply the retained exact lock/dependency integration. Before logs below document the actually observed failure; do not assume an unperformed fresh upstream test passed.

## Expected behavior

Classify NPTH/PTH/vias, layer spans, own annuli, actual electrical feeds, unrelated SMT/trace/pour copper; no same-footprint exemption.

## Actual behavior

Old scripts/audit-drills.ts applies blanket 0.2mm hole-to-SMT pad clearance, excluding trace/pour and hole-hole relationships.

## Logs, geometry and visual evidence

- [audit-drills.ts](evidence/017-blanket-drill-pad-check-misclassification/audit-drills.ts) (unaltered copy of `evidence/R3/R2-inputs/scripts/audit-drills.ts`)
- [manufacturing-audit-current.log](evidence/017-blanket-drill-pad-check-misclassification/manufacturing-audit-current.log) (unaltered copy of `evidence/R3/manufacturing-audit-current.log`)
- [manufacturing-regression-final.log](evidence/017-blanket-drill-pad-check-misclassification/manufacturing-regression-final.log) (unaltered copy of `evidence/R3/manufacturing-regression-final.log`)

Visual regressions remain alongside their source tests under `tooling/core/tests`; report-linked logs identify the actual runs. No missing screenshot is claimed inspected. R3 annotated metrology drawing is inspected separately from physical hardware.

## Root cause: facts and hypotheses

Confirmed project script coverage error. Official minima differ by drill type/layer/feature. Additional project constraints are explicitly identified as such.

## Impact

Incomplete manufacturing evidence despite native connectivity passes.

## Fix, changed files and verification

New Shapely audit and regression tests; NPTH still 0.2mm. Via ring .05mm; 2-layer PTH absolute ring .18mm; PTH-track .28mm; via-track .2mm. Unsupported geometry fails closed. Nine initial tests pass.

No component geometry or package source changed for this finding.

Exact local patches: [package patch](../tooling/patches/core.patch). Source fixture paths above and the package lock are required; patches alone do not include untracked tests. No generated component/Circuit JSON edit is a fix. Hardware verification remains pending.

## Final R3 disposition (2026-10-02)

Project checker now includes traces/pours and explicit internally connected ports/actual shared conductive pads. No threshold was lowered. See issue [036](036-independent-checker-internal-pads-and-net-recursion.md). Current independent audit: zero failures; 25 board/checker regression tests pass.

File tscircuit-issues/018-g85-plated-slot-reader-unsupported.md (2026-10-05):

# Gerbonara cannot parse native exported G85 plated slots

Status: **confirmed**. Classification: **external CAM reader limitation; distinct converter defects subsequently confirmed in 024/025**.

## Affected package and revision

`core` 0.0.2035, upstream base `3fcbb3842b8ab1c0af324078f6eb55c3dbcba1a0`. Local source and exact locks are included under `tooling/core`. When this report concerns external CAM/search/project logic, this is the tscircuit package boundary examined, not an assertion that it caused the problem. Gerbonara is 1.5.0; board tscircuit is 0.0.2702, CLI version is recorded by R3 tooling evidence.

## Component and primary sources

USB plated shell slots; C5184243 R2, C5252714 R3

- [https://github.com/jaseg/gerbonara](https://github.com/jaseg/gerbonara)
- [https://docs.kicad.org/](https://docs.kicad.org/)

## Minimal reproduction and required inputs

Run from the board root unless the first command changes directory. Inputs and regression source files are included in this editable package; the artifact list preserves original failures. `bun install --frozen-lockfile` is required in a package whose dependencies have been cleared. No publishing, ordering or account credentials are needed.

```sh
tooling/gerber-review-venv/bin/python -c 'from gerbonara import ExcellonFile; ExcellonFile.open("fabrication/review-gerbers/drill-L1-L2.drl")'
```

For fixed reports, current regression is the post-fix MRE. To reproduce pre-fix behavior, use a disposable local checkout at the base commit, copy the identified regression tests and input fixtures, and apply the retained exact lock/dependency integration. Before logs below document the actually observed failure; do not assume an unperformed fresh upstream test passed.

## Expected behavior

Independent CAM reader must load every drill and slot. A partial copper preview is insufficient.

## Actual behavior

Gerbonara 1.5.0 rejects G85. Original failure log retained. NPTH reads but warns: G90 header statement found after end of header.

## Logs, geometry and visual evidence

- [gerber-parse.log](evidence/018-g85-plated-slot-reader-unsupported/gerber-parse.log) (unaltered copy of `evidence/R2/gerber-parse.log`)
- [j1-export-metrology.log](evidence/018-g85-plated-slot-reader-unsupported/j1-export-metrology.log) (unaltered copy of `evidence/R3/j1-export-metrology.log`)

Visual regressions remain alongside their source tests under `tooling/core/tests`; report-linked logs identify the actual runs. No missing screenshot is claimed inspected. R3 annotated metrology drawing is inspected separately from physical hardware.

## Root cause: facts and hypotheses

Confirmed reader lacks G85 handling. Whether particular assembler accepts native output remains unverified; numeric endpoint comparison alone is not full CAM review.

## Impact

Plated slots omitted from Gerbonara preview.

## Fix, changed files and verification

R3 independent complete-reader review is tracked in VALIDATION.md. No file rewrite or fabricated replacement exports.

No component geometry or package source changed for this finding.

Exact local patches: [package patch](../tooling/patches/core.patch). Source fixture paths above and the package lock are required; patches alone do not include untracked tests. No generated component/Circuit JSON edit is a fix. Hardware verification remains pending.

## R3 follow-up

Gerbonara still lacks G85 support. Report [024](024-excellon-g85-slot-record-and-mode-export.md) now confirms a separate native-export interpretation defect observed in KiCad. An unmodified independent reader, pcb-tools 0.1.6, parses the corrected supported export and measures all four slots against source. This does not complete copper, mask, paste or full-board validation.

## Final R3 disposition (2026-10-02)

Affected reader is Gerbonara 1.5.0, not core. Alternative independent pcb-tools 0.1.6 now reads all 106 plated drills (102 vias, four slots) and four NPTH features in the current unmodified export. Both copper layers, all 12 files and every slot/round feature match source: [readback](../evidence/R3/final-cam-readback/readback.json). Gerbonara’s G85 limitation remains; no partial preview is called complete.

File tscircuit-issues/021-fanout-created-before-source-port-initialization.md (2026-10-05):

# Fanout points are created before custom-symbol ports and trace identities initialize

Status: **fixed locally**. Classification: **tscircuit render-phase ordering defect**.

## 1. Affected package and exact revision

@tscircuit/core 0.0.2035; base 3fcbb3842b8ab1c0af324078f6eb55c3dbcba1a0. Working dependency archives/locks are kept in `tooling/vendor/` and the board manifest. Fixed locally never means published upstream.

## 2. Components and sources

SHOU HAN MSK12C02 / C431540; Jiangsu Changjing Electronics Technology 2N7002 / C8545. Unaltered fitted supplier imports are the regression fixtures.

- [Core source](https://github.com/tscircuit/core/tree/3fcbb3842b8ab1c0af324078f6eb55c3dbcba1a0)
- [Gerber converter source](https://github.com/tscircuit/circuit-json-to-gerber/tree/40dbb6c0ebae9c63ef5a52292e8521de6060c548)
- [JLCPCB C431540](https://jlcpcb.com/partdetail/C431540), [C8545](https://jlcpcb.com/partdetail/C8545), [C5184243](https://jlcpcb.com/partdetail/C5184243), [C5252714](https://jlcpcb.com/partdetail/C5252714)
- [Excellon programming manual](https://static1.squarespace.com/static/54982a02e4b02e9f5e5d9ca7/t/577e77209f74568b965f785e/1467905825798/Excellon%2BAutomation%2BCo.pdf)
- [KiCad Excellon reader source](https://docs.kicad.org/doxygen/excellon__read__drill__file_8cpp_source.html)

## 3. Minimal reproduction and required inputs

Run test commands from the identified tooling package directory; project build/converter commands from the board root. Install the retained package lock with Bun 1.3.9. Imported fixture files retain their supplier source geometry. Before logs identify actually reproduced failures, not guessed upstream outcomes.

```sh
bun test tests/repros/repro-fanout-later-custom-symbol.test.tsx
```

## 4. Expected behavior

Ports and source-trace identities must exist before fanout boundary points resolve them. See core docs/saved-fanout-trace-paths.md and SourceRender/SourceTraceRender phase implementations.

## 5. Actual behavior

Before fix, fanout creation throws a source_trace_not_connected_error for a later custom-symbol port. Moving the phase only before SourceTraceRender instead produces "point without a source trace identity".

## 6. Evidence

- [fanout-symbol-before.log](evidence/021-fanout-created-before-source-port-initialization/fanout-symbol-before.log) — original `evidence/R3/fanout-symbol-before.log`
- [fanout-symbol-after-1.log](evidence/021-fanout-created-before-source-port-initialization/fanout-symbol-after-1.log) — original `evidence/R3/fanout-symbol-after-1.log`
- [fanout-symbol-after.log](evidence/021-fanout-created-before-source-port-initialization/fanout-symbol-after.log) — original `evidence/R3/fanout-symbol-after.log`
- [fanout-sheets-regression.log](evidence/021-fanout-created-before-source-port-initialization/fanout-sheets-regression.log) — original `evidence/R3/fanout-sheets-regression.log`
- [repro-fanout-later-custom-symbol.test.tsx](evidence/021-fanout-created-before-source-port-initialization/repro-fanout-later-custom-symbol.test.tsx) — original `tooling/core/tests/repros/repro-fanout-later-custom-symbol.test.tsx`
- [A_2N7002.tsx](evidence/021-fanout-created-before-source-port-initialization/A_2N7002.tsx) — original `tooling/core/tests/fixtures/imported-r3/A_2N7002.tsx`
- [MSK12C02.tsx](evidence/021-fanout-created-before-source-port-initialization/MSK12C02.tsx) — original `tooling/core/tests/fixtures/imported-r3/MSK12C02.tsx`

Original files remain in their listed paths. No unavailable screenshot or physical test is claimed reviewed. The board/schema inputs are unmodified; only canonical generator/source fixes are made.

## 7. Root cause: confirmed facts and hypotheses

Confirmed: CreateAutoplacedBreakoutPoints originally precedes source rendering, port matching and alias initialization. It reads those outputs. Its new position is after SourceAddConnectivityMapKey. No hypothesis is needed for the reproduced ordering failure.

## 8. Impact

Blocks circuit generation when a fanout scans traces belonging to supplier custom symbols.

## 9. Fix details, changed source and tests

tooling/core/lib/components/base-components/Renderable.ts; regression tests/repros/repro-fanout-later-custom-symbol.test.tsx. Test passes after the phase move. Cross-sheet and cache invalidation failures are separate reports 022/023.

## 10. Verification and remaining blocker

Keep local source patches, untracked regression fixtures, dependency locks and the linked evidence together. Whole-board fabrication remains blocked independently of the individual fixed reports. Battery, thermal, RF, physical fit and phone tests remain pending. No packages, GitHub reports, supplier questions or assembly orders were published.

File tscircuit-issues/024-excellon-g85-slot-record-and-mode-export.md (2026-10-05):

# USB plated slots export as ambiguous separate G85 records

Status: **fixed locally**. Classification: **tscircuit manufacturing exporter defect**.

## 1. Affected package and exact revision

circuit-json-to-gerber 0.0.104 bundled in CLI 0.1.2212; 0.0.109 base 40dbb6c0ebae9c63ef5a52292e8521de6060c548 also has the slot-record defect. Working dependency archives/locks are kept in `tooling/vendor/` and the board manifest. Fixed locally never means published upstream.

## 2. Components and sources

GCT USB4105-GF-A-120 / C5184243 (R2); XUNPU TYPEC-250Y-BRP6L68 / C5252714 (R3).

- [Core source](https://github.com/tscircuit/core/tree/3fcbb3842b8ab1c0af324078f6eb55c3dbcba1a0)
- [Gerber converter source](https://github.com/tscircuit/circuit-json-to-gerber/tree/40dbb6c0ebae9c63ef5a52292e8521de6060c548)
- [JLCPCB C431540](https://jlcpcb.com/partdetail/C431540), [C8545](https://jlcpcb.com/partdetail/C8545), [C5184243](https://jlcpcb.com/partdetail/C5184243), [C5252714](https://jlcpcb.com/partdetail/C5252714)
- [Excellon programming manual](https://static1.squarespace.com/static/54982a02e4b02e9f5e5d9ca7/t/577e77209f74568b965f785e/1467905825798/Excellon%2BAutomation%2BCo.pdf)
- [KiCad Excellon reader source](https://docs.kicad.org/doxygen/excellon__read__drill__file_8cpp_source.html)

## 3. Minimal reproduction and required inputs

Run test commands from the identified tooling package directory; project build/converter commands from the board root. Install the retained package lock with Bun 1.3.9. Imported fixture files retain their supplier source geometry. Before logs identify actually reproduced failures, not guessed upstream outcomes.

```sh
bun test tests/excellon-drill/independent-g85-slot-records.test.ts
# Board root, after supported converter build:
bun tooling/circuit-json-to-gerber/dist/cli.js evidence/R3/R2-inputs/dist/index/circuit.json -o evidence/R3/R2-regenerated-slot-fix.zip
tooling/gerber-review-venv/bin/python scripts/inspect-exported-slots.py evidence/R3/R2-regenerated-slot-fix.zip evidence/R3/R2-inputs/dist/index/circuit.json --output evidence/R3/R2-slot-export-independent.json
```

## 4. Expected behavior

Excellon G85 start and end coordinates belong on one record. Restore G05 drill mode after the slot. Original Excellon programming manual and KiCad parser support this form. Supplier slot dimensions must be preserved.

## 5. Actual behavior

Separate XstartYstart and G85XendYend records, with no G05 return. KiCad Gerber Viewer renders long zigzag cuts between USB slots and later via locations. Numeric endpoint-only review missed this interpretation failure.

## 6. Evidence

- [R2-g85-reader-before.png](evidence/024-excellon-g85-slot-record-and-mode-export/R2-g85-reader-before.png) — original `evidence/R3/R2-g85-reader-before.png`
- [gerber-slot-before.log](evidence/024-excellon-g85-slot-record-and-mode-export/gerber-slot-before.log) — original `evidence/R3/gerber-slot-before.log`
- [gerber-slot-after.log](evidence/024-excellon-g85-slot-record-and-mode-export/gerber-slot-after.log) — original `evidence/R3/gerber-slot-after.log`
- [gerber-drill-regression.log](evidence/024-excellon-g85-slot-record-and-mode-export/gerber-drill-regression.log) — original `evidence/R3/gerber-drill-regression.log`
- [gerber-full-regression.log](evidence/024-excellon-g85-slot-record-and-mode-export/gerber-full-regression.log) — original `evidence/R3/gerber-full-regression.log`
- [gerber-snapshot-baseline.log](evidence/024-excellon-g85-slot-record-and-mode-export/gerber-snapshot-baseline.log) — original `evidence/R3/gerber-snapshot-baseline.log`
- [R2-slot-export-independent.json](evidence/024-excellon-g85-slot-record-and-mode-export/R2-slot-export-independent.json) — original `evidence/R3/R2-slot-export-independent.json`
- [R2-slot-export-independent.log](evidence/024-excellon-g85-slot-record-and-mode-export/R2-slot-export-independent.log) — original `evidence/R3/R2-slot-export-independent.log`
- [independent-g85-slot-records.test.ts](evidence/024-excellon-g85-slot-record-and-mode-export/independent-g85-slot-records.test.ts) — original `tooling/circuit-json-to-gerber/tests/excellon-drill/independent-g85-slot-records.test.ts`
- [inspect-exported-slots.py](evidence/024-excellon-g85-slot-record-and-mode-export/inspect-exported-slots.py) — original `scripts/inspect-exported-slots.py`

Original files remain in their listed paths. No unavailable screenshot or physical test is claimed reviewed. The board/schema inputs are unmodified; only canonical generator/source fixes are made.

## 7. Root cause: confirmed facts and hypotheses

Confirmed: KiCad source DRILL_G_SLOT sets slot mode for standalone G85; its coordinate handler handles inline G85. The converter emitted the standalone form. Local correction emits XstartYstartG85XendYend followed by G05, preserving start/end geometry. It uses four decimal places for both endpoints.

## 8. Impact

Unsafe drill-file interpretation; manufacturing approval was blocked. Not a supplier footprint error.

## 9. Fix details, changed source and tests

src/excellon-drill/commands/G85.ts and convert-soup-to-excellon-drill-commands.ts. tests/excellon-drill/independent-g85-slot-records.test.ts uses the unmodified failing real-board Circuit JSON. Drill suite: 35 passes/127 assertions. Independent pcb-tools 0.1.6 reads all four regenerated R2 slots and matches source within exporter quantization. Full suite: 170 passes and two changed visual snapshots under investigation; no snapshots accepted merely to pass. Mac lock prevents post-fix KiCad screenshot for now.

## 10. Verification and remaining blocker

Keep local source patches, untracked regression fixtures, dependency locks and the linked evidence together. Whole-board fabrication remains blocked independently of the individual fixed reports. Battery, thermal, RF, physical fit and phone tests remain pending. No packages, GitHub reports, supplier questions or assembly orders were published.

## Final R3 disposition (2026-10-02)

Canonical full Gerber suite: 172 pass, 0 fail, 1640 assertions; reviewed changed snapshots. [Full log](../evidence/R3/gerber-full-regression-reviewed.log). Final source/export readback verifies all slots and round drills.

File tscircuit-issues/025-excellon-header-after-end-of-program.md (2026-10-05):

# Excellon header marker appears after the end of the drill program

Status: **verified fixed upstream**. Classification: **tscircuit exporter defect fixed in upstream release**.

## 1. Affected package and exact revision

circuit-json-to-gerber 0.0.104 bundled in CLI 0.1.2212; corrected in 0.0.109 base 40dbb6c0ebae9c63ef5a52292e8521de6060c548. Working dependency archives/locks are kept in `tooling/vendor/` and the board manifest. Fixed locally never means published upstream.

## 2. Components and sources

R2 original drill exports; affects every fitted connector/drilled feature, not one part.

- [Core source](https://github.com/tscircuit/core/tree/3fcbb3842b8ab1c0af324078f6eb55c3dbcba1a0)
- [Gerber converter source](https://github.com/tscircuit/circuit-json-to-gerber/tree/40dbb6c0ebae9c63ef5a52292e8521de6060c548)
- [JLCPCB C431540](https://jlcpcb.com/partdetail/C431540), [C8545](https://jlcpcb.com/partdetail/C8545), [C5184243](https://jlcpcb.com/partdetail/C5184243), [C5252714](https://jlcpcb.com/partdetail/C5252714)
- [Excellon programming manual](https://static1.squarespace.com/static/54982a02e4b02e9f5e5d9ca7/t/577e77209f74568b965f785e/1467905825798/Excellon%2BAutomation%2BCo.pdf)
- [KiCad Excellon reader source](https://docs.kicad.org/doxygen/excellon__read__drill__file_8cpp_source.html)

## 3. Minimal reproduction and required inputs

Run test commands from the identified tooling package directory; project build/converter commands from the board root. Install the retained package lock with Bun 1.3.9. Imported fixture files retain their supplier source geometry. Before logs identify actually reproduced failures, not guessed upstream outcomes.

```sh
unzip -p fabrication/R2-gerbers-review.zip drill-L1-L2.drl
unzip -p evidence/R3/R2-regenerated-slot-fix.zip drill-L1-L2.drl
```

## 4. Expected behavior

M48 begins the Excellon header before tool definitions. M30 ends the program. The header must not follow M30.

## 5. Actual behavior

Original R2 native file ends M30M48 and has no initial M48. Independent readers warn about header ordering.

## 6. Evidence

- [R2-slot-export-independent.json](evidence/025-excellon-header-after-end-of-program/R2-slot-export-independent.json) — original `evidence/R3/R2-slot-export-independent.json`
- [R2-slot-export-independent.log](evidence/025-excellon-header-after-end-of-program/R2-slot-export-independent.log) — original `evidence/R3/R2-slot-export-independent.log`
- [gerber-drill-regression.log](evidence/025-excellon-header-after-end-of-program/gerber-drill-regression.log) — original `evidence/R3/gerber-drill-regression.log`

Original files remain in their listed paths. No unavailable screenshot or physical test is claimed reviewed. The board/schema inputs are unmodified; only canonical generator/source fixes are made.

## 7. Root cause: confirmed facts and hypotheses

Confirmed original exported bytes. The 0.0.109 converter adds M48 at the beginning. This release is preferred as the base instead of locally recreating the upstream correction. Separate G85 correction is tracked in 024.

## 8. Impact

Ambiguous/invalid drill header ordering; independent CAM acceptance blocked.

## 9. Fix details, changed source and tests

No local M48 patch. Upstream src/excellon-drill/convert-soup-to-excellon-drill-commands.ts starts builder.add("M48",{}). The regenerated supported CLI export starts M48 and the independent reader parses it successfully.

## 10. Verification and remaining blocker

Keep local source patches, untracked regression fixtures, dependency locks and the linked evidence together. Whole-board fabrication remains blocked independently of the individual fixed reports. Battery, thermal, RF, physical fit and phone tests remain pending. No packages, GitHub reports, supplier questions or assembly orders were published.

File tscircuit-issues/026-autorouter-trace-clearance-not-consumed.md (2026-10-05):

# Declared autorouter traceClearance does not affect native routing input

Status: **confirmed**. Classification: **confirmed unused configuration; intended API semantics need upstream confirmation**.

## 1. Affected package and exact revision

@tscircuit/core 0.0.2035; base 3fcbb3842b8ab1c0af324078f6eb55c3dbcba1a0; @tscircuit/props 0.0.672; capacity-autorouter 0.0.941/0.0.951 evaluated. Working dependency archives/locks are kept in `tooling/vendor/` and the board manifest. Fixed locally never means published upstream.

## 2. Components and sources

All fitted parts; independent of supplier component data.

- [Core source](https://github.com/tscircuit/core/tree/3fcbb3842b8ab1c0af324078f6eb55c3dbcba1a0)
- [Gerber converter source](https://github.com/tscircuit/circuit-json-to-gerber/tree/40dbb6c0ebae9c63ef5a52292e8521de6060c548)
- [JLCPCB C431540](https://jlcpcb.com/partdetail/C431540), [C8545](https://jlcpcb.com/partdetail/C8545), [C5184243](https://jlcpcb.com/partdetail/C5184243), [C5252714](https://jlcpcb.com/partdetail/C5252714)
- [Excellon programming manual](https://static1.squarespace.com/static/54982a02e4b02e9f5e5d9ca7/t/577e77209f74568b965f785e/1467905825798/Excellon%2BAutomation%2BCo.pdf)
- [KiCad Excellon reader source](https://docs.kicad.org/doxygen/excellon__read__drill__file_8cpp_source.html)

## 3. Minimal reproduction and required inputs

Run test commands from the identified tooling package directory; project build/converter commands from the board root. Install the retained package lock with Bun 1.3.9. Imported fixture files retain their supplier source geometry. Before logs identify actually reproduced failures, not guessed upstream outcomes.

```sh
rg -n traceClearance node_modules/@tscircuit/props/lib/components/group.ts
rg -n trace_clearance tooling/core/lib
```

## 4. Expected behavior

A supported public clearance setting must either control routing or explicitly report that it is unsupported. Board manufacturing rules must ultimately be checked against actual copper.

## 5. Actual behavior

Changing autorouter.traceClearance from 0.25 to 0.15 mm leaves the native input/geometry unchanged. The typed property is stored as source_group.trace_clearance but no native SRJ reader consumes that field.

## 6. Evidence

- [routed-build-1.log](evidence/026-autorouter-trace-clearance-not-consumed/routed-build-1.log) — original `evidence/R3/routed-build-1.log`
- [routed-build-2.log](evidence/026-autorouter-trace-clearance-not-consumed/routed-build-2.log) — original `evidence/R3/routed-build-2.log`

Original files remain in their listed paths. No unavailable screenshot or physical test is claimed reviewed. The board/schema inputs are unmodified; only canonical generator/source fixes are made.

## 7. Root cause: confirmed facts and hypotheses

Confirmed source declaration/storage and observed unchanged output. Not a cache-key defect: the SRJ did not change. Hypothesis: intended native clearance propagation was omitted. Supported board minTraceToPadEdgeClearance is consumed separately, but does not establish a blanket track-to-track rule.

## 8. Impact

Misleading configuration can prevent engineers from reasoning about actual routing clearances. Changing settings alone never establishes manufacturing compliance.

## 9. Fix details, changed source and tests

No source patch to silently redefine the setting. Actual output checks stay enabled; tests/MRE and a supported API decision remain to be completed.

## 10. Verification and remaining blocker

Keep local source patches, untracked regression fixtures, dependency locks and the linked evidence together. Whole-board fabrication remains blocked independently of the individual fixed reports. Battery, thermal, RF, physical fit and phone tests remain pending. No packages, GitHub reports, supplier questions or assembly orders were published.

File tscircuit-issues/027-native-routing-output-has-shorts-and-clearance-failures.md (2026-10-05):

# Native routing returns copper with real shorts and manufacturing clearance failures

Status: **suspected**. Classification: **observed failed output; algorithm root cause not established**.

## 1. Affected package and exact revision

@tscircuit/core 0.0.2035 local R3 patches; capacity-autorouter 0.0.951; beta_pipeline9. Working dependency archives/locks are kept in `tooling/vendor/` and the board manifest. Fixed locally never means published upstream.

## 2. Components and sources

37 fitted references / 24 verified C-numbers; see project BOM.csv and unchanged imports.

- [Core source](https://github.com/tscircuit/core/tree/3fcbb3842b8ab1c0af324078f6eb55c3dbcba1a0)
- [Gerber converter source](https://github.com/tscircuit/circuit-json-to-gerber/tree/40dbb6c0ebae9c63ef5a52292e8521de6060c548)
- [JLCPCB C431540](https://jlcpcb.com/partdetail/C431540), [C8545](https://jlcpcb.com/partdetail/C8545), [C5184243](https://jlcpcb.com/partdetail/C5184243), [C5252714](https://jlcpcb.com/partdetail/C5252714)
- [Excellon programming manual](https://static1.squarespace.com/static/54982a02e4b02e9f5e5d9ca7/t/577e77209f74568b965f785e/1467905825798/Excellon%2BAutomation%2BCo.pdf)
- [KiCad Excellon reader source](https://docs.kicad.org/doxygen/excellon__read__drill__file_8cpp_source.html)

## 3. Minimal reproduction and required inputs

Run test commands from the identified tooling package directory; project build/converter commands from the board root. Install the retained package lock with Bun 1.3.9. Imported fixture files retain their supplier source geometry. Before logs identify actually reproduced failures, not guessed upstream outcomes.

```sh
bun run build
bun scripts/check-routed.ts
tooling/gerber-review-venv/bin/python scripts/manufacturing-audit.py --output evidence/R3/routed-manufacturing.json
```

## 4. Expected behavior

Every required connection must be routed without shorts or clearance violations. The project cannot be a prototype fabrication candidate until native and independent checks pass.

## 5. Actual behavior

Route attempt 10: 83 native error records (27 trace, 17 via-to-trace, 15 pad-to-trace, 14 pad-to-pad, 8 placement, 2 via clearance). Classified independent audit reports 90 failures, including zero-distance copper intersections and vias under unrelated pads.

## 6. Evidence

- [remote-circuit.tsx](evidence/027-native-routing-output-has-shorts-and-clearance-failures/remote-circuit.tsx) — original `evidence/R3/route-attempt-10/remote-circuit.tsx`
- [circuit.json](evidence/027-native-routing-output-has-shorts-and-clearance-failures/circuit.json) — original `evidence/R3/route-attempt-10/circuit.json`
- [routed-build-10-radio-escape.log](evidence/027-native-routing-output-has-shorts-and-clearance-failures/routed-build-10-radio-escape.log) — original `evidence/R3/routed-build-10-radio-escape.log`
- [routed-manufacturing-10.log](evidence/027-native-routing-output-has-shorts-and-clearance-failures/routed-manufacturing-10.log) — original `evidence/R3/routed-manufacturing-10.log`
- [routed-manufacturing-10.json](evidence/027-native-routing-output-has-shorts-and-clearance-failures/routed-manufacturing-10.json) — original `evidence/R3/routed-manufacturing-10.json`

Original files remain in their listed paths. No unavailable screenshot or physical test is claimed reviewed. The board/schema inputs are unmodified; only canonical generator/source fixes are made.

## 7. Root cause: confirmed facts and hypotheses

Confirmed generated failures; not all are merely a strict-threshold disagreement. Scope includes routing configuration, placement, preloaded escape handling and solver output. Hypotheses must not be labeled confirmed tscircuit bugs. Supplier imports and generated output were not patched.

## 8. Impact

Blocks copper validation and fabrication-candidate status. All electronics still on top; two copper layers do not imply two-sided assembly.

## 9. Fix details, changed source and tests

No claimed fix. Original attempt 10 source/JSON and logs retained. Other documented native pipelines are being evaluated. Independent checks are neither weakened nor bypassed.

## 10. Verification and remaining blocker

Keep local source patches, untracked regression fixtures, dependency locks and the linked evidence together. Whole-board fabrication remains blocked independently of the individual fixed reports. Battery, thermal, RF, physical fit and phone tests remain pending. No packages, GitHub reports, supplier questions or assembly orders were published.

## Final R3 disposition (2026-10-02)

Earlier failing copper remains preserved. Actual source integration fixes (028, 031, 035) plus native board escape/placement choices and 0.25 mm automatic via drills yield zero native errors and zero classified manufacturing failures in attempt 33. This does not establish a generic autorouter algorithm fix. No physical component or supplier footprint changed to hide clearance violations.

## R5 reproduced trials and final disposition

Ground-plane trials reserving an unbroken BOTTOM patch rerouted signals and emitted actual via/pad/ordinary-hole violations. [Trial evidence](../evidence/R5/solid-ep-first-routed/), [later reservation failure](../evidence/R5/routed-final-build.log), [current source](../src/remote-circuit.tsx). Responsible routing algorithm/root cause remains unconfirmed. R5 keeps solid TOP and BOTTOM GND pours with a native TOP charger region; it does not force an unnecessary unbroken BOTTOM projection. Original router minimums are retained, and the final routed/native and independent source/CAM checks have zero failures. [Full final suite](../evidence/R5/suite-exits.json), [copper audit](../evidence/R5/copper-audit.json), [ground proof](../evidence/R5/ground-plane-review.json). No error records, geometry or thresholds were patched to pass.

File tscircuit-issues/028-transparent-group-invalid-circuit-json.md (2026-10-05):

# Transparent groups emit schema-invalid Circuit JSON

Status: **fixed locally**. Full routed board validation remains separate.

## Affected package
`@tscircuit/core` 0.0.2035, upstream base `3fcbb3842b8ab1c0af324078f6eb55c3dbcba1a0`, with the retained project fixes. `circuit-json` 0.0.509. Local source: `../tooling/core/`.

## Components and sources
The regression uses unchanged supplier imports: Jiangsu Changjing Electronics Technology 2N7002, C8545, and SHOU HAN MSK12C02, C431540. [C8545](https://jlcpcb.com/partdetail/C8545), [C431540](https://jlcpcb.com/partdetail/C431540). This failure is group metadata, independent of electronic land geometry.

## Reproduction
From `tooling/core`, run `bun test tests/repros/repro-fanout-schematic-group-schema.test.tsx` and `bun test tests/repros/repro-group-autorouter-configuration-schema.test.tsx`. Required fixtures are retained in `tests/fixtures/imported-r3/`. [Minimal source](evidence/028/repro-fanout-schematic-group-schema.test.tsx). The board has two native A4 schematic sheets, an explicit-position transparent fanout, and an unchanged imported transistor and switch.

## Expected behavior
All emitted records must pass `any_circuit_element.array().safeParse(...)`. Transparent groups inherit the owning subcircuit. Circuit JSON declares string optional subcircuit IDs, non-null anchor alignment, optional autorouter configuration containing required numeric trace clearance, and string display offsets. [Schema source](https://github.com/tscircuit/circuit-json/blob/main/src/pcb/pcb_group.ts).

## Actual behavior and evidence
The first failure emits a null schematic subcircuit ID. PCB records also emit null anchor alignment and empty `{}` autorouter configuration. Explicit numeric `pcbX/pcbY` produce numeric display offsets although the schema requires strings. [Original failure](evidence/028/group-schema-before.log), [additional failure](evidence/028/group-schema-after-3.log), [numeric offset record](evidence/028/schema-rejected-routed-records.log).

## Root cause
Confirmed: Group reads its own unset subcircuit ID; unset alignment is explicitly replaced with null; presence of the autorouter object is mistaken for presence of its trace-clearance field; raw numeric coordinate inputs are stored in string-only presentation fields. These facts follow directly from canonical Group source and the rejected generated records. Supplier data is not implicated.

## Impact
Strict schema validation blocks trusting fabrication converters; ownership metadata may also affect schematic grouping. Board copper and component imports are not modified by the fix.

## Local fix and verification
Changed `lib/components/primitive-components/Group/Group.ts`: use the actual owning subcircuit; omit unset alignment; emit autorouter configuration only when trace clearance is supplied; stringify present display offsets. Defaults remain the schema's documented defaults. Explicit trace clearance is preserved in its own regression. [Two schema regressions](evidence/028/group-schema-numeric-offset-after.log), [five related regressions](evidence/028/group-schema-regression-final.log). Core TypeScript and build completed successfully; current integration uses a uniquely named local archive to avoid Bun archive-cache reuse. No generated imports or JSON were patched. No upstream issue or package was published.

## Final R3 disposition (2026-10-02)

Final complete source Circuit JSON schema accepts every record; tested canonical/installed core builds match. Working local archive is r3-attribution.tgz, preserving the transparent-group source fix.

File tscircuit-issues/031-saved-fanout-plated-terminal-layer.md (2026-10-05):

# Saved fanout rejects a valid bottom-layer escape from a through-plated terminal

Status: **fixed locally**.

## Affected package and exact revision

@tscircuit/core 0.0.2035; upstream base 3fcbb3842b8ab1c0af324078f6eb55c3dbcba1a0; working archive tscircuit-core-0.0.2035-r3-attribution.tgz.

## Component and authoritative sources

HCTL HC-TYPE-C-6P-01A / C2894893. [Listing](https://jlcpcb.com/partdetail/HC-TYPE-C-6P-01A/C2894893), [Rev A drawing](../references/C2894893-manufacturer.pdf), [unchanged imported test fixture](../tooling/core/tests/fixtures/imported-r3/HC_TYPE_C_6P_01A.tsx).

## Minimal reproduction, commands and required inputs

Run from the board root with the supplied locks, unless the command explicitly changes directory. Original failing artifacts are preserved; imported fixtures are unchanged supplier imports. No credentials or publishing are needed.

```sh
cd tooling/core
bun test tests/repros/repro-saved-fanout-plated-terminal-bottom.test.tsx tests/repros/repro-saved-fanout-smt-terminal-wrong-layer.test.tsx
node_modules/.bin/tsc --noEmit
bun run build
```

## Expected behavior

An actual top/bottom plated terminal can anchor copper on either declared physical layer at its same physical coordinate. A top-only SMT terminal must still reject a bottom start without a via.

## Actual behavior

The original saved-path endpoint matcher only accepted the SRJ terminal preferred layer (top), although the physical port/slot spans top and bottom. The valid shell bottom escape failed endpoint selection.

## Logs, screenshots and measurements

[Original source](evidence/031/original-get-saved-fanout-traces.ts), [fixed source](evidence/031/fixed-get-saved-fanout-traces.ts), [observed before failure](evidence/031/before.log), [10-pass focused regression](../evidence/R3/core-pth-fanout-broad.log), [typecheck](../evidence/R3/core-pth-typecheck-2.log), [reviewed PCB snapshot](../evidence/R3/repro-saved-fanout-plated-terminal-bottom-pcb.png).

## Root cause: confirmed facts and hypotheses

Confirmed preferred SRJ layer was mistaken for the physical barrel layer span. The imported slot/layer data is correct.

## Impact

Prevents real grounded USB shell routing on bottom without an unnecessary extra via.

## Fix details, changed source and regression tests

Changed lib/components/primitive-components/Breakout/get-saved-fanout-traces.ts. Accept the alternate layer only for the same endpoint/port that has an actual pcb_plated_hole with both declared layers. Added positive PTH and negative SMT regression fixtures, snapshots, typecheck/build. No same-footprint DRC exemption and no new fabricated via.

## Verification and remaining blocker

Final board evidence is in [R3 validation](../VALIDATION.md), [native checks](../evidence/R3/final-check-exits.json), [clearance audit](../evidence/R3/routed-manufacturing-33.json), and [complete fabrication readback](../evidence/R3/final-cam-readback/readback.json). These are software results. Assembly stencil/shell process approval and physical battery, thermal, RF, fit and phone tests remain open. No issue, package or design was published.

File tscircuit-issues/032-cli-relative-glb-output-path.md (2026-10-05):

# Relative GLB output is resolved under the input directory

Status: **suspected**.

## Affected package and exact revision

@tscircuit/cli 0.1.2212 bundled by tscircuit 0.0.2702.

## Component and authoritative sources

No specific supplier component. [CLI](https://github.com/tscircuit/cli).

## Minimal reproduction, commands and required inputs

Run from the board root with the supplied locks, unless the command explicitly changes directory. Original failing artifacts are preserved; imported fixtures are unchanged supplier imports. No credentials or publishing are needed.

```sh
node_modules/.bin/tsci export dist/index/circuit.json --format glb --output dist/index/board.glb
# Explicit absolute output is unambiguous:
node_modules/.bin/tsci export dist/index/circuit.json --format glb --output "$PWD/dist/index/board.glb"
```

## Expected behavior

An explicitly supplied relative output needs a clear documented base directory. The user should not receive apparent output success when no file exists.

## Actual behavior

Error writing file: Error: ENOENT: no such file or directory, open dist/index/dist/index/board.glb. Absolute output generated an actual current 5.4 MiB GLB.

## Logs, screenshots and measurements

[Observed failure](../evidence/R3/R3-export-glb.log), [supported help](../evidence/R3/export-help.txt), [absolute-output success](../evidence/R3/final-export-glb.log), [actual GLB](../dist/index/board.glb).

## Root cause: confirmed facts and hypotheses

Confirmed observed nested path. Whether input-relative output is intended CLI semantics remains unresolved; not classified as a confirmed exporter geometry bug.

## Impact

Missing/stale 3D output may be mistaken for the current revision.

## Fix details, changed source and regression tests

Use the supported absolute output argument. No package patch or geometry workaround. New GLB generated, file existence checked, and native 3D inspected.

## Verification and remaining blocker

Final board evidence is in [R3 validation](../VALIDATION.md), [native checks](../evidence/R3/final-check-exits.json), [clearance audit](../evidence/R3/routed-manufacturing-33.json), and [complete fabrication readback](../evidence/R3/final-cam-readback/readback.json). These are software results. Assembly stencil/shell process approval and physical battery, thermal, RF, fit and phone tests remain open. No issue, package or design was published.

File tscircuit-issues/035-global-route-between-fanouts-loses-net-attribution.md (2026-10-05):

# Global route between saved fanout exits loses source-trace attribution

Status: **fixed locally**.

## Affected package and exact revision

@tscircuit/core 0.0.2035; base 3fcbb3842b8ab1c0af324078f6eb55c3dbcba1a0; capacity-autorouter 0.0.951.

## Component and authoritative sources

Reduced regression uses unchanged Samsung CL10A475KO8NNNC / C19666 imports. [Listing](https://jlcpcb.com/partdetail/C19666), [fixture](../tooling/core/tests/fixtures/imported-r3/CL10A475KO8NNNC.tsx). Original board TEMP_OK net includes TI TMP390A2DRLR / C5219772, [TI datasheet](https://www.ti.com/lit/ds/symlink/tmp390.pdf).

## Minimal reproduction, commands and required inputs

Run from the board root with the supplied locks, unless the command explicitly changes directory. Original failing artifacts are preserved; imported fixtures are unchanged supplier imports. No credentials or publishing are needed.

```sh
cd tooling/core
bun test tests/repros/repro-routed-trace-between-saved-fanouts.test.tsx
node_modules/.bin/tsc --noEmit
bun run build
```

## Expected behavior

Actual solver connectsTo identifiers must resolve physical PCB ports or recorded breakout points to their real source terminal/net, including a route that has no physical pad at either global endpoint.

## Actual behavior

The route between two saved exits had no source_trace_id. Native DRC reported false accidental contacts and dangling endpoints; the independent checker also failed because the net was unknown.

## Logs, screenshots and measurements

[Original source](evidence/035/original-attribution.ts), [fixed source](evidence/035/fixed-attribution.ts), [before regression failure](evidence/035/before.log), [9-pass focused regressions](../evidence/R3/core-attribution-broad.log), [typecheck](../evidence/R3/core-attribution-typecheck.log), [reviewed snapshot](../evidence/R3/repro-routed-trace-between-saved-fanouts-pcb.png).

## Root cause: confirmed facts and hypotheses

Confirmed function only used geometric/start/end pad inference, ignoring solver connectsTo breakout IDs. Endpoint geometry already matched actual saved fanout exits.

## Impact

False connectivity errors and unsafe unknown-net interpretation downstream.

## Fix details, changed source and regression tests

Changed lib/components/primitive-components/Group/get-source-trace-id-for-routed-trace.ts. Model optional readonly connectsTo identifiers and resolve their actual db.pcb_port/db.pcb_breakout_point source-port records before geometric inference. Added a two-real-capacitor/four-saved-exit regression with zero native errors and a PCB snapshot. Nine relevant tests / 43 assertions, typecheck and build pass. Regenerated board through the canonical pipeline; no circuit JSON patch.

## Verification and remaining blocker

Final board evidence is in [R3 validation](../VALIDATION.md), [native checks](../evidence/R3/final-check-exits.json), [clearance audit](../evidence/R3/routed-manufacturing-33.json), and [complete fabrication readback](../evidence/R3/final-cam-readback/readback.json). These are software results. Assembly stencil/shell process approval and physical battery, thermal, RF, fit and phone tests remain open. No issue, package or design was published.

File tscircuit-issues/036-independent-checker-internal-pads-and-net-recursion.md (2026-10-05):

# Independent manufacturing checker missed internal port connections and physical pad junctions

Status: **fixed locally**.

## Affected package and exact revision

Project scripts/manufacturing-audit.py, R3 2026-10-02. This is a project checker defect, not a tscircuit defect.

## Component and authoritative sources

SHOUHAN MSK12C02 / C431540: four repeated shell lands are explicitly internally connected in the canonical model. UNI-ROYAL 0603WAF1621T5E / C22844 R10: two ground tracks share an actual SMT pad. [MSK drawing](../references/SHOUHAN-MSK12C02.pdf), [supported unchanged import](../imports/MSK12C02.tsx).

## Minimal reproduction, commands and required inputs

Run from the board root with the supplied locks, unless the command explicitly changes directory. Original failing artifacts are preserved; imported fixtures are unchanged supplier imports. No credentials or publishing are needed.

```sh
tooling/gerber-review-venv/bin/python -m unittest discover -s tests -v
tooling/gerber-review-venv/bin/python scripts/manufacturing-audit.py --input evidence/R3/route-attempt-29/circuit.json --output evidence/R3/repro-checker-route29.json
```

## Expected behavior

Resolve canonical explicit internal connections transitively and fail conflicting memberships. Separate same-net track spacing applies outside actual shared conductive pad geometry; remote parallel tracks remain checked. Unknown trace attribution must fail closed without recursion.

## Actual behavior

SW1 shell pad104 was falsely unconnected despite source_component_internal_connection recording its net. R10 tracks nominal gap .103366 mm share SMT pad138; outside actual pad, gap is .302911 mm (> .25). A source trace with no attribution recursed into itself. Two real via-to-pad failures were retained after classification repair.

## Logs, screenshots and measurements

[Original checker](../evidence/R3/manufacturing-audit-before-internal-pads.py), [original four findings](../evidence/R3/routed-manufacturing-29.json), [25-pass project/board regression log](../evidence/R3/checker-internal-pad-tests.log), [current zero-failure audit](../evidence/R3/routed-manufacturing-33.json).

## Root cause: confirmed facts and hypotheses

Confirmed project checker ignored explicit internal connectivity, classified only annuli as shared junctions, and followed an unattributed pcb_trace_id recursively. This does not imply an arbitrary same-footprint or same-net clearance exemption.

## Impact

False short/spacing findings, plus an unhelpful recursion failure hiding a separate core attribution defect (035).

## Fix details, changed source and regression tests

Changed only checker source and tests/test_manufacturing_audit.py. Internal connections are explicit model records, not matched by name/component; conflicting nets raise. Junction subtraction uses actual shared SMT/annular copper only, not a clearance envelope. Regression verifies remote parallel track violation still fails, same-footprint NPTH still fails, and unknown attribution fails precisely. All original manufacturing thresholds remain unchanged.

## Verification and remaining blocker

Final board evidence is in [R3 validation](../VALIDATION.md), [native checks](../evidence/R3/final-check-exits.json), [clearance audit](../evidence/R3/routed-manufacturing-33.json), and [complete fabrication readback](../evidence/R3/final-cam-readback/readback.json). These are software results. Assembly stencil/shell process approval and physical battery, thermal, RF, fit and phone tests remain open. No issue, package or design was published.

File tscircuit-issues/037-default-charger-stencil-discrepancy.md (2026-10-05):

# Default generated charger stencil differs from TI example

Status: **fixed locally** (R5; historical R4 failure retained below).

## R4 qualification correction — 2026-10-02

Current gate: **BLOCKED — SUPPLIER CONFIRMATION REQUIRED**. [Deeper official-TI qualification](../fabrication/CHARGER-STENCIL-QUALIFICATION.md) supersedes any implication below that exact equality to the DLH stencil example is mandatory. The dimensional difference is confirmed; an intrinsic tscircuit bug or physical solder failure is **not** established.

Latest SLUSF65B explicitly labels drawing 4226298/A as an example and references SLUA271C. That note adds process guidance for aperture release. Actual current leads calculate area ratio 0.39999967/aspect 1.12 at 0.125 mm, so approval of material, thickness, transfer and volume is the concrete unresolved concern. No universal default was modified.

The previous assertion that the example's reported 88% necessarily uses physical EP area was too definite and is withdrawn. Current rectangular paste area 0.661497690002 mm² is 49.00003578% of actual exported copper, 48.99982889% of the nominal physical bounding rectangle. The package chamfer is not dimensioned sufficiently to state exact metal area; the 88% caption does not define its denominator uniquely. Example bounding dimensions yield 86.88888889% against the nominal bounding pad, which is not silently rounded into a new physical nominal. [All per-aperture measurements and sensitivity calculations](../evidence/R4-qualification/qualification-audit.json). Existing original measurements/files below remain preserved as history.

## Affected package and exact revision

@tscircuit/core 0.0.2035 SmtPad default aperture scale 0.7; circuit-json-to-gerber 0.0.109 faithfully exports source apertures. Classification: confirmed design/process discrepancy; a universal core bug is not established.

## Component and authoritative sources

Texas Instruments BQ25185DLHR / C19725033. [TI datasheet and DLH stencil example](https://www.ti.com/lit/ds/symlink/bq25185.pdf), [saved PDF](../references/BQ25185.pdf). HCTL shell process is separate, [drawing](../references/C2894893-manufacturer.pdf).

## Minimal reproduction, commands and required inputs

Run from the board root with the supplied locks, unless the command explicitly changes directory. Original failing artifacts are preserved; imported fixtures are unchanged supplier imports. No credentials or publishing are needed.

```sh
node_modules/.bin/tsci build index.circuit.tsx --pcb-png --pcb-svgs --schematic-svgs --3d-png
bun tooling/circuit-json-to-gerber/dist/cli.js dist/index/circuit.json -o fabrication/R3-gerbers-review.zip
tooling/gerber-review-venv/bin/python scripts/review-r3-exports.py fabrication/R3-gerbers-review.zip dist/index/circuit.json --output-directory evidence/R3/final-cam-readback
```

## Expected behavior

Stencil geometry needs manufacturer/process qualification independent of correct copper geometry and faithful export. TI DLH example uses ten .2 × .5 mm lead apertures and exposed-pad .85 × 1.38 mm (88% physical-pad printed area), based on a .125 mm stencil. Board orientation rotates that EP rectangle by 90 degrees.

## Actual behavior

Actual ten lead apertures are .13999972 × .3499993 mm; EP is 1.0499979 × .62999874 mm. Automatic .7 linear scale gives 49% of copper-land area. Export exactly matches these source features. For .125 mm thickness, rectangular lead area/perimeter/thickness is .4, not evidence of adequate paste release.

## Logs, screenshots and measurements

[All source/export aperture measurements](../evidence/R3/final-cam-readback/readback.json), [actual source](../dist/index/circuit.json), [annotated review drawing](../fabrication/assembly-process-review.svg), [exact unsent questions](../fabrication/ASSEMBLY-REVIEW.md).

## Root cause: confirmed facts and hypotheses

Confirmed core hard-coded default reduction and manufacturer example differ. The supplier import has no qualified manufacturer-specific paste override. Whether a thinner/stepped/electropolished stencil could accept the default is unverified; do not assume assembler adjustment.

## Impact

Blocks stage 6 assembly-process approval; source copper/routing and CAM fidelity checks still pass. Physical reflow quality cannot be asserted.

## Fix details, changed source and regression tests

No supplier footprint, aperture, generated JSON or fabrication file manually patched. Manufacturer-specific supported stencil configuration or documented assembler stencil disposition is required. Exact discrepancy and questions prepared locally; no supplier/assembler contact. The generic default is recorded as a limitation rather than changed globally without evidence.

## Verification and remaining blocker

Final board evidence is in [R3 validation](../VALIDATION.md), [native checks](../evidence/R3/final-check-exits.json), [clearance audit](../evidence/R3/routed-manufacturing-33.json), and [complete fabrication readback](../evidence/R3/final-cam-readback/readback.json). These are software results. Assembly stencil/shell process approval and physical battery, thermal, RF, fit and phone tests remain open. No issue, package or design was published.

## R5 disposition (R4 report/evidence preserved)

Status: **fixed locally** for the project geometry/process strategy. 0.10 mm foil and 1:1 0.20 x 0.50 mm charger lead apertures give AR 0.714284 / aspect 1.999996. All 151 apertures pass the retained AR >=0.66 / aspect >=1.5 rules. EP coverage 67.407% is separately reported; R4's ~0.40 lead AR at 0.125 mm is not waived. [Per-aperture calculation](../evidence/R5/stencil-release.json). Actual paste transfer remains post-prototype; exact USB shell process remains open. Parent-style capability is tracked in 046; imported definitions are unmodified.

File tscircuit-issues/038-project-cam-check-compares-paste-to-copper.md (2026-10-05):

# Project CAM review incorrectly assumes solder paste equals SMT copper

Status: **fixed locally**. Classification: project checker mistake, not a tscircuit converter bug.

## Affected package and exact revision

Project `scripts/review-r3-exports.py`, R3 2026-10-02, exact final SHA in revision-manifest. Converter circuit-json-to-gerber 0.0.109 base `40dbb6c0ebae9c63ef5a52292e8521de6060c548` correctly exports explicit paste.

## Component and sources

TI BQ25185DLHR / C19725033 is a clear example, but the bad assumption affects all reduced apertures. [TI manufacturer stencil drawing](https://www.ti.com/lit/ds/symlink/bq25185.pdf), [saved datasheet](../references/BQ25185.pdf), [explicit final Circuit JSON](../dist/index/circuit.json). Actual stencil qualification discrepancy is separately tracked in 037.

## Minimal reproduction, exact commands and required inputs

From the board root:

```sh
tooling/gerber-review-venv/bin/python tscircuit-issues/evidence/038-paste-baseline/reproduce.py
bun run test
```

[Reproducer](evidence/038-paste-baseline/reproduce.py) uses unchanged current ZIP and circuit; it intentionally fails under the historical incorrect comparison. This is a preserved minimal failing assumption, not a claim to have retained a byte-identical early whole script.

## Expected behavior

Compare actual exported paste to explicit `pcb_solder_paste` geometry; check manufacturer/process suitability separately. Copper-to-paste equivalence is not a valid invariant.

## Actual behavior

Early full review raised `F_Paste.gbr does not match source copper: missing=81.18947314695694, extra=0.0 mm2`. The source has supported reduced apertures. Current reproducer records the same bad assumption against actual preserved inputs; no Gerber or JSON modification.

## Logs, screenshots and before/after measurements

[Replayed failing assumption](evidence/038-paste-baseline/reproduction.log), [actual aperture overlay](../fabrication/assembly-process-review.png), [passing source/export readback](../evidence/R3/final-cam-readback/readback.json). Actual TOP paste area 78.01379256 mm² matches explicit source 78.01378152 within the retained numerical comparison bound.

## Root-cause findings

Confirmed wrong expected baseline in project code. No converter failure is inferred. A reduced stencil may still be inappropriate for a particular manufacturer; that is a separate assembly qualification, not a reason to compare it to copper.

## Impact

False export-fidelity failure obscured the real manufacturer-specific stencil question. Corrected comparison does not grant stencil/process approval.

## Fix details, source files and regressions

`review-r3-exports.py` now uses explicit source paste records. `tests/test_export_readback.py` verifies reduced aperture matching, missing/extra stencil rejection, original G85 plus following round drilling and missing/incorrect drill data. Six focused cases pass; all 31 board tests pass. No numerical threshold or manufacturing rule changed.

## Verification and remaining blocker

All twelve final CAM files parse/match. Issue 037 still blocks charger stencil acceptance. Final evidence is indexed in [VALIDATION](../VALIDATION.md). No hardware, assembler approval, supplier contact, order or publication is implied.

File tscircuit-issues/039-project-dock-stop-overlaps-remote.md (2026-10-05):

# Project dock stop overlaps the docked remote envelope

Status: **fixed locally**. Classification: enclosure design mistake, not a tscircuit defect.

## Affected package and revision

Project mechanical/remote-and-grip.scad R2/R3, exact source hashes in revision manifests. OpenSCAD 2026.08.30 runtime used; final source/mesh logs retained. No electronic supplier geometry is involved.

## Component / authoritative dimensions

Original design: remote 60 mm long, dock centre Y=-42 mm, stop length 1.6 mm. These are engineering dimensions, not JJC internal measurements. [Schedule](../mechanical/dimensions.json). No JLC number applies to an externally printed enclosure.

## Minimal reproduction and commands

[Original isolated expression](evidence/039-dock-stop-overlap/before.scad); original full [R2 source](../evidence/R3/R2-inputs/mechanical/remote-and-grip.scad). From board root:

```sh
/opt/homebrew/bin/openscad -D 'part="grip"' -o mechanical/stl/grip.stl mechanical/remote-and-grip.scad
tooling/gerber-review-venv/bin/python scripts/check-mechanical-meshes.py
```

On this Mac OpenSCAD required normal host execution; sandbox abort evidence is retained. This is local CAD generation, not an external action.

## Expected behavior

Dock stop must leave the allocated 0.30 mm end gap at the intended retained remote position.

## Actual behavior

Original stop centre Y=-12 and 1.6 mm length gave near face -12.8; remote end is -12.0. An overlap of 0.8 mm existed. Manifold validity does not test this assembled interference.

## Evidence and before/after measurements

[Original/final dimensions](evidence/039-dock-stop-overlap/measurements.json), [actual final STL measurement](../evidence/R3/final-mechanical-mesh-measurements.json), [final mesh log](../evidence/R3/final-grip-mesh.log), [dock preview](../mechanical/docked-fit-r3.png), [dimensioned sheets](../mechanical/R3-dimensioned-drawings.pdf).

## Root cause

Confirmed placement at the remote end instead of beyond the end by half stop thickness plus the allocated gap. No CAD-kernel or tscircuit bug is inferred.

## Impact

Remote could not reach the calculated docking position without interference; earlier nominal dock dimensions were insufficient evidence.

## Fix / source / regression verification

Stop centre moved to -10.9 mm in SCAD and dimension schedule/drawing generator; regenerated actual grip STL. check-mechanical-meshes.py reads actual triangle vertices and fails if measured end gap differs from 0.30 mm by more than the documented decimal numerical bound. Actual measured gap 0.2999999955 mm, manifold NoError. No copper or imported electronic geometry changed.

## Remaining blocker

Physical printed fit, rail friction, retention, tolerance and drop tests pending. Final evidence is indexed in [VALIDATION](../VALIDATION.md). No hardware, assembler approval, supplier contact, order or publication is implied.

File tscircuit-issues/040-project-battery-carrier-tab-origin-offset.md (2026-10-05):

# Project carrier tab origin makes battery clearance asymmetric

Status: **fixed locally**. Classification: mechanical project design mistake, not a tscircuit defect.

## Affected package / exact revision

R3 mechanical/remote-and-grip.scad and dimensions.json, 2026-10-02. Final source hashes in revision-manifest. OpenSCAD geometry is external enclosure design; no footprint patch.

## Battery and sources

Externally installed DTP401525(PHR), supplier EEHD-53KN; documented maximum pack width 15.5 mm. [External part record](../EXTERNAL-PARTS.md), [manufacturer/pack specs](../references/DTP401525-PHR-v2.pdf). No JLC number applies to this battery.
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

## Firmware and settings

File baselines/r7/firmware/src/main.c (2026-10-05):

/* SPDX-License-Identifier: Apache-2.0 */
#include <errno.h>
#include <zephyr/kernel.h>
#include <zephyr/drivers/gpio.h>
#include <zephyr/settings/settings.h>
#include <zephyr/bluetooth/bluetooth.h>
#include <zephyr/bluetooth/conn.h>
#include <zephyr/bluetooth/hci.h>
#include <zephyr/bluetooth/uuid.h>
#include <zephyr/sys/atomic.h>
#include "hid.h"

static const struct gpio_dt_spec shutter = GPIO_DT_SPEC_GET(DT_ALIAS(sw0), gpios);
static const struct gpio_dt_spec pair = GPIO_DT_SPEC_GET(DT_ALIAS(sw1), gpios);
static const struct gpio_dt_spec led = GPIO_DT_SPEC_GET(DT_ALIAS(led0), gpios);
static struct gpio_callback button_callback;
K_SEM_DEFINE(button_event, 0, 1);
static atomic_t connected;
static atomic_t restart_advertising;
static bool advertising;
static bool pairing_window;
static bool bond_present;
static int bond_error;
static int64_t advertising_deadline;

static const struct bt_data advertising_payload[] = {
	BT_DATA_BYTES(BT_DATA_FLAGS, BT_LE_AD_GENERAL | BT_LE_AD_NO_BREDR),
	BT_DATA_BYTES(BT_DATA_UUID16_ALL, BT_UUID_16_ENCODE(BT_UUID_HIDS_VAL)),
	BT_DATA_BYTES(BT_DATA_GAP_APPEARANCE, 0x80, 0x01)
};
static const struct bt_data scan_payload[] = {
	BT_DATA(BT_DATA_NAME_COMPLETE, CONFIG_BT_DEVICE_NAME, sizeof(CONFIG_BT_DEVICE_NAME) - 1)
};

static void fault(void)
{
	for (;;) {
		gpio_pin_toggle_dt(&led);
		k_sleep(K_MSEC(100));
	}
}
static void button_irq(const struct device *port, struct gpio_callback *cb, uint32_t pins)
{
	ARG_UNUSED(port); ARG_UNUSED(cb); ARG_UNUSED(pins);
	k_sem_give(&button_event);
}
static void on_connected(struct bt_conn *conn, uint8_t err)
{
	if (err) { atomic_set(&restart_advertising, 1); return; }
	atomic_set(&connected, 1);
	if (bt_conn_set_security(conn, BT_SECURITY_L2)) {
		bt_conn_disconnect(conn, BT_HCI_ERR_AUTH_FAIL);
	}
}
static void on_disconnected(struct bt_conn *conn, uint8_t reason)
{
	ARG_UNUSED(conn); ARG_UNUSED(reason);
	atomic_clear(&connected);
	shutter_hid_disconnected();
	atomic_set(&restart_advertising, 1);
	k_sem_give(&button_event);
}
BT_CONN_CB_DEFINE(connection_callbacks) = {
	.connected = on_connected,
	.disconnected = on_disconnected,
};
static void add_bond(const struct bt_bond_info *bond, void *context)
{
	ARG_UNUSED(context);
	bond_present = true;
	int err = bt_le_filter_accept_list_add(&bond->addr);
	if (err) bond_error = err;
}
static int start_advertising(bool request_pairing)
{
	if (advertising) {
		int err = bt_le_adv_stop();
		if (err && err != -EALREADY) return err;
	}
	advertising = false;
	bond_present = false;
	bond_error = 0;
	int err = bt_le_filter_accept_list_clear();
	if (err) return err;
	bt_foreach_bond(BT_ID_DEFAULT, add_bond, NULL);
	if (bond_error) return bond_error;
	pairing_window = request_pairing || !bond_present;
	bt_set_bondable(pairing_window);
	struct bt_le_adv_param parameters = *BT_LE_ADV_CONN_FAST_1;
	if (!pairing_window) parameters.options |= BT_LE_ADV_OPT_FILTER_CONN;
	err = bt_le_adv_start(&parameters, advertising_payload, ARRAY_SIZE(advertising_payload),
		scan_payload, ARRAY_SIZE(scan_payload));
	if (!err) {
		advertising = true;
		advertising_deadline = k_uptime_get() + (pairing_window ? 120000 : 30000);
	}
	return err;
}
static void disconnect_peer(struct bt_conn *conn, void *context)
{
	ARG_UNUSED(context);
	bt_conn_disconnect(conn, BT_HCI_ERR_REMOTE_USER_TERM_CONN);
}

int main(void)
{
	if (!gpio_is_ready_dt(&led) || !gpio_is_ready_dt(&shutter) || !gpio_is_ready_dt(&pair)) return -ENODEV;
	if (gpio_pin_configure_dt(&led, GPIO_OUTPUT_INACTIVE)) return -EIO;
	if (gpio_pin_configure_dt(&shutter, GPIO_INPUT) || gpio_pin_configure_dt(&pair, GPIO_INPUT)) fault();
	gpio_init_callback(&button_callback, button_irq, BIT(shutter.pin) | BIT(pair.pin));
	if (gpio_add_callback(shutter.port, &button_callback) ||
		gpio_pin_interrupt_configure_dt(&shutter, GPIO_INT_EDGE_BOTH) ||
		gpio_pin_interrupt_configure_dt(&pair, GPIO_INT_EDGE_BOTH)) fault();
	if (bt_enable(NULL) || settings_load() || start_advertising(false)) fault();

	bool shutter_was_pressed = false;
	bool pair_was_pressed = false;
	bool pair_hold_handled = false;
	bool release_pending = false;
	bool pairing_requested = false;
	int64_t pair_pressed_at = 0;
	int64_t release_at = 0;
	int64_t led_off_at = 0;
	int64_t last_blink = 0;
	int64_t last_input_change = 0;
	int previous_raw = 0;

	for (;;) {
		int64_t now = k_uptime_get();
		if (atomic_cas(&restart_advertising, 1, 0)) {
			advertising = false;
			release_pending = false;
			if (pairing_requested && bt_unpair(BT_ID_DEFAULT, BT_ADDR_LE_ANY)) fault();
			if (start_advertising(pairing_requested)) fault();
			pairing_requested = false;
		}
		int shutter_raw = gpio_pin_get_dt(&shutter);
		int pair_raw = gpio_pin_get_dt(&pair);
		if (shutter_raw < 0 || pair_raw < 0) fault();
		int raw = shutter_raw | (pair_raw << 1);
		if (raw != previous_raw) { previous_raw = raw; last_input_change = now; }
		if (now - last_input_change >= 30) {
			bool shutter_pressed = raw & 1;
			bool pair_pressed = raw & 2;
			if (shutter_pressed && !shutter_was_pressed) {
				if (atomic_get(&connected) && !release_pending && shutter_hid_send(true) == 0) {
					release_pending = true;
					release_at = now + 60;
					gpio_pin_set_dt(&led, 1);
					led_off_at = now + 80;
				} else if (!atomic_get(&connected) && !advertising) {
					if (start_advertising(false)) fault();
				}
			}
			if (pair_pressed && !pair_was_pressed) { pair_pressed_at = now; pair_hold_handled = false; }
			if (pair_pressed && !pair_hold_handled && now - pair_pressed_at >= 3000) {
				pair_hold_handled = true;
				if (atomic_get(&connected)) {
					pairing_requested = true;
					bt_conn_foreach(BT_CONN_TYPE_LE, disconnect_peer, NULL);
				} else {
					if (advertising && bt_le_adv_stop()) fault();
					advertising = false;
					if (bt_unpair(BT_ID_DEFAULT, BT_ADDR_LE_ANY) || start_advertising(true)) fault();
				}
			}
			shutter_was_pressed = shutter_pressed;
			pair_was_pressed = pair_pressed;
		}
		if (release_pending && now >= release_at) {
			if (shutter_hid_send(false) == 0) release_pending = false;
			else if (now - release_at > 1000) {
				/* End a stalled link instead of leaving a pressed key latched. */
				bt_conn_foreach(BT_CONN_TYPE_LE, disconnect_peer, NULL);
				release_pending = false;
			}
		}
		if (advertising && !atomic_get(&connected) && now >= advertising_deadline) {
			if (bt_le_adv_stop()) fault();
			advertising = false;
			bt_set_bondable(false);
		}
		if (advertising && !atomic_get(&connected) && now - last_blink >= (pairing_window ? 500 : 2000)) {
			gpio_pin_set_dt(&led, 1); led_off_at = now + 30; last_blink = now;
		}
		if (now >= led_off_at) gpio_pin_set_dt(&led, 0);
		/* Interrupt wakes idle immediately. Poll briefly for debounce, pairing
		 * hold and release retry; otherwise sleep between status updates. */
		bool busy = raw || release_pending || now - last_input_change < 40 || now < led_off_at;
		k_sem_take(&button_event, busy ? K_MSEC(10) : K_MSEC(500));
	}
}

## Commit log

2026-10-04 Publish frozen R6 board and E1 enclosure with validated Circuit JSON
2026-10-04 Lock qualified build tooling and verify public R6 Circuit JSON
2026-10-05 Prepare R8 Cloud handoff with frozen baselines and pinned Linux setup
    [AL1793AFE_13.obj, AL1793AFE_13.step, AL8860WT_7.obj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]
